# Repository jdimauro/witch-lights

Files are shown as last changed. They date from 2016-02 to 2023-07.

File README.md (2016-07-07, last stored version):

# Witch Lights

The Witch Lights are an interactive light art installation, meant to be seen outdoors at night. 

The documentation and code are currently under construction, so they may change without notice. 

## Overview

This project creates a set of [ghostly lights][vid0], which come out of the woods when you approach them and jump from tree to tree. 

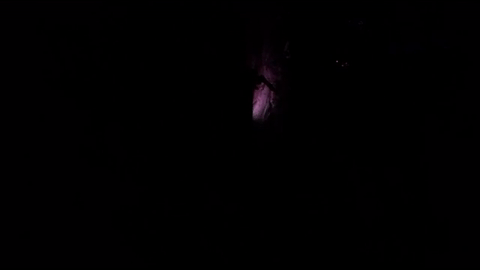
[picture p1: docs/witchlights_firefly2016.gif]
Animation Demo 1


Animation Demo 2

Imagine: as you walk through the unlit path, a tiny purple faerie jumps out of the underbrush, coiling about trees and floating overhead. It zips ahead of you, but pauses, flickering, while you catch up. It then takes off again, remaining always just out of reach, until you reach the end of their territory, where they vanish back into the woods. As you pass by where they disappeared, the lights jump out again, heading back the other way, daring you to chase them.

<iframe src="https://player.vimeo.com/video/153011114" width="500" height="889" frameborder="0" webkitallowfullscreen mozallowfullscreen allowfullscreen></iframe> 

[Here is a video][vid1] of an installation of the lights using a single five-meter LED strip (taken at twilight so that the hardware is visible):

[vid0]: https://vimeo.com/153011114#t=2s
[vid1]: https://vimeo.com/153011829

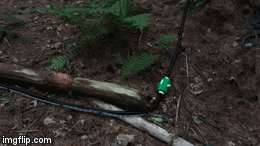
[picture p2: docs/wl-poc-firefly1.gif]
Proof of Concept - Firefly 2015


<iframe src="https://player.vimeo.com/video/153011829" width="500" height="281" frameborder="0" webkitallowfullscreen mozallowfullscreen allowfullscreen></iframe> 

The design of the lighting system is modular, so it can be used with any length of NeoPixel strip. The current configuration of the project uses five 30 pixel-per-meter NeoPixel strips, each one five meters long, for a total of 750 pixels. 

As you can see in the above video, the design uses waterproof conduit, connected to custom, modular connectors, which house the sensors and connect the NeoPixel strips to their power and data lines. 

At the beginning and end of the installation are passive infrared (PIR) motion sensors, which trigger the lights to appear and then zip away in the opposite direction of the triggered sensor. 

## Firefly 2016

The Witch Lights were exhibited at the Firefly Art Festival in Vermont, from June 29th through July 4th 2016. 

[Here is a video of the Witch Lights in action at the festival][vid2]. 

[vid2]: https://vimeo.com/173539041

### Photos

The lights were installed on a winding path through the woods, near the rear entrance to Library Camp. 

Electronics package and beginning of LED strips

The lights wound up around a tree, and then snaked through a tree stump.

Lights wrapped around tree stump

The conduit provides structure for the LED strips, and can be used to create spirals and loops in mid-air. 

Spiral segment of conduit and LEDs

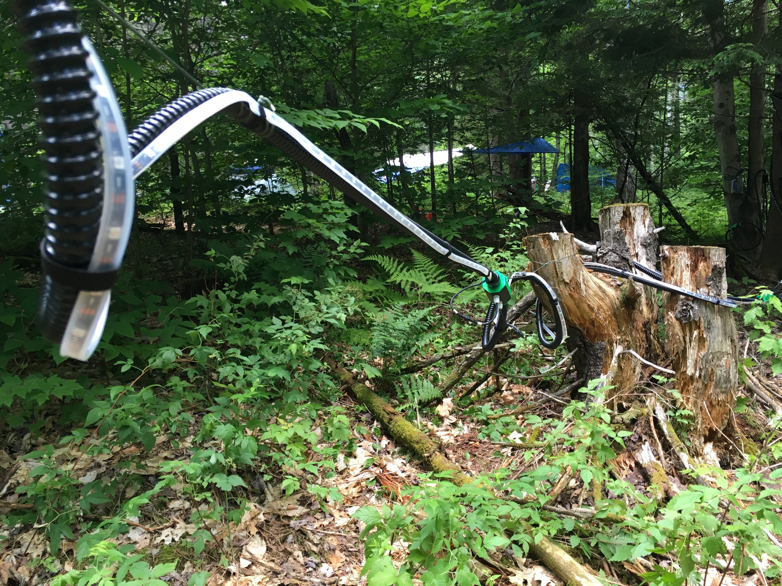
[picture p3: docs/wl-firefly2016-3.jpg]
Spiral and stump


The lights terminated by ducking behind a tree, so that they appear to hide behind a tree and vanish, or come out from behind the tree if activated by the motion sensor on this end (shown in green). 

Motion sensor and terminus

### Reception

The reaction to the Witch Lights was hugely enthusiastic and positive. Many attendees reported stopping and watching the lights, entranced, on their way through the path. Firefly's location feels like a magical forest, and the addition of a purple faerie that leads you down one of the paths felt like a natural thing to encounter in the dark. 

## Challenges

This is an advanced project. It involves building a weather resistant wire rig with 3D-printed sensor housings, which itself requires a great deal of soldering, assembly, cable pulling, and testing. The modular nature of the design means you will have to take your intended installation environment into account and make your own decisions about the length and number of LED strips and connectors you plan to use. 

### Important Caveat

Even though the rig is designed to be weather resistant, it has not yet been tested in heavy rain or other wet conditions! Please take care and consider that this project uses electricity outdoors. **Proceed at your own risk.** 

## Bill of Materials

Components: 

* [Heat-Shrink, various sizes](https://www.adafruit.com/products/1649)
* [Heat-Shrink, 1/4"](http://www.mouser.com/ProductDetail/3M-Electronic-Specialty/EPS300-1-4-48-Black-Bulk/)
* [Heat-Shrink, 1/2" (optional)](http://www.mouser.com/ProductDetail/3M/FP301-1-2-48-Clear-Bulk/)
* [Ribbon Cable, 100' spool](http://www.mouser.com/ProductDetail/Amphenol-Spectra-Strip/135-2801-010/)
* [Hookup wire, 22AWG, various colors](https://www.adafruit.com/products/1311)
* [M3 socket-head machine screws, 8mm length](http://www.mcmaster.com/#socket-head-cap-screws/=10zugcn "McMaster-Carr") (box 100)
* [Heyco 8452 3/4" conduit](http://amazon.com/Heyco-8452-BLACK-LIQUID-TUBING/dp/B001BQ029G/) (100' spool)
* [PIR Motion Sensor](https://www.adafruit.com/products/189) (2)
* [micro-USB power adapter](https://www.adafruit.com/products/1995)

Arduino Enclosure components:

* [Arduino Due](https://www.adafruit.com/products/1076)
* [Waterproof Enclosure (Large)](https://www.adafruit.com/products/905)
* 3D-Printed `wl-arduino-mount.STL` circuit board mount
* M3 machine screw, 20mm (?)
* ??mm plastic standoff
* [Adafruit Perma-Proto 1/2 board](https://www.adafruit.com/products/1609) 
* [Screw Terminals, 10-pin](https://www.adafruit.com/products/2234) (2)
* [74AHCT125 Logic Level Shifter IC](https://www.adafruit.com/products/1787)
* [16-pin IC socket](https://www.adafruit.com/products/2203)
* [4700uF capacitor](https://www.adafruit.com/products/1589)
* [2.1mm breadboard-friendly DC power jack](https://www.adafruit.com/products/373)
* [2.1mm male DC power adapter](https://www.adafruit.com/products/369)
* [10k ohm resistors](https://www.adafruit.com/products/2784) (2)
* [Adafruit PowerBoost 1000 board](https://www.adafruit.com/products/2465)
* [4400 MAh LiPo battery](https://www.adafruit.com/products/354)
* [Waterproof Panel-Mount on/off switch](https://www.adafruit.com/products/916)

You will need one set of these parts per 3D-printed enclosure (see instructions):

* [Heyco 8404 3/4" conduit fittings](http://smile.amazon.com/Heyco-BLACK-STRAIGHT-CONNECTOR-package/dp/B00LWLMX7O/) (2)
* [Heyco 3261 3/4" waterproof washers](https://amazon.com/Heyco-3261-SANTOPRENE-SEALING-package/dp/B00PKLGC8S/) (2)
* [Adafruit Perma-Proto 1/4 board](https://www.adafruit.com/products/1608)
* [Screw Terminals, 2-pin](https://www.adafruit.com/products/2234) (3)
* [Screw Terminals, 3-pin](https://www.adafruit.com/products/2234) (2)

You will need one set of these parts per NeoPixel strip (see instructions):

* [NeoPixel 30 LED/meter strip, black](https://www.adafruit.com/products/1460), 5 meters
* [4-pin waterproof cable](https://www.adafruit.com/products/744) (2)
* [waterproof cable gland](https://www.adafruit.com/products/762) (2)

Optional NeoPixel Reel Test rig:

(You can optionally build a dedicated Arduino rig to test your NeoPixel strips and keep it handy for field testing, or you can borrow components from the rest of the installation.)

* [Arduino Uno](https://www.adafruit.com/products/50)
* [Adafruit Perma-Proto 1/4 board](https://www.adafruit.com/products/1608)
* [Screw Terminals, 3-pin](https://www.adafruit.com/products/2234) (2)
* [4-pin waterproof cable](https://www.adafruit.com/products/744)

Tools:

* 3D Printer
* Wire Strippers
* Heavy-duty scissors or shears
* Needle-Nose Pliers
* Soldering Iron
* Multimeter
* 2.5mm Hex Wrench
* 1.5mm or 1.3mm flathead screwdriver
* Heat Gun
* 16mm hole saw
* 1" hole saw
* Third-hand tool
* panavise circuit board vise
* label printer (optional)
* cable snake
* wooden dowel (for running cable)
* stick-on velcro dots
* thin velcro cable-management strips

## 3D Printing

For best results, print all components in black or green plastic. 

The enclosures are designed to be easily printable on any commercial 3D printer; they were printed on a first-generation Makerbot Replicator in PLA and ABS plastic, and have been successfully tested on Makerbot Replicator 2, Printrbot, and Lulzbot printers.

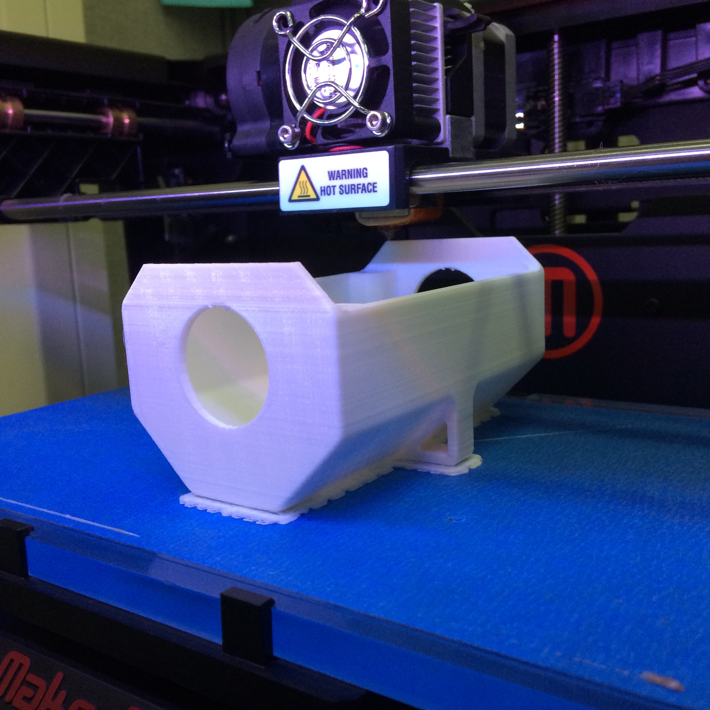
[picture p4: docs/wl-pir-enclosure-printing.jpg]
Printing an enclosure on a Makerbot Replicator 2


The purpose of the enclosures is threefold: 

1. House passive infrared (PIR) motion sensors and connect their data lines to a ribbon cable reaching back to the arduino enclosure.
2. Connect NeoPixel strips to their data lines on the same ribbon cable, or to each other (if using multiple strips).
3. Connect NeoPixel strips to the power and ground lines at both their origin and terminus, as recommended in the [Adafruit NeoPixel Uberguide][uber], so that the lights don't dim and turn brown as they extend far away from the arduino enclosure.

[uber]: https://learn.adafruit.com/adafruit-NeoPixel-uberguide

### Printing Enclosures

First, download the files in the `STLs` directory. 

Next, before you jump in to printing and assembling the enclosures, you should make a thumbnail sketch of the installation, so that you know how how many of which components to make, and how they will be assembled. 

For example, here is a diagram of a naive installation, with two PIR sensors and one NeoPixel strip:

    A------P========================================P

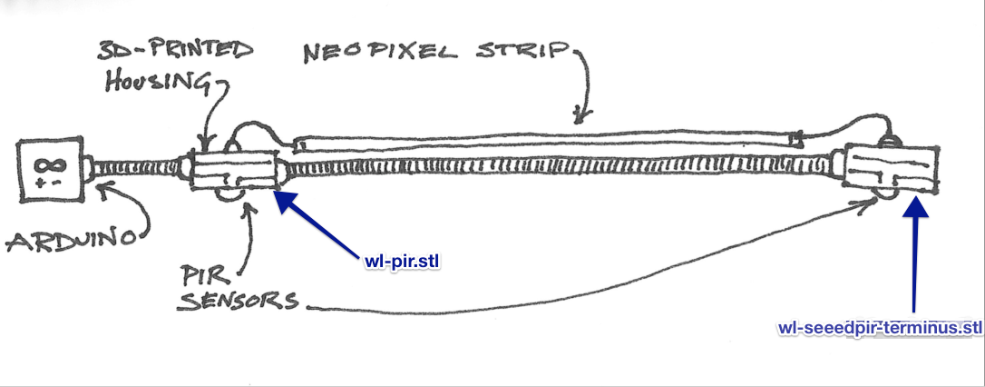
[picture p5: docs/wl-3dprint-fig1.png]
3D Printing Instructions Figure 1


This configuration uses the PIR enclosures to connect the NeoPixels to power and data. 

I *do not* recommend you use this configuration, because the PIR sensors have a very, very long range, and so you won't get reliable results. As you approach one end of the strip, the other sensor may trip, and that ruins the illusion of the lights. 

Instead, I recommend a slightly more complex configuration as the simplest possible arrangement: 

    A-------P------N====================================N------------P

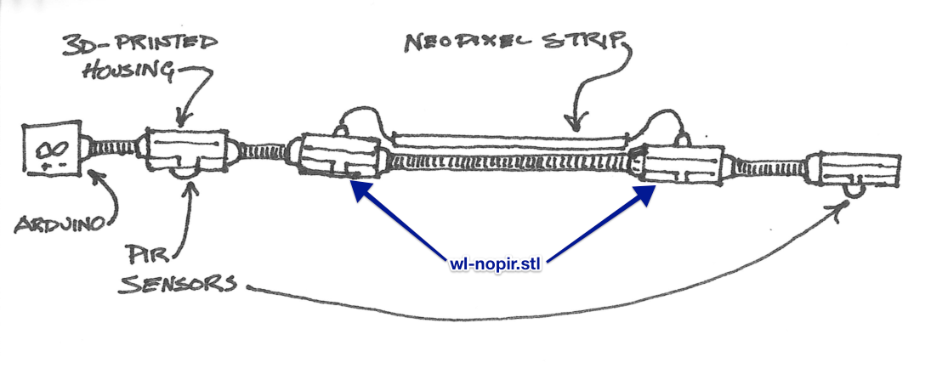
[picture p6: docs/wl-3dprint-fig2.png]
3D Printing Instructions Figure 2


To make this configuration, you will need two `wl-pir.stl` enclosures, one `wl-nopir.stl` enclosure, and one `wl-terminus.stl` enclosure. This will space out the sensors and make it so that they trigger at the right times, making the lights chase back and forth between the sensors. 

Please see the second video in the Overview section if you want to see what this configuration looks like in the wild. 

If you want to lengthen the lights, just add another `wl-nopir.stl` enclosure to connect another NeoPixel strip, like so: 

    A-------P------N======================N=====================N------------P

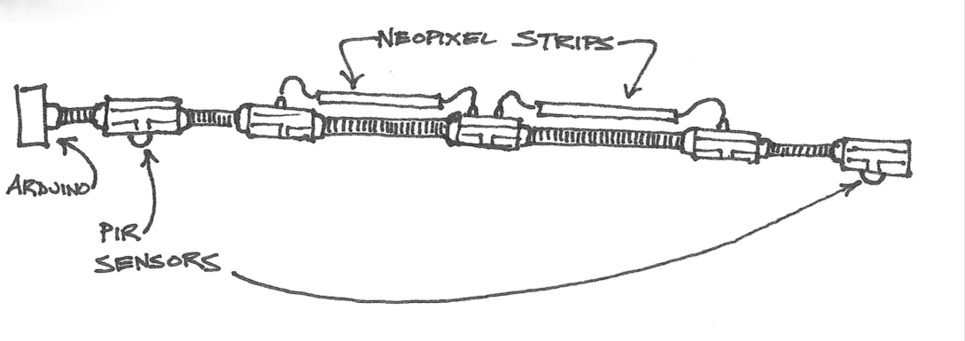
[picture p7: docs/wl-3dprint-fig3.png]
3D Printing Instructions Figure 3


For each installation you build, you will want one `wl-pir.stl` enclosure, one `wl-terminus.stl` enclosure, and one more `wl-nopir.stl` enclosure than the number of NeoPixel strips. 

If you want to make things a bit more complex (why not?), you can space out the NeoPixel strips with areas of blank conduit, which will lengthen the area you can cover with the lights, like so: 

    A-------P------N==================N----------------N==================N------------P

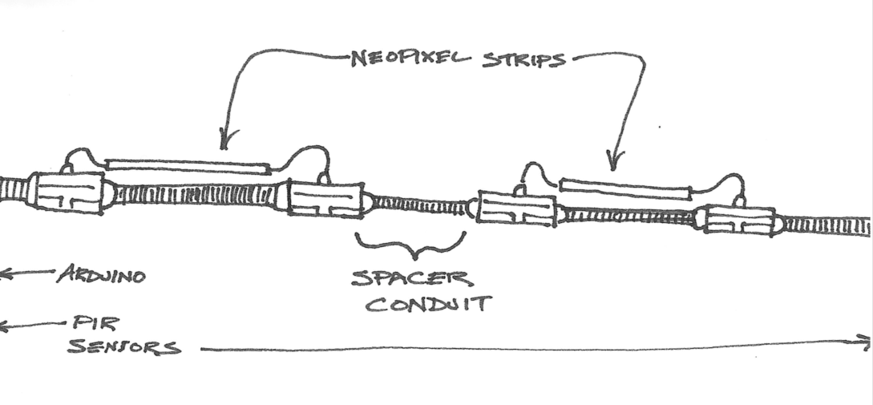
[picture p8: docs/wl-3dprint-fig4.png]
3D Printing Instructions Figure 4


In the end, I recommend sketching your intended installation and then counting the number of each enclosure you will want. Once you do that, start printing your enclosures; they take an average of 5-6 hours each, so while they print you can start figuring out which lids you want to print. 

### Printing Lids

Complexity is the price you pay for a modular system. And this system is very modular, so of course there's an extra step: you have to determine which lids to print. 

Take a look at your sketch from earlier. Let's say you're making a two-strip installation, like so: 

    A-------P------N======================N=====================N------------P

3D Printing Instructions Figure 3

There are three possible lids to print, with zero, one, or two cutouts for waterproof cable glands. That's where the waterproof cables will come out of the enclosures and connect to the NeoPixel strips. 

For each enclosure, look at the diagram. Is there a NeoPixel strip touching the enclosure? If not, print a lid with 0 holes. 

If there's one NeoPixel strip touching the enclosure, print a lid with 1 holes. And if there are two strips touching (like the middle enclosure in the above diagram), print a lid with 2 holes. 

The rule of thumb is, **print a lid with the same number of holes as the number of NeoPixels this enclosure needs to interface with**. 

### Printing Arduino Mount

Print one of the `wl-arduino-mount.STL` file and place it with the components for the arduino enclosure. 

## Wiring and Soldering

The physical layer of this project is composed of the Arduino Due, a power circuit, ribbon cable running through conduit, terminal circuit boards in the enclosures, and waterproof cabling for the NeoPixel strips. 

This part of the project has four steps: 

1. Wire and solder the interface board for the Arduino
2. Solder the power elements to the Arduino interface board
3. Wire and solder the terminal boards
4. Connect the NeoPixels to 4-pin waterproof cables and test them

### Arduino Interface Board

The Arduino Due is a 3.3v microcontroller, but the NeoPixels need 5v on the data line. So we'll need to use a logic level shifter, which will take the data signals sent by pin 6 of the arduino and amp them up to 5 volts. 

And since we're using ribbon cable to send the power and data signals down the length of the installation, we probably want to use screw terminals to connect those wires to the arduino. 

Therefore, you're going to need to make a circuit board for the Arduino Due so it can talk to the NeoPixels and hook up to the ribbon cable. 

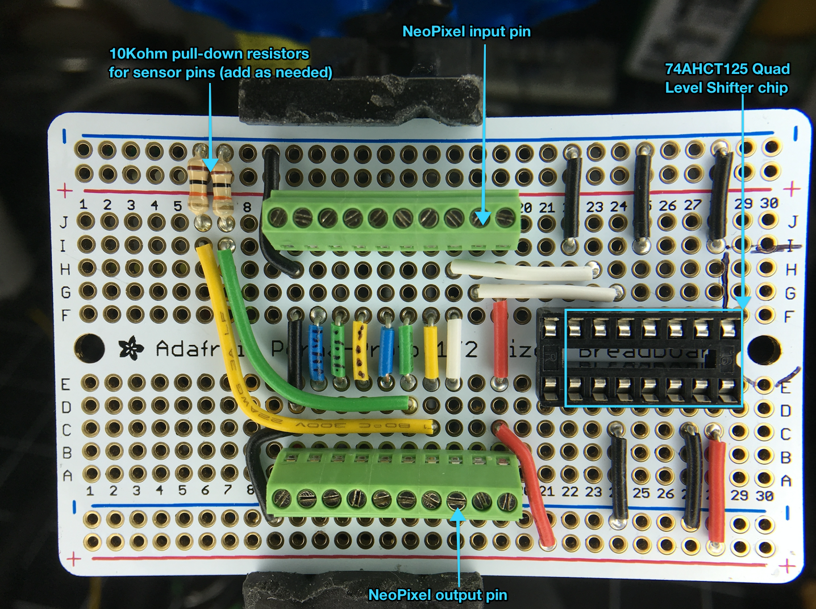
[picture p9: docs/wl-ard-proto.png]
Witch Lights - Arduino Interface Board


Use an Adafruit Perma-Proto Half-Size board and solder a pair of 10-pin screw terminals to it, and wire it up as shown in the photograph above. 

The 74AHCT125 chip is installed so that the little "U" cutout faces to the right of the board, matching the little "U" cutout in the socket. 

(TODO: detail shot of 74HCT125 chip)

It's time to connect the Arduino Interface Board with the Arduino Due itself. We're going to use the 20" M3 screw and stand-offs to mount the board underneath the Arduino. 

(TODO: detail shots of the Arduino mounted to the interface board)

Use hookup wire to connect the arduino's headers to the top part of the circuit board as follows:

* Connect the *red* terminal (power) to the "5V" pin
* Connect the *rightmost white* terminal (NeoPixel data) to digital pin 6 (refer to the detail photo above)
* Connect the *green* terminal (PIR sensor 0) to digital pin 3
* Connect the *yellow* terminal (PIR sensor 1) to digital pin 4
* Connect the *black* terminal (ground) to the "GND" pin

**Be certain to wire the data line from pin 6 to the indicated terminal in the photo, and connect the white data line cable to the other indicated terminal on the other side; if you hook them up incorrectly, the NeoPixels will light up erratically or not at all.** 

(TODO: detail shot of the Arduino hooked up to the circuit board)

### Power

Once the Perma-Proto board is wired up like in the photo above, it's time to attach the 4700uF capacitor, and the 2.1mm power connector. 

(TODO: Get current photo of capacitor and power connector on perma-proto board)

Wire up the 5V power supply from the battery board to the 2.1mm connector on the arduino circuit board. Optional power switch installed in the side would go between the power line from the battery board and the arduino circuit board. 

### Terminal Boards

For each 3D-printed enclosure you make, you're going to need a terminal board. These are made using Adafruit Perma Proto 1/4 size boards, 3-pin terminals, and 2-pin terminals.

You'll probably want to strip and install the wires first, like so:

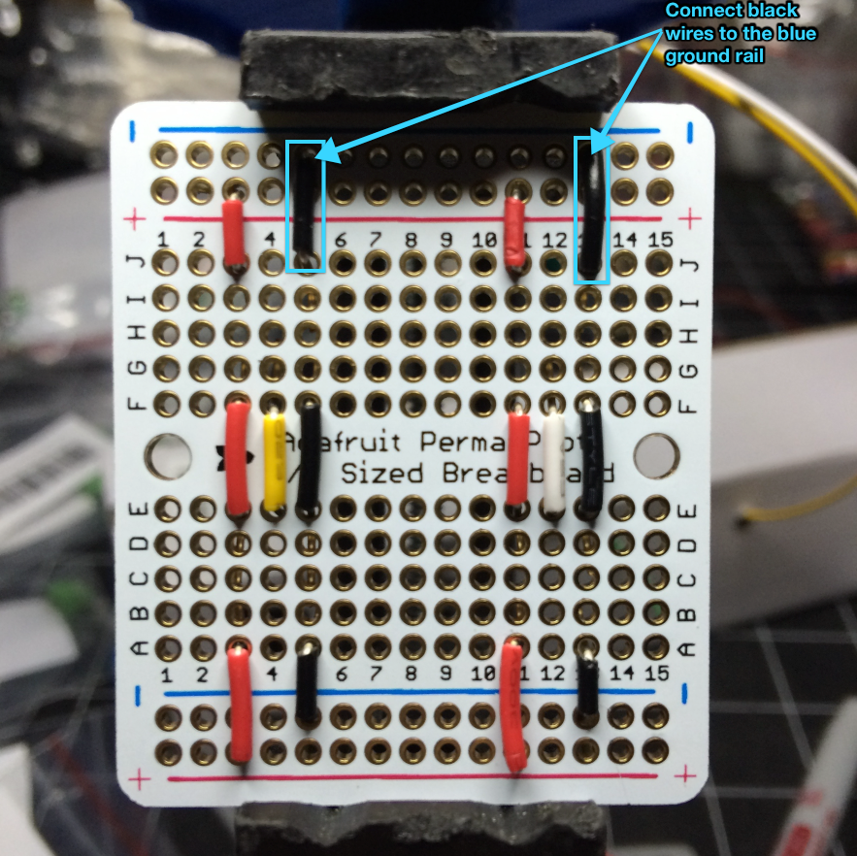
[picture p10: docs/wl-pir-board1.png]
PIR Terminal Board Detail 1


Once those are soldered, use masking tape to hold the terminals on to the board, and solder them on, like so: 

PIR Terminal Board Detail 2

Use the continuity tester feature of your multi-meter to test for short circuits and to ensure that the power, data, and ground lines pass properly through from one side of the board to the other. 

Once you're certain you have a good board, do yourself two small favors:

1. Use a 1.5mm flathead screwdriver to loosen _all_ of the terminals; they ship tightened all the way, and it's far easier to loosen them now than it will be in the field
2. Draw an arrow on the board as shown. This indicates the direction of the data flow away from the Arduino. When it's time to install the boards in their enclosures, you'll install them so that the arrow points away from the Arduino, and that will save you heartache and troubleshooting later. Trust me. 

### NeoPixel Cables

You'll have to solder and heat-shrink one end of a waterproof 4-pin cable to each side of the NeoPixel strip, so that we have a weatherproof way to connect the strips to the 3D-printed enclosures. Once you do that, you'll need to test the strip to make certain there are no problems with your soldering job. 

Make sure you always use the same cable gender for input and output, or else it'll get really confusing. I used a label printer to make an arrow pointing in the direction of the NeoPixel data flow (as indicated by arrows on the NeoPixel Strips), and labeled all the waterproof cables before starting assembly. 

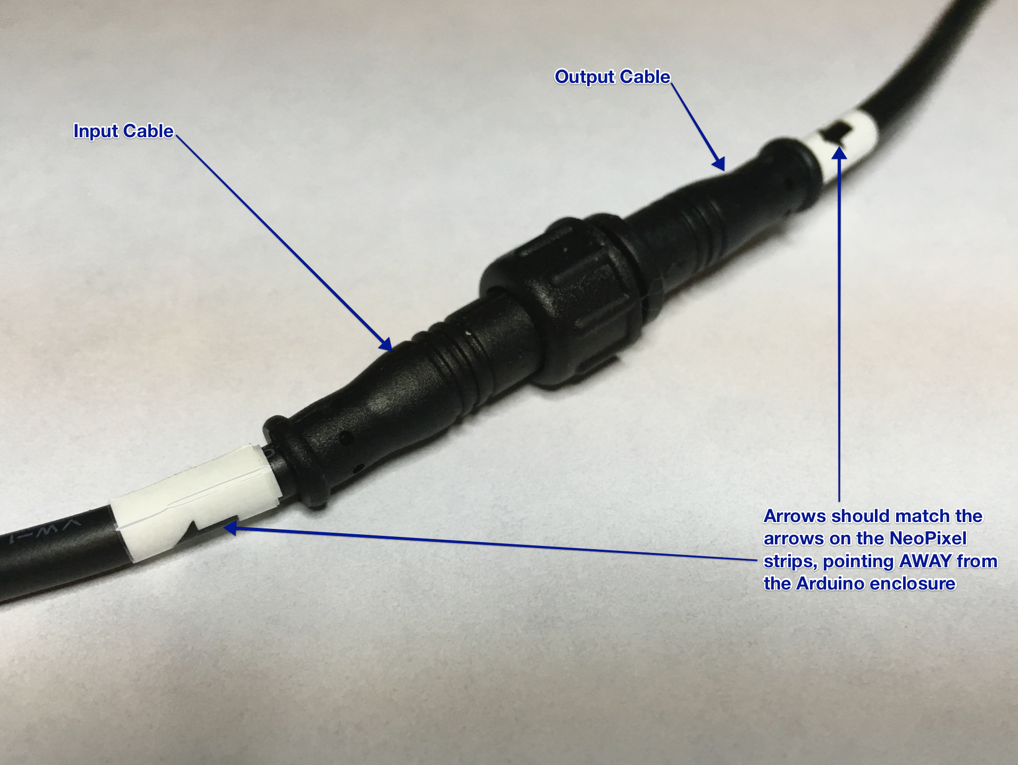
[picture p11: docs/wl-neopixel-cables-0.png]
Arrows on NeoPixel Cables


Use a third-hand tool to hold the waterproof cable and the end of the NeoPixel strip. Use your wire strippers to take some more insulation off the red, black, and white wires coming out of the waterproof cable, and clip the yellow wire short; we won't be using it. 

Put a length of 1/4" heat shrink tubing on the waterproof cable, and put some thin heat-shrink tubes on the red, white, and black wires coming from the NeoPixel strips. Optionally, slide some 1/2" heat-shrink tubing over the end of the NeoPixel strip itself. 

Tin the wires a little bit by heating them up with a soldering iron and brushing them with a bit of solder. Then twist the black wires together, and use the soldering iron and a bit more solder to splice them. Repeat the process with the red and white wires, like so: 

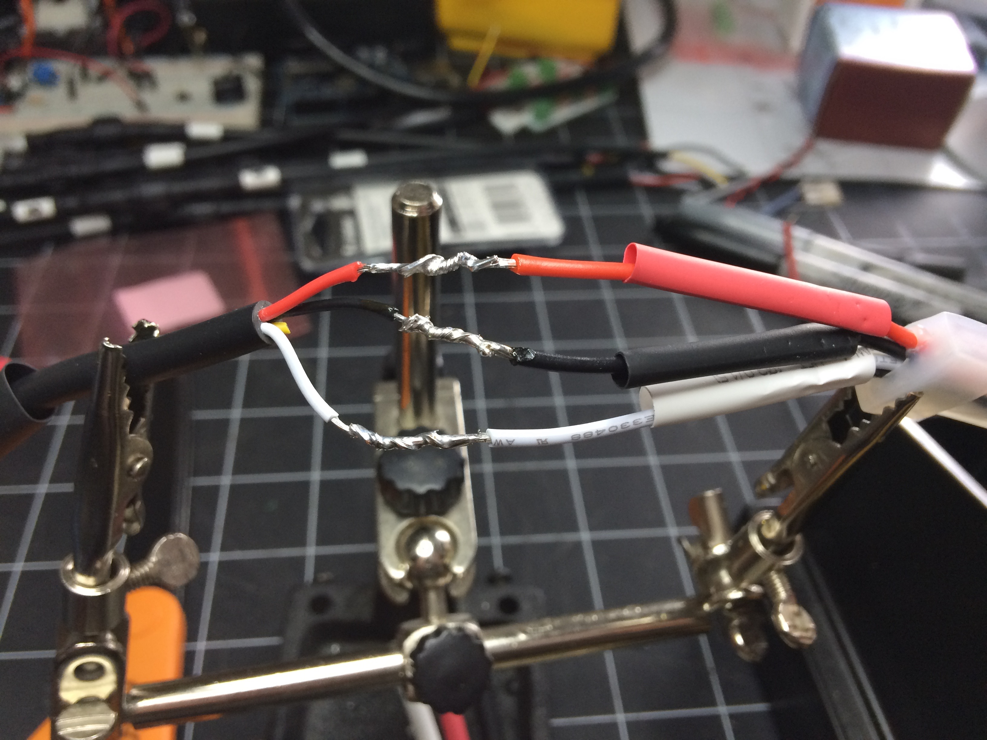
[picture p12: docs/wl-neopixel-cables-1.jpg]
Soldering wires


Use the continuity tester on your multimeter to test that you have continuity from the pins on the cable to the bare spliced wires. You may have to use some trial and error to figure out which pin goes to which color of cable; I always forget and have to poke around. 

Then slide the thin heat shrink tubing over the bare soldered wire. Use a heat gun to shrink the tubing over the wires. 

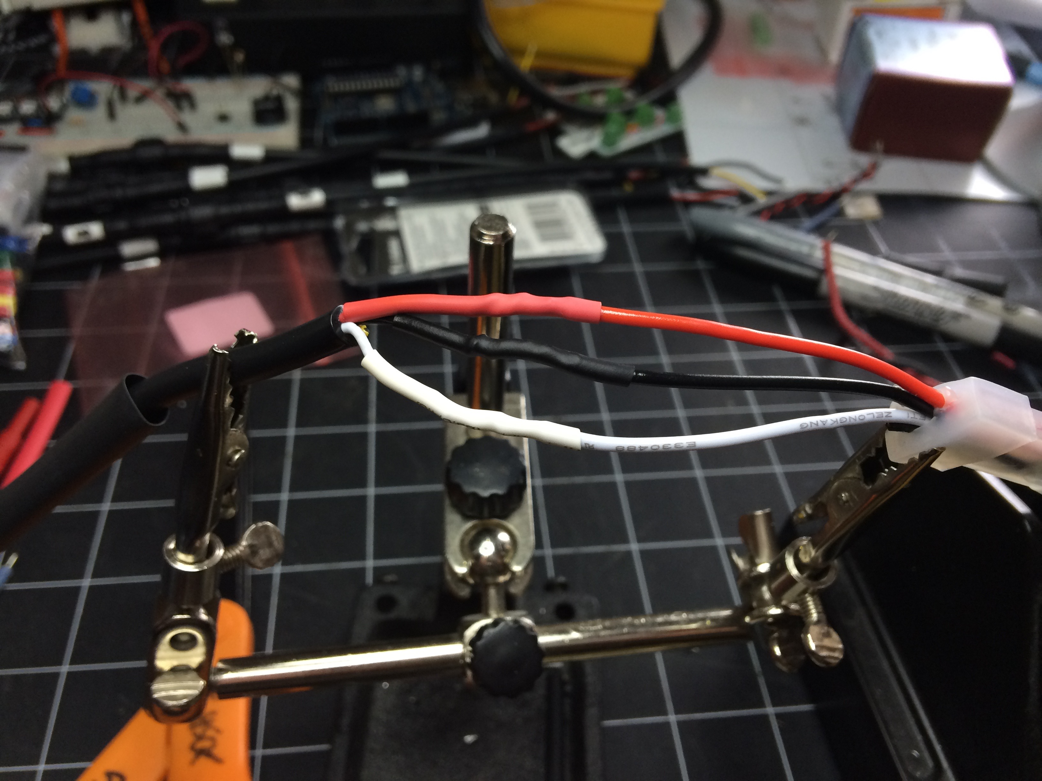
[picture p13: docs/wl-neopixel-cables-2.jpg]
Heat shrink on the spliced wire


Now, slide the 1/4" heat-shrink tubing over all the colored wires, up to the base of the silicone sheath of the NeoPixel strip.

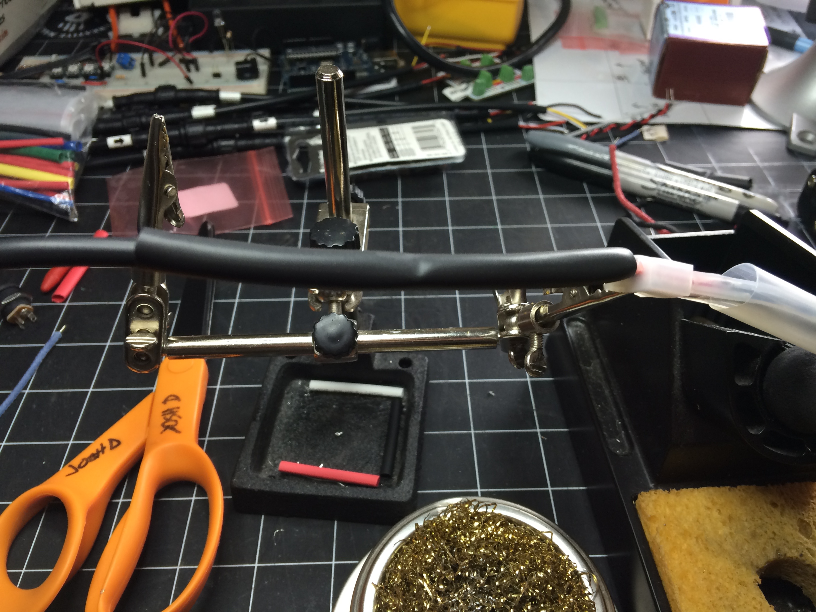
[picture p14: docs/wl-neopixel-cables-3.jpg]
Heat-shrink over the colored wire


Use a heat gun to shrink the tubing and seal the wires.

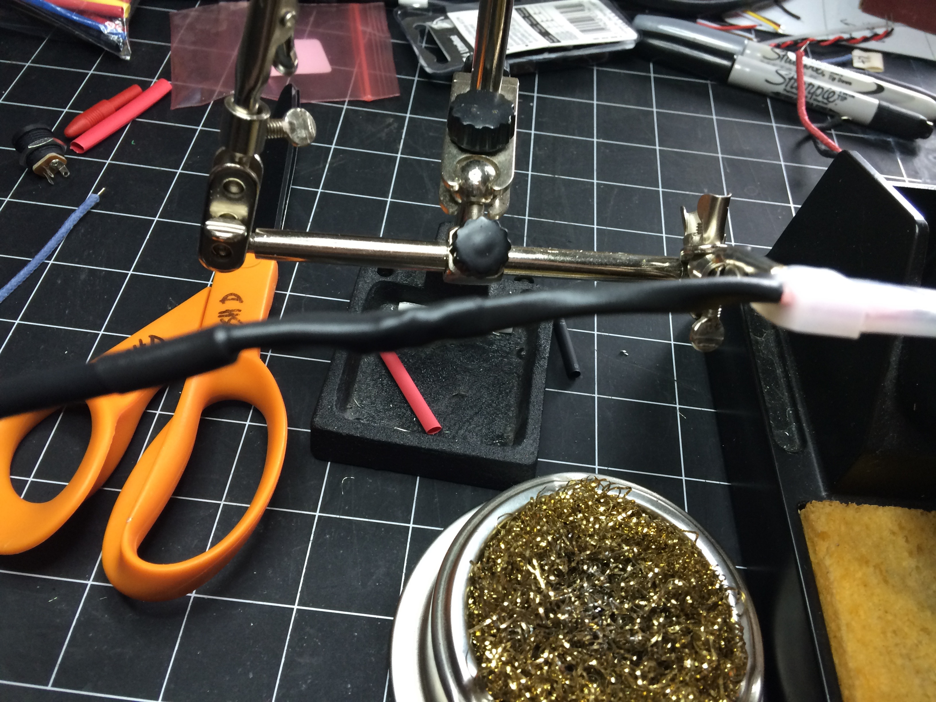
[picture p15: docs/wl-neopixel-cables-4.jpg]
Heat-shrunk wires


And now, if you have the 1/2" heat shrink over the NeoPixel strips, slide it over the point where the heat-shrink abuts the silicone sheath.

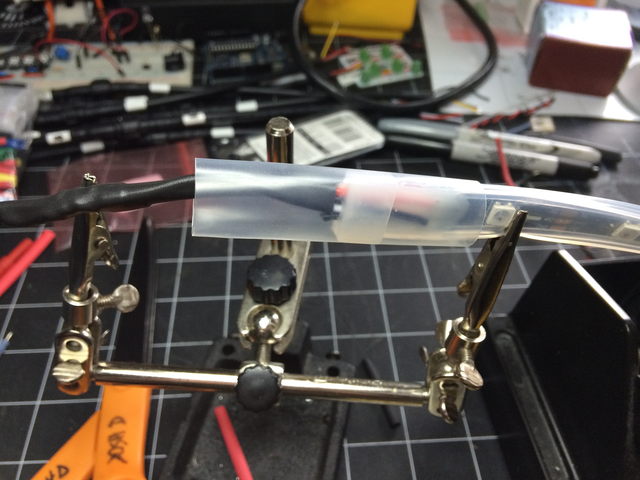
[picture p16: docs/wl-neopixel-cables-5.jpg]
Optional final heat shrink


Use a heat gun to shrink that down and reinforce the joint. 

Repeat this process on the other end of the NeoPixel strip with the other end of the waterproof cable. And repeat again for each NeoPixel strip you use. 

#### Test NeoPixel Reels

I used an Arduino Uno to create a dedicated test rig for NeoPixel reels after soldering them; you can either do this, or load the `NeoPixel_Reel_Test` sketch on the Arduino Due. Either way, borrow one of the enclosure terminal boards (or make an extra one), and connect the "out" end of a waterproof cable to it, and hook the power and NeoPixel data lines to the Arduino. 

The `NeoPixel_Reel_Test` sketch runs alternating colors down the length of any NeoPixel 5-meter reel connected to it. The purpose of this test is to make certain there are no problems with the solders on the NeoPixel reel and 4-pin waterproof cables. 

Use the reel tester after you solder cable to every NeoPixel strip, then roll up the NeoPixel strip onto its reel and put it away in its silver bag; mark "Tested" and the date on the bag. 

## Software

The current iteration of the software is in the directory marked `witch-lights-classic`. This code successfully handles two PIR sensors and will trigger a different sprite animation when one or the other sensor is tripped. 

### Required Libraries

The Witch Lights run Adafruit NeoPixels, and therefore require the [Adafruit NeoPixel Library][neolib]. Follow the instructions in the README to install the library in your Arduino environment. 

[neolib]: https://github.com/adafruit/Adafruit_NeoPixel

If you have trouble installing the library, or if you've never installed an Arduino library before, please check out the [Adafruit Guide to Arduino Libraries][agal] for in-depth instructions. 

[agal]: https://learn.adafruit.com/adafruit-all-about-arduino-libraries-install-use

### Program the Arduino

Download `witch-lights-classic` and use the Arduino IDE to upload the code to your Arduino Due. 

If the Arduino is properly wired to its terminal board, you should be able to use the screw terminals to connect directly to a NeoPixel strip. Power on the Arduino and use a jumper cable to make the green terminal pin go high; you should see the purple faerie lights race away down the NeoPixel strip. 

### Adjust the Code

Once you have an animation running, you can adjust the variables in the code to tune the speed and frequency of the animation. All of the variables you need to adjust are declared at the beginning of the file: 

`N_LEDS`: Each NeoPixel strip has 150 LEDs. Change this value to equal the total number of LEDs in your project. 
IMPORTANT: As you increase the number of LEDs past 150, the animation speed will slow, and you will have to reduce the "interval" variable to compensate.

`interval`: Increase this to make the sprite's animation begin more slowly. Reduce it to make the sprite's animation begin more quickly. As you add LEDs to your project, you will have to adjust this variable.

`minInterval`: If your project has a smaller number of LEDs (150 or 300), you may need to increase this variable to 1 or 2, in order to make the animation appear natural. If you have more than 300 LEDs, leave it at 0. 

`hoverLowerDistance`: This adjusts how frequently the sprite stops and hovers. Decrease it to make the sprite stop more often. Increase it to make the sprite run for longer distances before it pauses to hover. 

`hoverLowerTime`: Adjust this variable, along with `hoverUpperTime`, to change how long the sprite "hovers" for; the higher the values, the longer the sprite will hover. A value of 5 means that the sprite will run through its "sparkle" animation cycle 5 times. The greater the difference between the two values, the greater the random variation in how long the sprite pauses to sparkle for. You will need to tune this value after you've made changes to any of the above variables. 

The process for adjusting the animation goes like this: 

* Set the `N_LEDS` first.
* Let the animation run a few times, watching the sprite as it _starts_. The animation should be a slow but smooth launch. 
* If the speed at start feels slow or choppy, decrease `interval`. If the sprite zips away too quickly, increase `interval`.
* Use the `hoverLowerDistance` variable to tune how often the sprite stops. I recommend laying the strip on the floor at full length, and walking alongside it. You want the sprite to go just a bit faster than you would walk at a natural pace. 
* Fine-tune the `hoverLowerTime` and `hoverUpperTime` variables. This is a matter of feel; you want the amount of time the sprite pauses to feel natural. It's a matter of "you know it when you see it".

TODO: install knobs and map them to the `interval` and `hoverLowerDistance` variables to allow for on-site fine tuning without the need for a laptop.

## Final Assembly and Use

You're ready to put the whole thing together! At this point, you should have:

* 3D-printed enclosures
* 3D-printed arduino mount
* Terminal boards (1 per enclosure)
* Arduino and its terminal board, with the software uploaded and adjusted
* NeoPixel reels with cabling (tested)
* All the remaining components on the Bill of Materials, such as conduit, ribbon cable, etc. 

Here's the process you're going to follow: 

1. Assemble the Arduino Enclosure, and build the power circuit.
2. Cut conduit to the proper lengths, and pull ribbon cable through them for the wiring harness.
3. Install the terminal boards in the 3D-printed housings
4. Install the PIR sensors in the sensor housings
5. Connect the ribbon cable to the terminals on the boards, and test continuity
6. Wire the NeoPixel interface cables into the housings and connect the NeoPixels
7. Run final testing on the assembly

### Arduino Enclosure and Power

In this step, you will assemble the Arduino Enclosure, and construct a power circuit, with battery connector and power switch. 

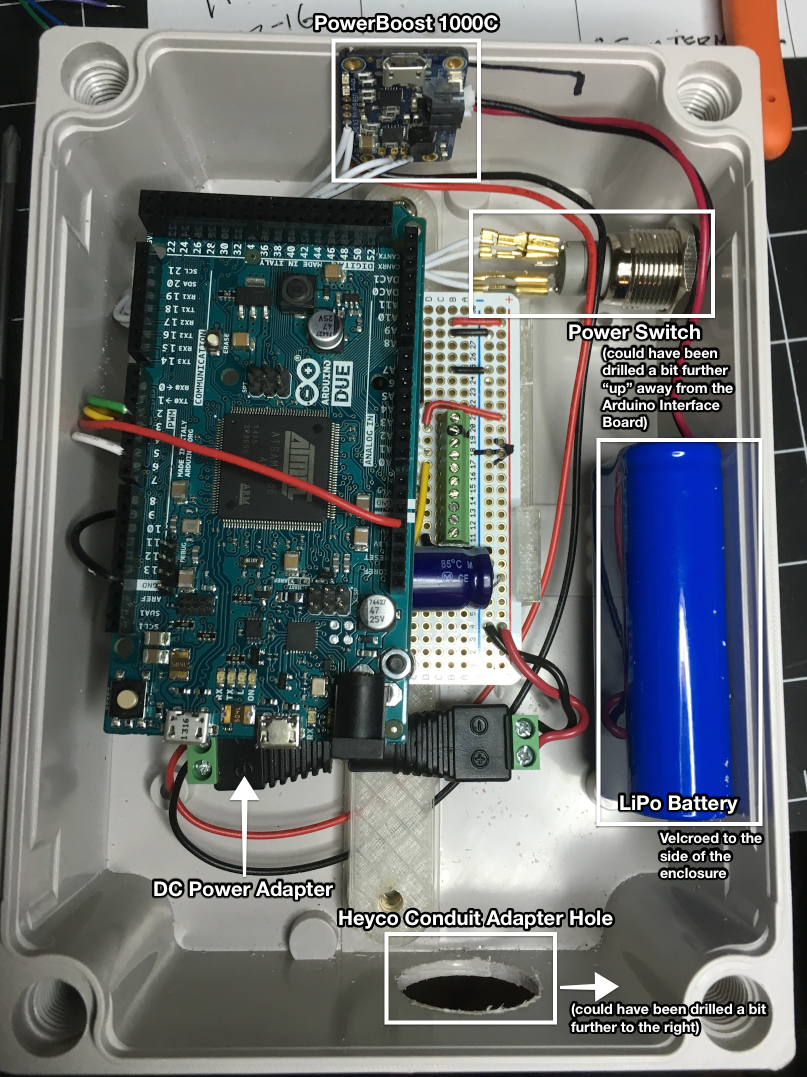
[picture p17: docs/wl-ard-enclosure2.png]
Enclosure with battery pack


Use a compass to mark a 1" circle on the narrow end of the enclosure, where you want the Heyco connector to go. This will be the "bottom" of the enclosure. (See the photograph above for guidance on where to mark the hole.) Mark the center of the circle. 

Drill a pilot hole with a 1/8" drill bit first, and then use your hole saw to cut the 1" hole in the enclosure. You'll need to use a file or rough sandpaper to open the 1" hole up enough to insert a Heyco connector. 

Slide the half-size perma-proto board into the printed `wl-arduino-mount.STL` piece, then mount it in the enclosure using the M4 screws provided when you unwrapped the enclosure. 

Now for the power circuit. First, we need to place the switch. 

Use a 16mm hole saw to cut a hole in the side of the enclosure; make sure to position it so that the switch's terminals won't interfere with the arduino's proto board. Screw the panel-mount switch into the hole (and don't forget the rubber O-ring). 

Solder leads to the `GND` and `EN` pins on the PowerBoost 1000C, and solder leads to the `5V` and `GND` pins, as well as the `+` and `-` pins. Run `5V` and `GND` down to the power plug on the proto-board, and screw them into the terminals of the male DC adapter. Plug it into the proto-board. 

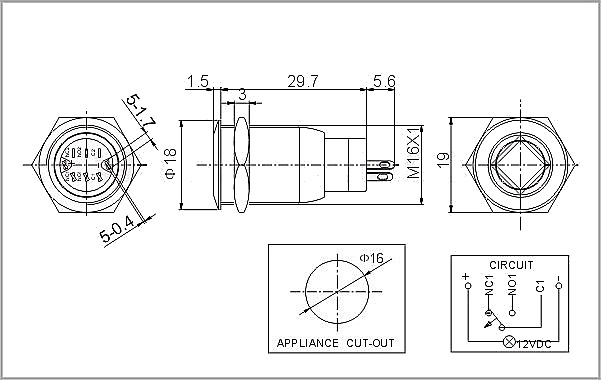
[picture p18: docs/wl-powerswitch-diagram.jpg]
Diagram of the on/off panel-mount power switch


(See the [product page for the power switch](https://www.adafruit.com/products/482) for details)

Run the `+` and `-` pins to the (outer) LED terminals on the power switch. Make sure to connect them to the `+` and `-` terminals of the switch, respectively. Connect `GND` and `EN` to the terminals labeled `NC` and `C1`. ("Normaly closed" and "Common contact".) 

What you are doing is, you're closing the circuit between `EN` and `GND` on the PowerBoost 1000C. That tells the PowerBoost to turn off. When the on/off switch is pressed, it _opens_ the circuit, and the PowerBoost gets the message to turn on, which supplies power to both the Arduino and the LED ring around the switch itself. 

Connect a battery to the PowerBoost 1000C. When you press the on/off switch, the switch should light up, and the Arduino should power on. If not, check your connections to the terminals on the switch. It's very easy to mix up the `+` and `-` terminals for the switch's LED, and if you do, the PowerBoost won't turn on. 

Position the battery as shown in the photograph above, and carefully use stick-on velcro dots to attach it to the inside of the enclosure. 

At this point, you have a functional brain. You can charge the battery with the lid open by plugging the PowerBoost 1000C into a [micro-USB power adapter](https://www.adafruit.com/products/1995), and the system will continue to run as it charges. 

You should still also have access to the programming port on the Arduino, in case you need to reprogram it for upgrades or bug fixes.  

### Cut Conduit and Pull Cable

This is where you refer back to your plan. How many NeoPixel strips are you going to use? How are they spaced? You should have a thumbnail sketch. 

If you don't, refer back to the **Printing Enclosures** section above, sketch out your length of witch lights, and get started printing the enclosures you're going to need. 

For each NeoPixel strip, you're going to need five meters of conduit. 

If you plan to have a spacer between your NeoPixel strips, you're going to need conduit for that, as well. 

No matter what kind of configuration you sketched out earlier, you're going to put a five meter conduit between the Arduino enclosure and the first PIR sensor. This gives you enough flexibility to find a safe place to install the Arduino and then position the PIR sensor strategically to sense motion at the right place. 

Measure out five meters (16.4 feet) of conduit and cut it with your heavy-duty scissors or shears. Find two Heyco connectors. Unscrew the big dome-like component and slide it over the conduit, then swedge the conduit into the end of the connector. Screw the dome back on, tightly. This seals the conduit onto the connector. Repeat for the other end. 

Congratulations, you've got your first length of conduit ready to go. 

Once you've got your conduit set, it's time to pull ribbon cable through it. You're going to want a friend to help you with the next step. 

Extend your cable snake into the conduit and keep unreeling it until it pokes through the far end of the conduit. Then your friend can pinch the cable and stuff it through the little hole on the end of the cable snake, or use tape to attach it. Now have your friend put your wooden dowel through the hole in the ribbon cable spool, and hold either end of the dowel as you _slowly and carefully_ reel in the cable, until the cable pokes out of the conduit on your end. Pull about 4-5 inches of ribbon past the end of the cable, and then cut the ribbon cable on the other end, also with about 4-5 inches of extra. 

Decide which way you plan to orient the conduit, and then use a label printer or tape and a marker to mark an arrow → pointing _away_ from the Arduino enclosure. 

Since this is the first conduit, connect the PIR sensor housing to the far end. Slide the conduit and ribbon cable through one of the holes on the housing. Doesn't matter which one. Carefully thread the ribbon cable through the hole in one of the silicone washers and the screw-on cap, and use your fingers to tighten those down as hard as you can. You'll probably end up holding the connector in one hand and twisting the dome-like cap on the conduit connector in the other hand. 

Mark an arrow → on the side of the PIR sensor housing, pointing _away_ from the Arduino enclosure. 

For each piece of conduit you connect, repeat these steps, so that every single piece of conduit has a connector on both ends, ribbon cable threaded through it with 4-5" slack on both ends, and a 3D printed housing connected to the "far" end (from the Arduino enclosure). 

The next conduit you want to assemble is the other PIR sensor. Give this one a good five meters as well; the exact length is up to you, but you want enough to give yourself flexibility in positioning and aiming the sensor. 

Now you may see how this is a modular system; these conduit segments may be arranged in any configuration, so long as they form an unbroken chain from the Arduino to the final PIR sensor. 

Next, we will install terminal boards in the 3D-printed enclosures, and we will strip and attach the ribbon cable to the terminals on those boards. 

### Terminal boards

Use 8mm M3 machine screws to attach the terminal boards to the bosses in the enclosures. Be sure to orient them so that the arrow you drew on them points away from the Arduino, in the direction of the data flow down the NeoPixel strips. 

Depending on your 3D printer, the screws *should* bite into the provided holes. If your printer's dimensional accuracy isn't 100% you might end up inserting helicoils. 

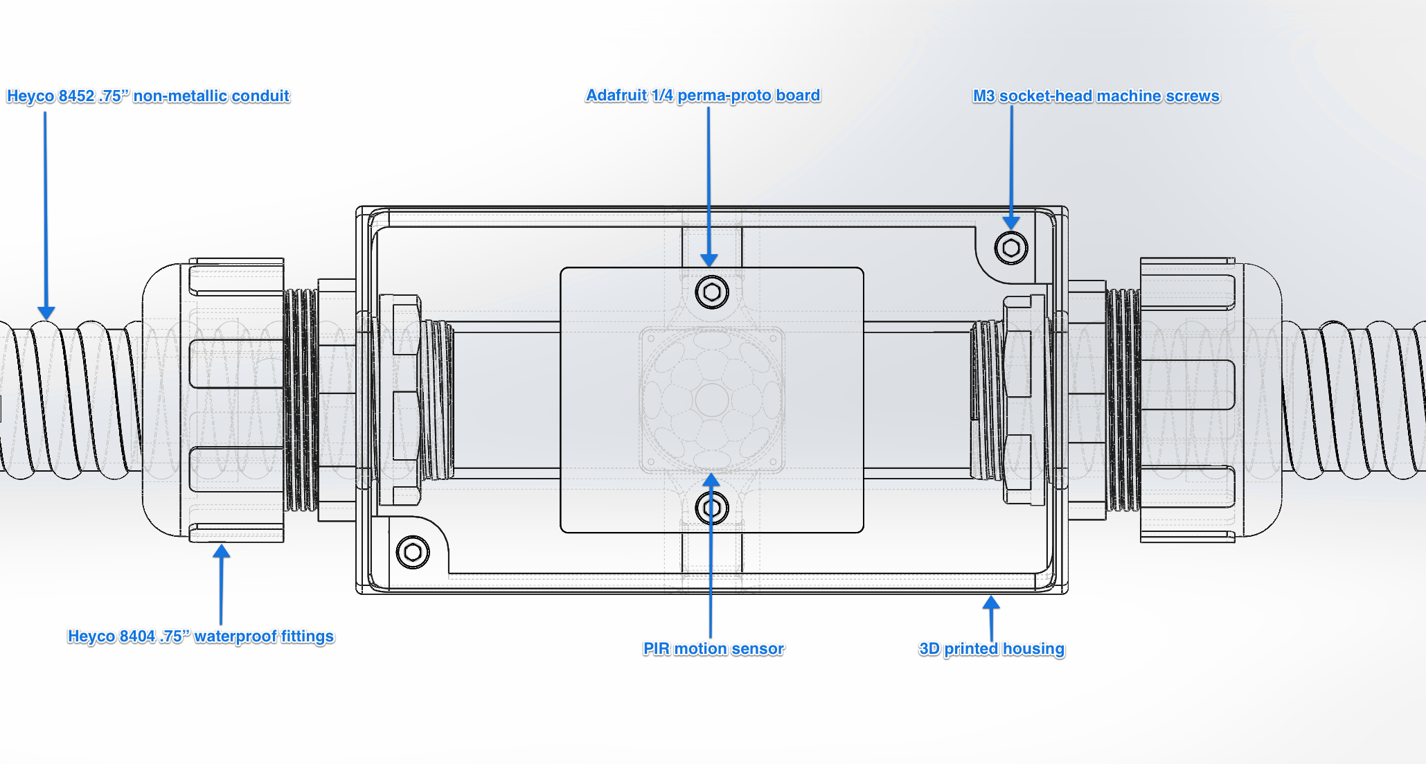
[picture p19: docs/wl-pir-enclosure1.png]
Enclosure


In *one* terminal board, you're going to solder an extra 2-wire terminal onto the side. These terminals are a passthrough for the yellow "pir1" sensor line, so set this board aside for use on the first ("pir0") sensor housing. 

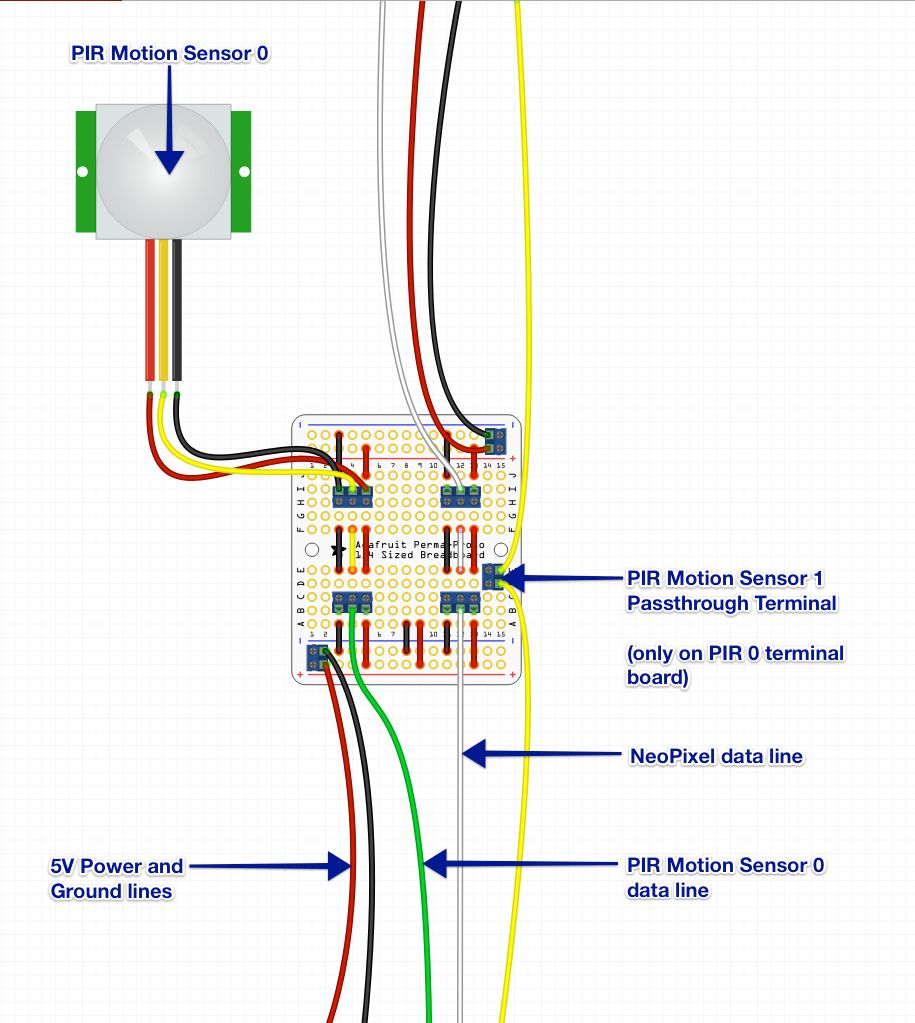
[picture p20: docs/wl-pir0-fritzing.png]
PIR0 Terminal Board Diagram


Here is a diagram showing the first PIR sensor terminal board. Note how the green `PIR0` data line is connected to the left set of terminals, and the yellow `PIR1` data line is connected to the extra 2-wire terminal on the side, as instructed above. 

Most of the other terminal boards will be used to pass through the `PIR1` data line, and to connect the NeoPixel data line and power to the NeoPixel strips. 

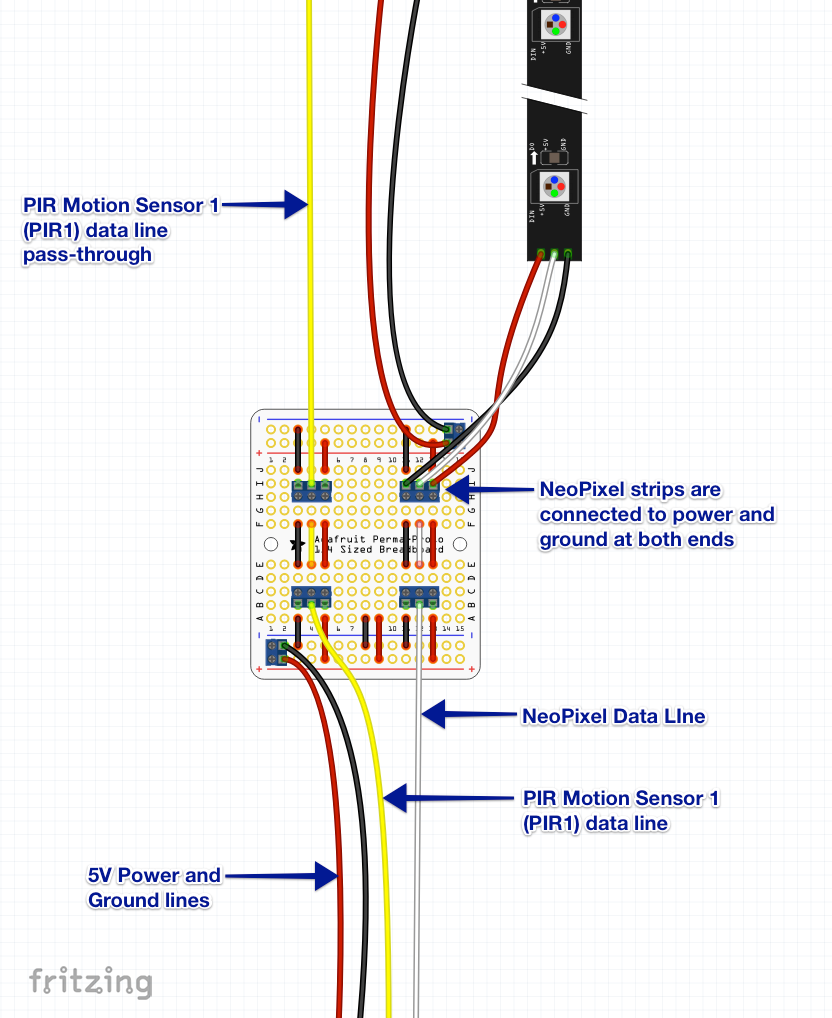
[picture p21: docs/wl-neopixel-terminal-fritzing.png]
NeoPixel Terminal Board Diagram


Here is a diagram showing the first terminal board where a NeoPixel strip is connected to the board (via the 4-pin waterproof cables). Note that the white `NeoPixel` data line connects to the input data pin on the right, and the NeoPixel strip is connected to the output data pins. 

Hopefully this gives you an idea of the model of the system: NeoPixel terminals pass the data line from white line to NeoPixel, or from NeoPixel to NeoPixel. They also connect the NeoPixel strips to power and ground at both ends. That keeps the color of the pixels bright. 

Every single terminal takes the `PIR1` line as an input, and passes it on, until the final "terminus" board, where the `PIR1` sensor connects to the terminal board. 

### PIR sensors 

Two enclosures house PIR passive-infrared motion sensors. Hold off installing the terminal boards in those two housings. 

Press-fit the PIR sensor into the provided slot in the bottom of the 3D-printed "PIR" enclosures. 

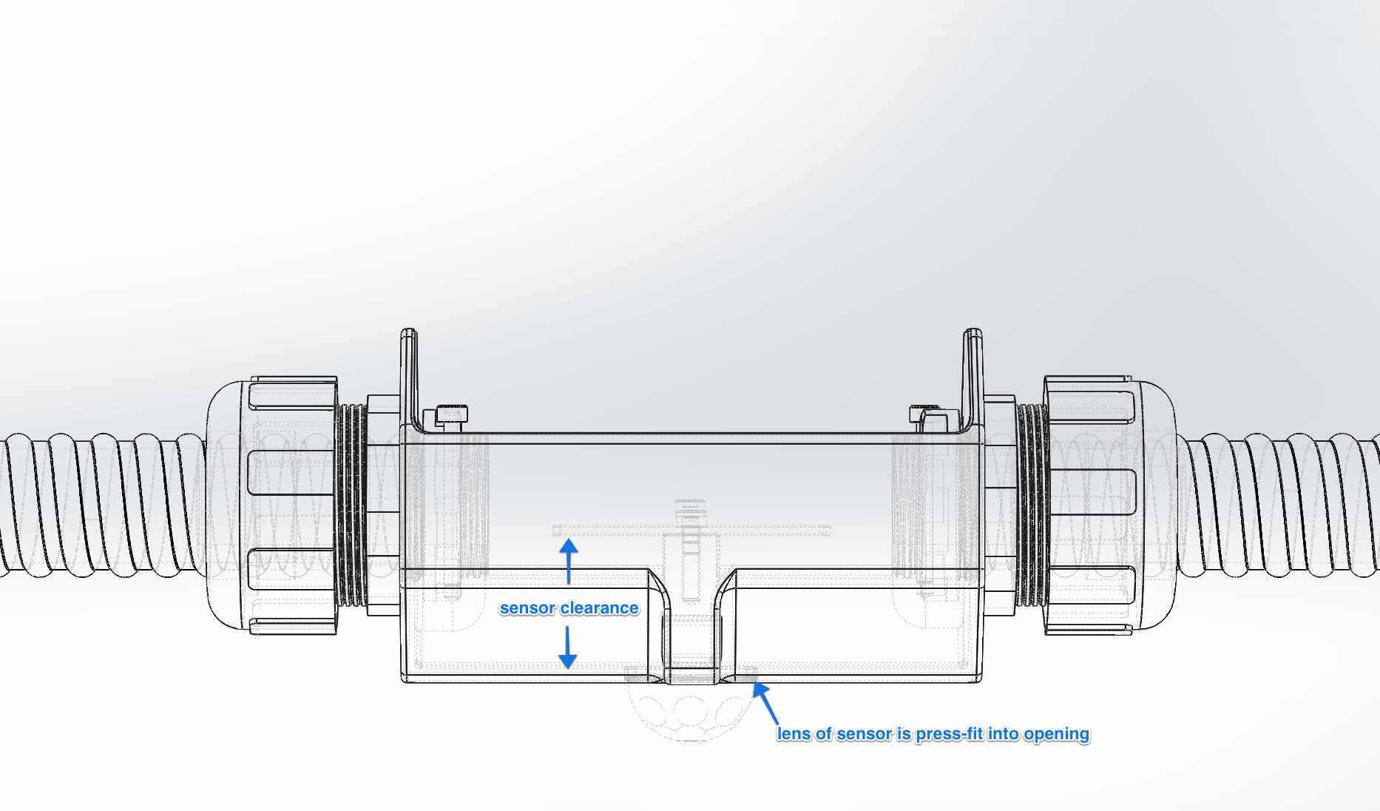
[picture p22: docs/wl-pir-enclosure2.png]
PIR Enclosure side view


You may want to then pop the circuit board off, leaving the lens in place, and use hot glue to weatherproof the opening, as well as keep the PIR sensor from popping free, which it will tend to do unless you glue it in. 

Once you've glued the PIR lens into the housing, carefully replace it, and connect the header and leads which came with it in the package.  

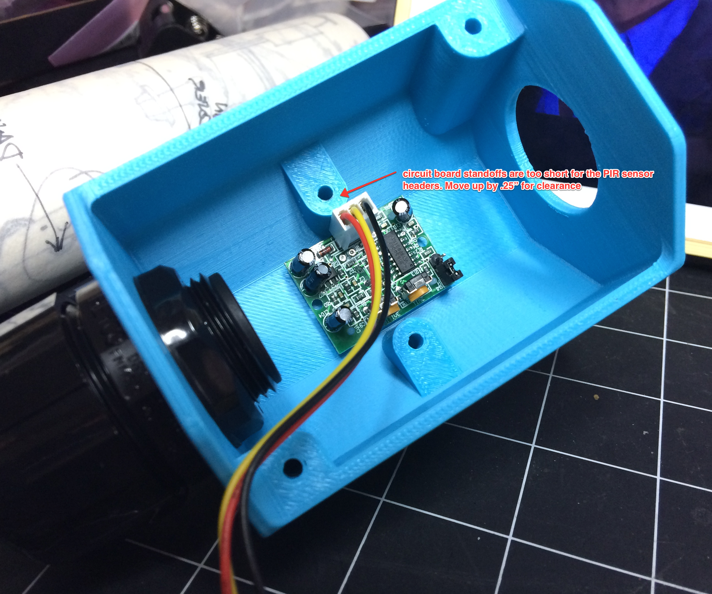
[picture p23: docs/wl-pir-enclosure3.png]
PIR sensor and wires


Install a terminal board over the sensor. Screw the power, data, and ground wires into the red, yellow, and black terminals, respectively. 

For the PIR sensor closest to the Arduino, connect the green wire on the ribbon cable to the PIR sensor, and the yellow wire to the special "passthrough" terminal you soldered in the previous step. 

TODO: picture of PIR sensor installed 

### Wiring

TODO: pictures of the wiring process

Start at the arduino enclosure and screw all the matching colored ribbon cable ends to their appropriate terminal. Leave any extras un-stripped, so that in the future you have the option of additional sensors or branching LED strips. 

At each terminal board, hook power and ground into the provided terminals. 

At the first PIR sensor, connect the green ribbon wire to the PIR sensor terminal, and connect the 3 wires from the PIR sensor to the other end of the terminal board. If there is no NeoPixel strip being connected to this enclosure, connect the white wire to the terminals on each side so that the data passes through. 

Connect the yellow wire to the "passthrough" terminal on the side of the terminal board. In all subsequent terminal boards, use the PIR sensor terminals to pass the yellow wire through; this is the wire for the final PIR sensor and it needs an unbroken chain all the way through. 

Once you finish with each terminal board, use your multimeter to check continuity from the terminals in the arduino enclosure. I find it best to coil the conduit into a big loop as I connect terminal boards, so that the terminal board is a meter or so from the arduino enclosure at maximum. 

When you reach a terminal board where a NeoPixel strip is being attached, thread an "output" 4-wire cable through the waterproof cable gland, and connect the red, white, and black cables to the output terminal, so that the data line passes from the white wire on the ribbon cable into the white wire on the 4-wire cable. 

When connecting NeoPixel strips to each other, use a two-cable configuration on the terminal board, so that the NeoPixels get connected to power and ground at each enclosure they touch. (TODO: clarify this)

TODO: instructional photos are probably good here. 

At the last terminal board, connect the yellow wire to the PIR sensor. Do a continuity check between the yellow pin on the arduino to the PIR sensor to make sure there are no breaks in the chain. 

Final checks: 

Check all the ground and power lines to make sure they aren't shorted anywhere down the line. Test the final terminal board against the arduino enclosure. If there are no shorts, turn on the power. Check the power terminals on the final board; it should show 5 volts. 

### Connect NeoPixels

Hook up the NeoPixels to their appropriate 4-pin cables. If you've done continuity checks at each terminal board, you should have an unbroken data line running from beginning to end. Turn on the power and wave your hand at a PIR sensor; you should see a purple sprite animate along the length of the NeoPixel strips. 

This is where you should snap the lids tightly down on the enclosures, and screw the cable glands tight on the 4-pin NeoPixel cables. 

### Install 

Lay the entire length of the lights out in a straight line, if you can. Leave the lids of the enclosures off (for the sensors) or loosely connected (for the NeoPixel interfaces). 

Power on the Arduino and walk alongside the assembly as the sprite animates. Watch for dead pixels, dead strips (probably caused by a bad cable connection on the terminal board), stuttering animation (caused by too high an `interval` value in the software), or other glitches. You want to catch those now, because the next thing you're going to do is install the whole assembly on-site. Test both motion sensors; when you reach the end of the animation loop, you should trip the farthest sensor, causing the sprite to animate back the way it came. If the far sensor doesn't work, you'll have to check continuity for the yellow line on the ribbon cable all the way down the chain. 

Disconnect the NeoPixels from the assembly. Loop the conduit through branches, around trees, along the ground, overhead… whatever path you want the lights to take. 

If your assembly is long enough, you may find it easier to break the length up into two or more pieces. That may allow you to loop around trees and tree branches without dragging the entire assembly along with you. 

Reconnect the NeoPixels. Use velcro loops to bind the NeoPixel strips to the conduit so that there's no bunching or sagging. The Heyco conduit should provide structure for the NeoPixel strips, which tend to sag and droop on their own. 

## Troubleshooting

Most problems with this installation are caused by wiring problems. If you're getting weird behavior, or no pixel illumination:

* Check the voltage at the positive and negative terminals in each enclosure while the assembly is powered on; you should have 5 volts at each terminal. If the voltage is less than 5V, you may have a short circuit in the power line. 

Specific problems I have run into:

### One or more of the NeoPixel strips do not light up (but some do)

Usually this happens because a wire has come loose, or you've got the polarity wrong. One of the NeoPixel strips themselves could be defective. 

* Are the NeoPixel strips oriented correctly? (Check the arrow on the strip; it should be pointed *away* from the Arduino enclosure)
* Use the *NeoPixel Reel Test* assembly to check the first NeoPixel strip that isn't working. 
* is the white data line connected all the way to the first NeoPixel input? Use the continuity check function of your multimeter to be certain. 
* Check any enclosures where the NeoPixels connect to 4-pin waterproof cables; it's possible that the terminals connecting the cables to the wiring harness have come loose as the cables flexed during installation. 
* Check the voltage on the terminal board just before the NeoPixel problem: do you have 5V at the `+` and `-` terminals? 

### None of the NeoPixel strips light up

Either no power is reaching the NeoPixels, or the data signal is not reaching them for some reason. At absolute minimum, even if the PIR sensors both fail, the first NeoPixel should light up green. 

* Does the Arduino have a power light? If not, refer to "The Arduino does not power on" below.
* Use the *NeoPixel Reel Test* assembly to check your first NeoPixel strip. 
* Is the logic level shifter chip installed in the interface board? 
* Does the logic level shifter chip face the correct way? The "U"-shaped cutout should face to the right/top of the board. 
* Is the logic level shifter chip installed in the correct (rightmost) pins of the socket? 
* Check the voltage at the `+` and `-` (red and black) terminals on the arduino interface board. You should have 5 volts. If so, go "downstream" and check the power terminals on all the terminal boards between the NeoPixels and the interface board; find the loose or missing power connections. If not, refer to "The Arduino does not power on" below for troubleshooting steps. 
* Use the continuity tester on your multimeter to make certain the white "data" terminal on the NeoPixel terminal board is connected to the white "data" pin on the Arduino Interface Board. 

### One of the motion sensors isn't working

The PIR sensors work by sending a 3 volt signal down the yellow or the green wires in the ribbon cable. They're powered by the red and black wires on their terminal pins. If the PIR doesn't get power, or if the yellow or green wires don't have perfect continuity all the way down the line from the arduino to the sensor, the sensors won't work. 

* Is the Arduino power light on? If not, see "The Arduino does not power on" below. 
* Does the indicator LED come on when the PIR sensor is tripped? If so, see "None of the NeoPixel strips light up" above. 
* Is the green data line connected all the way to the nearest PIR sensor? Check continuity with your multimeter. 
* Is the yellow data line connected all the way to the farthest PIR sensor? Check continuity with your multimeter. Aren't you glad you didn't screw the lids onto all the 3D-printed enclosures?
* Test the power and ground pins where the PIR sensor connects to the terminal board; you should have 5 volts. If not, check the power and ground pins on the terminal board itself. Got power there? You have a bad terminal board. No power? There's a break somewhere in the red or the black lines running back to the Arduino Interface Board, *or* there is a short circuit somewhere. 
* Check to make certain the wires from the terminal board to the PIR sensor itself have not come loose at either end.

### The Arduino does not power on

Either the battery is dead, the power switch isn't working, the PowerBoost 1000C isn't supplying 5V to the interface board for some reason, or you've got a wiring mistake. 

* Check the leads on the power switch: are any loose? Any short-circuits?
* Is the battery charged? Plug the PowerBoost 1000C into USB. 
* Does the light turn on on the PowerBoost 1000C? The power switch? 
* Test the terminals on the DC power plug. You should have 5V coming into the interface board. If not, check your solders on the PowerBoost 1000C. (And double-check that the PowerBoost is turning on.)
* Double-check the wiring on the Arduino interface board. Make sure the red and blue power rails are connected to the red and black terminals, and that there are no short circuits. 
* Check the wiring on the Arduino: the red terminal on the interface board should connect to the `5V` pin on the Arduino Due. The black terminal on the interface board should connect to the `GND` pin. 

### The NeoPixels light up all weird when I power it on

Most likely you've got a 3-volt signal from the Arduino Due connected to the NeoPixels. Usually this is a wiring mistake. 

* Check to make certain you have pin 6 on the Arduino Due connected to the *second pin from the right* on the "top" of the interface board, and the white ribbon cable wire is connected to the *third pin from the right* on the "bottom" of the board. ("Top" and "Bottom" here are assuming you hold the board with the IC on the _right_ side, and the DC power plug on the _left_.)
* Is the logic level shifter installed correctly? 

TODO: more better troubleshooting

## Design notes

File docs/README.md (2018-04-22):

# Witch Lights

The Witch Lights are an interactive light art installation, meant to be seen outdoors at night. 

Video and photos of the [Witch Lights][wl] can be found at http://witchlights.com/ 

[wl]: http://witchlights.com/

## Bill of Materials

Components: 

* [Heat-Shrink, various sizes](https://www.adafruit.com/products/1649)
* [Heat-Shrink, 1/4"](http://www.mouser.com/ProductDetail/3M-Electronic-Specialty/EPS300-1-4-48-Black-Bulk/)
* [Heat-Shrink, 1/2" (optional)](http://www.mouser.com/ProductDetail/3M/FP301-1-2-48-Clear-Bulk/)
* [Ribbon Cable, 100' spool](http://www.mouser.com/ProductDetail/Amphenol-Spectra-Strip/135-2801-010/)
* [Hookup wire, 18AWG solid-core, red](https://smile.amazon.com/Frey-Scientific-581181-Conductor-Coated/dp/B00FGDV8HU) and [black](https://smile.amazon.com/Remington-Industries-20UL1007SLDBLA-Hook-Up-Diameter/dp/B010T6075W/), 100' spool each
* [Hookup wire, 22AWG, various colors](https://www.adafruit.com/products/1311)
* [M3 socket-head machine screws, 8mm length](http://www.mcmaster.com/#socket-head-cap-screws/=10zugcn "McMaster-Carr") (box 100)
* [Heyco 8452 3/4" conduit](http://amazon.com/Heyco-8452-BLACK-LIQUID-TUBING/dp/B001BQ029G/) (100' spool)
* [PIR Motion Sensor](https://www.adafruit.com/products/189) (1)
* [Seeed Studio low-power Motion Sensor](http://wiki.seeed.cc/PIR_Motion_sensor_module/) (1)
* 3D-Printed `wl-pir.STL` PIR sensor enclosure (1)
* 3D-Printed `wl-nopir.STL` terminal board enclosures (varies according to the length of the installation you want to build)
* 3D-Printed `wl-seeedpir-terminus.STL` PIR sensor enclosure (1)

Arduino Enclosure components:

* [Arduino Due](https://www.adafruit.com/products/1076) Note: An Arduino Mega _will not_ work. The current build uses too much RAM for the Mega. 
* [Waterproof Enclosure (Large)](https://www.adafruit.com/products/905)
* 3D-Printed `wl-arduino-mount.STL` circuit board mount
* M3 machine screw, 20mm (?)
* ??mm plastic standoff
* [Adafruit Perma-Proto 1/2 board](https://www.adafruit.com/products/1609) 
* [Screw Terminals, 10-pin](https://www.adafruit.com/products/2234) (2)
* [74AHCT125 Logic Level Shifter IC](https://www.adafruit.com/products/1787)
* [16-pin IC socket](https://www.adafruit.com/products/2203)
* [4700uF capacitor](https://www.adafruit.com/products/1589)
* [2.1mm breadboard-friendly DC power jack](https://www.adafruit.com/products/373)
* [2.1mm male DC power adapter](https://www.adafruit.com/products/369)
* [10k ohm resistors](https://www.adafruit.com/products/2784) (2)
* [Adafruit PowerBoost 1000 board](https://www.adafruit.com/products/2465)
* [4400 MAh LiPo battery](https://www.adafruit.com/products/354)
* [Waterproof Panel-Mount on/off switch](https://www.adafruit.com/products/916)

You will need one set of these parts per 3D-printed enclosure (see instructions):

* [Heyco 8404 3/4" conduit fittings](http://smile.amazon.com/Heyco-BLACK-STRAIGHT-CONNECTOR-package/dp/B00LWLMX7O/) (2)
* [Heyco 3261 3/4" waterproof washers](https://amazon.com/Heyco-3261-SANTOPRENE-SEALING-package/dp/B00PKLGC8S/) (2)
* [Adafruit Perma-Proto 1/4 board](https://www.adafruit.com/products/1608)
* [Screw Terminals, 2-pin](https://www.adafruit.com/products/2234) (3)
* [Screw Terminals, 3-pin](https://www.adafruit.com/products/2234) (2)

You will need one set of these parts per NeoPixel strip (see instructions):

* [NeoPixel 30 LED/meter strip, black](https://www.adafruit.com/products/1460), 5 meters
* [4-pin waterproof cable](https://www.adafruit.com/products/744) (2)
* [waterproof cable gland](https://www.adafruit.com/products/762) (2)

Optional NeoPixel Reel Test rig:

(You can optionally build a dedicated Arduino rig to test your NeoPixel strips and keep it handy for field testing, or you can borrow components from the rest of the installation.)

* [Arduino Uno](https://www.adafruit.com/products/50)
* [Adafruit Perma-Proto 1/4 board](https://www.adafruit.com/products/1608)
* [Screw Terminals, 3-pin](https://www.adafruit.com/products/2234) (2)
* [4-pin waterproof cable](https://www.adafruit.com/products/744)

Tools:

* 3D Printer
* Wire Strippers
* Heavy-duty scissors or shears
* Needle-Nose Pliers
* Soldering Iron
* Multimeter
* 2.5mm Hex Wrench
* 1.5mm or 1.3mm flathead screwdriver
* Heat Gun
* 16mm hole saw
* 1" hole saw
* Third-hand tool
* panavise circuit board vise
* label printer (optional)
* cable snake
* wooden dowel (for running cable)
* stick-on velcro dots
* thin velcro cable-management strips

## 3D Printing

For best results, print all components in black or green plastic. 

The enclosures are designed to be easily printable on any commercial 3D printer; they were printed on a first-generation Makerbot Replicator in PLA and ABS plastic, and have been successfully tested on Makerbot Replicator 2, Printrbot, and Lulzbot printers.

Printing an enclosure on a Makerbot Replicator 2

The purpose of the enclosures is threefold: 

1. House passive infrared (PIR) motion sensors and connect their data lines to a ribbon cable reaching back to the arduino enclosure.
2. Connect NeoPixel strips to their data lines on the same ribbon cable, or to each other (if using multiple strips).
3. Connect NeoPixel strips to the power and ground lines at both their origin and terminus, as recommended in the [Adafruit NeoPixel Uberguide][uber], so that the lights don't dim and turn brown as they extend far away from the arduino enclosure.

[uber]: https://learn.adafruit.com/adafruit-NeoPixel-uberguide

### Printing Enclosures

First, download the files in the `STLs` directory. 

Next, before you jump in to printing and assembling the enclosures, you should make a thumbnail sketch of the installation, so that you know how how many of which components to make, and how they will be assembled. 

For example, here is a diagram of a naive installation, with two PIR sensors and one NeoPixel strip:

    A------P========================================P

3D Printing Instructions Figure 1

This configuration uses the PIR enclosures to connect the NeoPixels to power and data. 

I *do not* recommend you use this configuration, because the PIR sensors have a very, very long range, and so you won't get reliable results. As you approach one end of the strip, the other sensor may trip, and that ruins the illusion of the lights. 

Instead, I recommend a slightly more complex configuration as the simplest possible arrangement: 

    A-------P------N====================================N------------P

3D Printing Instructions Figure 2

To make this configuration, you will need two `wl-pir.stl` enclosures, one `wl-nopir.stl` enclosure, and one `wl-seeedpir-terminus.stl` enclosure. This will space out the sensors and make it so that they trigger at the right times, making the lights chase back and forth between the sensors. 

Please see the second video in the Overview section if you want to see what this configuration looks like in the wild. 

If you want to lengthen the lights, just add another `wl-nopir.stl` enclosure to connect another NeoPixel strip, like so: 

    A-------P------N======================N=====================N------------P

3D Printing Instructions Figure 3

For each installation you build, you will want one `wl-pir.stl` enclosure, one `wl-seeedpir-terminus.stl` enclosure, and one more `wl-nopir.stl` enclosure than the number of NeoPixel strips. 

If you want to make things a bit more complex (why not?), you can space out the NeoPixel strips with areas of blank conduit, which will lengthen the area you can cover with the lights, like so: 

    A-------P------N==================N----------------N==================N------------P

3D Printing Instructions Figure 4

In the end, I recommend sketching your intended installation and then counting the number of each enclosure you will want. Once you do that, start printing your enclosures; they take an average of 5-6 hours each, so while they print you can start figuring out which lids you want to print. 

### Printing Lids

Complexity is the price you pay for a modular system. And this system is very modular, so of course there's an extra step: you have to determine which lids to print. 

Take a look at your sketch from earlier. Let's say you're making a two-strip installation, like so: 

    A-------P------N======================N=====================N------------P

3D Printing Instructions Figure 3

There are three possible lids to print, with zero, one, or two cutouts for waterproof cable glands. That's where the waterproof cables will come out of the enclosures and connect to the NeoPixel strips. 

For each enclosure, look at the diagram. Is there a NeoPixel strip touching the enclosure? If not, print a lid with 0 holes. 

If there's one NeoPixel strip touching the enclosure, print a lid with 1 holes. And if there are two strips touching (like the middle enclosure in the above diagram), print a lid with 2 holes. 

The rule of thumb is, **print a lid with the same number of holes as the number of NeoPixels this enclosure needs to interface with**. 

### Printing Arduino Mount

Print one of the `wl-arduino-mount.STL` file and place it with the components for the arduino enclosure. 

## Wiring and Soldering

The physical layer of this project is composed of the Arduino Due, a power circuit, ribbon cable running through conduit, terminal circuit boards in the enclosures, and waterproof cabling for the NeoPixel strips. 

This part of the project has four steps: 

1. Wire and solder the interface board for the Arduino
2. Solder the power elements to the Arduino interface board
3. Wire and solder the terminal boards
4. Connect the NeoPixels to 4-pin waterproof cables and test them

### Arduino Interface Board

The Arduino Due is a 3.3v microcontroller, but the NeoPixels need 5v on the data line. So we'll need to use a logic level shifter, which will take the data signals sent by pin 6 of the arduino and amp them up to 5 volts. 

And since we're using hookup wire and ribbon cable to send the power and data signals down the length of the installation, we probably want to use screw terminals to connect those wires to the arduino. 

Therefore, you're going to need to make a circuit board for the Arduino Due so it can talk to the NeoPixels and hook up to the ribbon cable. 

Witch Lights - Arduino Interface Board
	1
Use an Adafruit Perma-Proto Half-Size board and solder a pair of 10-pin screw terminals to it, and wire it up as shown in the photograph above. 

The 74AHCT125 chip is installed so that the little "U" cutout faces to the right of the board, matching the little "U" cutout in the socket. 

(TODO: detail shot of 74HCT125 chip)

### Power

Once the Perma-Proto board is wired up like in the photo above, it's time to attach the 4700uF capacitor, and the 2.1mm power connector. 

(TODO: Get current photo of capacitor and power connector on perma-proto board)

Wire up the 5V power supply from the battery board to the 2.1mm connector on the arduino circuit board. Optional power switch installed in the side would go between the power line from the battery board and the arduino circuit board. 

### Connect Arduino Due to Interface Board

It's time to connect the Arduino Interface Board with the Arduino Due itself. We're going to use the 20" M3 screw and stand-offs to mount the board underneath the Arduino. 

Install hookup wire into the interface board's screw terminals as shown: 

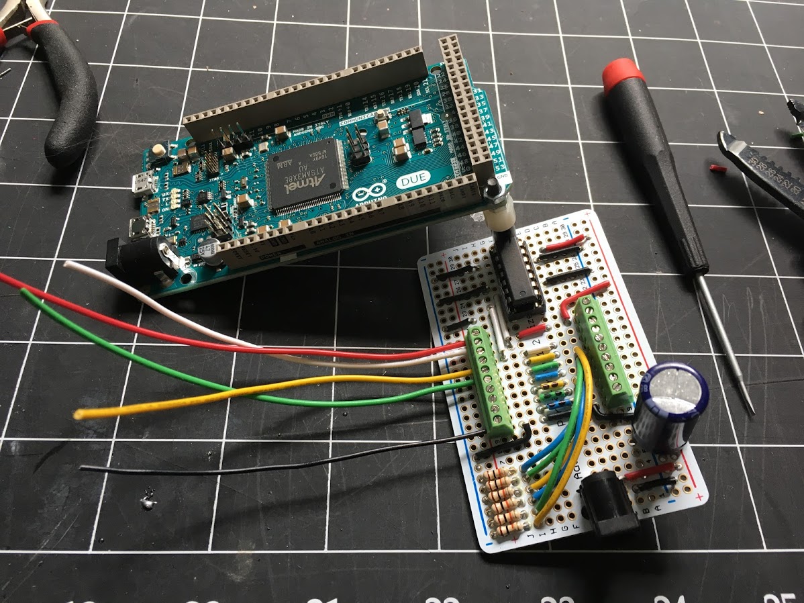
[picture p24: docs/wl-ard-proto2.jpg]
Arduino Due attached to the interface board with wires installed


Once the wires are installed in the terminal board, rotate the arduino, and use your wire strippers to trim the wires to length and insert stripped ends into the Arduino's headers: 

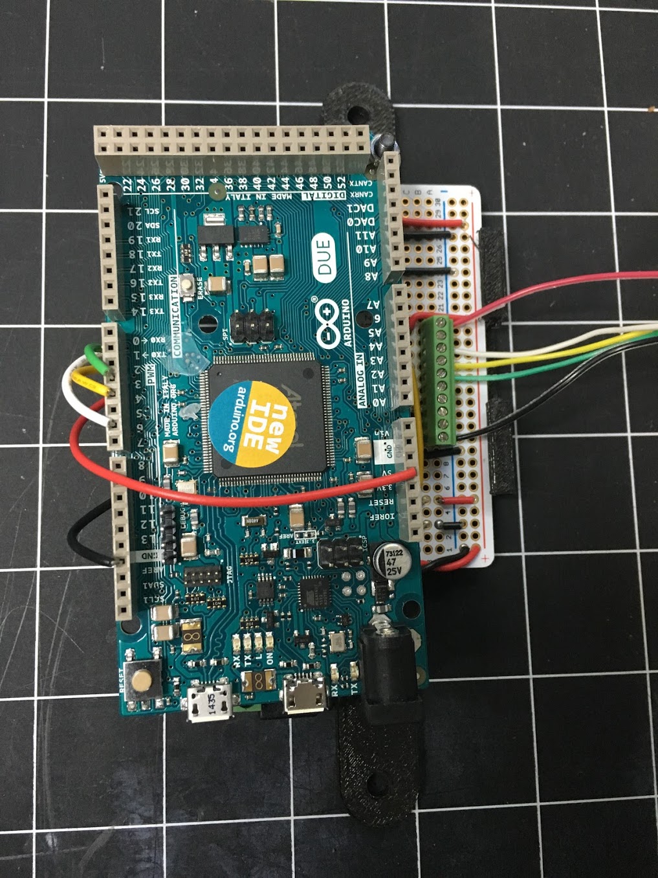
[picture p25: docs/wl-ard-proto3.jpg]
Arduino Due with wires installed in the headers


* Connect the *red* terminal (power) to the "5V" pin
* Connect the *rightmost white* terminal (NeoPixel data) to digital pin 6 (refer to the detail photo above)
* Connect the *green* terminal (PIR sensor 0) to digital pin 3
* Connect the *yellow* terminal (PIR sensor 1) to digital pin 4
* Connect the *black* terminal (ground) to the "GND" pin

**Be certain to wire the data line from pin 6 to the indicated terminal in the photo, and connect the white data line cable to the other indicated terminal on the other side; if you hook them up incorrectly, the NeoPixels will light up erratically or not at all.** 

The Arduino Due and Interface Board assembly is ready to be installed in the enclosure. Set the assembly aside for now. 

### Terminal Boards

For each 3D-printed enclosure you make, you're going to need a terminal board. These are made using Adafruit Perma Proto 1/4 size boards, 3-pin terminals, and 2-pin terminals.

You'll probably want to strip and install the wires first, like so:

PIR Terminal Board Detail 1

Once those are soldered, use masking tape to hold the terminals on to the board, and solder them on, like so: 

PIR Terminal Board Detail 2

Use the continuity tester feature of your multi-meter to test for short circuits and to ensure that the power, data, and ground lines pass properly through from one side of the board to the other. 

Once you're certain you have a good board, do yourself two small favors:

1. Use a 1.5mm flathead screwdriver to loosen _all_ of the terminals; they ship tightened all the way, and it's far easier to loosen them now than it will be in the field
2. Draw an arrow on the board as shown. This indicates the direction of the data flow away from the Arduino. When it's time to install the boards in their enclosures, you'll install them so that the arrow points away from the Arduino, and that will save you heartache and troubleshooting later. Trust me. 

### NeoPixel Cables

You'll have to solder and heat-shrink one end of a waterproof 4-pin cable to each side of the NeoPixel strip, so that we have a weatherproof way to connect the strips to the 3D-printed enclosures. Once you do that, you'll need to test the strip to make certain there are no problems with your soldering job. 

Make sure you always use the same cable gender for input and output, or else it'll get really confusing. I used a label printer to make an arrow pointing in the direction of the NeoPixel data flow (as indicated by arrows on the NeoPixel Strips), and labeled all the waterproof cables before starting assembly. 

Arrows on NeoPixel Cables

Use a third-hand tool to hold the waterproof cable and the end of the NeoPixel strip. Use your wire strippers to take some more insulation off the red, black, and white wires coming out of the waterproof cable, and clip the yellow wire short; we won't be using it. 

Put a length of 1/4" heat shrink tubing on the waterproof cable, and put some thin heat-shrink tubes on the red, white, and black wires coming from the NeoPixel strips. Optionally, slide some 1/2" heat-shrink tubing over the end of the NeoPixel strip itself. 

Tin the wires a little bit by heating them up with a soldering iron and brushing them with a bit of solder. Then twist the black wires together, and use the soldering iron and a bit more solder to splice them. Repeat the process with the red and white wires, like so: 

Soldering wires

Use the continuity tester on your multimeter to test that you have continuity from the pins on the cable to the bare spliced wires. You may have to use some trial and error to figure out which pin goes to which color of cable; I always forget and have to poke around. 

Then slide the thin heat shrink tubing over the bare soldered wire. Use a heat gun to shrink the tubing over the wires. 

Heat shrink on the spliced wire

Now, slide the 1/4" heat-shrink tubing over all the colored wires, up to the base of the silicone sheath of the NeoPixel strip.

Heat-shrink over the colored wire

Use a heat gun to shrink the tubing and seal the wires.

Heat-shrunk wires

And now, if you have the 1/2" heat shrink over the NeoPixel strips, slide it over the point where the heat-shrink abuts the silicone sheath.

Optional final heat shrink

Use a heat gun to shrink that down and reinforce the joint. 

Repeat this process on the other end of the NeoPixel strip with the other end of the waterproof cable. And repeat again for each NeoPixel strip you use. 

#### Test NeoPixel Reels

I used an Arduino Uno to create a dedicated test rig for NeoPixel reels after soldering them; you can either do this, or load the `NeoPixel_Reel_Test` sketch on the Arduino Due. Either way, borrow one of the enclosure terminal boards (or make an extra one), and connect the "out" end of a waterproof cable to it, and hook the power and NeoPixel data lines to the Arduino. 

The `NeoPixel_Reel_Test` sketch runs alternating colors down the length of any NeoPixel 5-meter reel connected to it. The purpose of this test is to make certain there are no problems with the solders on the NeoPixel reel and 4-pin waterproof cables. 

Use the reel tester after you solder cable to every NeoPixel strip, then roll up the NeoPixel strip onto its reel and put it away in its silver bag; mark "Tested" and the date on the bag. 

## Software

The current iteration of the software is in the directory marked `witch-lights-classic`. This code successfully handles two PIR sensors and will trigger a different sprite animation when one or the other sensor is tripped. 

New software has been written by intrepid C++ coder James Cronen. It can be found on the `feature/2017-accel` branch. The sketch you will want is `fastled_w4v2_reimpl.ino`. I have not yet updated the documentation for this branch, as it is still experimental. The last commit to this branch occurred at midnight, less than a full day before I was due to leave for Firefly 2017. Feel free to check this build out and experiment with it. I will update the documentation when the bug hunting is farther along. 

### Required Libraries

The Witch Lights run Adafruit NeoPixels, and therefore require the [Adafruit NeoPixel Library][neolib]. Follow the instructions in the README to install the library in your Arduino environment. 

[neolib]: https://github.com/adafruit/Adafruit_NeoPixel

If you have trouble installing the library, or if you've never installed an Arduino library before, please check out the [Adafruit Guide to Arduino Libraries][agal] for in-depth instructions. 

[agal]: https://learn.adafruit.com/adafruit-all-about-arduino-libraries-install-use

### Program the Arduino

Download `witch-lights-classic` and use the Arduino IDE to upload the code to your Arduino Due. 

If the Arduino is properly wired to its terminal board, you should be able to use the screw terminals to connect directly to a NeoPixel strip. Power on the Arduino and use a jumper cable to make the green terminal pin go high; you should see the purple faerie lights race away down the NeoPixel strip. 

### Adjust the Code

Once you have an animation running, you can adjust the variables in the code to tune the speed and frequency of the animation. All of the variables you need to adjust are declared at the beginning of the file: 

#### Disclaimer! The following documentation only applies to the `witch-lights-classic.ino` build of the software. The newest build uses different constants to perform much the same functions.

`N_LEDS`: Each NeoPixel strip has 150 LEDs. Change this value to equal the total number of LEDs in your project. 
IMPORTANT: As you increase the number of LEDs past 150, the animation speed will slow, and you will have to reduce the "interval" variable to compensate.

`interval`: Increase this to make the sprite's animation begin more slowly. Reduce it to make the sprite's animation begin more quickly. As you add LEDs to your project, you will have to adjust this variable.

`minInterval`: If your project has a smaller number of LEDs (150 or 300), you may need to increase this variable to 1 or 2, in order to make the animation appear natural. If you have more than 300 LEDs, leave it at 0. 

`hoverLowerDistance`: This adjusts how frequently the sprite stops and hovers. Decrease it to make the sprite stop more often. Increase it to make the sprite run for longer distances before it pauses to hover. 

`hoverLowerTime`: Adjust this variable, along with `hoverUpperTime`, to change how long the sprite "hovers" for; the higher the values, the longer the sprite will hover. A value of 5 means that the sprite will run through its "sparkle" animation cycle 5 times. The greater the difference between the two values, the greater the random variation in how long the sprite pauses to sparkle for. You will need to tune this value after you've made changes to any of the above variables. 

The process for adjusting the animation goes like this: 

* Set the `N_LEDS` first.
* Let the animation run a few times, watching the sprite as it _starts_. The animation should be a slow but smooth launch. 
* If the speed at start feels slow or choppy, decrease `interval`. If the sprite zips away too quickly, increase `interval`.
* Use the `hoverLowerDistance` variable to tune how often the sprite stops. I recommend laying the strip on the floor at full length, and walking alongside it. You want the sprite to go just a bit faster than you would walk at a natural pace. 
* Fine-tune the `hoverLowerTime` and `hoverUpperTime` variables. This is a matter of feel; you want the amount of time the sprite pauses to feel natural. It's a matter of "you know it when you see it".

TODO: install knobs and map them to the `interval` and `hoverLowerDistance` variables to allow for on-site fine tuning without the need for a laptop.

## Final Assembly and Use

You're ready to put the whole thing together! At this point, you should have:

* 3D-printed enclosures
* 3D-printed arduino mount
* Terminal boards (1 per enclosure)
* Arduino and its terminal board, with the software uploaded and adjusted
* NeoPixel reels with cabling (tested)
* All the remaining components on the Bill of Materials, such as conduit, ribbon cable, etc. 

Here's the process you're going to follow: 

1. Assemble the Arduino Enclosure, and build the power circuit.
2. Cut conduit to the proper lengths, and pull ribbon cable through them for the wiring harness.
3. Install the terminal boards in the 3D-printed housings
4. Install the PIR sensors in the sensor housings
5. Connect the ribbon cable to the terminals on the boards, and test continuity
6. Wire the NeoPixel interface cables into the housings and connect the NeoPixels
7. Run final testing on the assembly

### Arduino Enclosure and Power

In this step, you will assemble the Arduino Enclosure, and construct a power circuit, with battery connector and power switch. 

Enclosure with battery pack

Use a compass to mark a 1" circle on the narrow end of the enclosure, where you want the Heyco connector to go. This will be the "bottom" of the enclosure. (See the photograph above for guidance on where to mark the hole.) Mark the center of the circle. 

Drill a pilot hole with a 1/8" drill bit first, and then use your hole saw to cut the 1" hole in the enclosure. You'll need to use a file or rough sandpaper to open the 1" hole up enough to insert a Heyco connector. 

Slide the half-size perma-proto board into the printed `wl-arduino-mount.STL` piece, then mount it in the enclosure using the M4 screws provided when you unwrapped the enclosure. 

Now for the power circuit. First, we need to place the switch. 

Use a 16mm hole saw to cut a hole in the side of the enclosure; make sure to position it so that the switch's terminals won't interfere with the arduino's proto board. Screw the panel-mount switch into the hole (and don't forget the rubber O-ring). 

Solder leads to the `GND` and `EN` pins on the PowerBoost 1000C, and solder leads to the `5V` and `GND` pins, as well as the `+` and `-` pins. Run `5V` and `GND` down to the power plug on the proto-board, and screw them into the terminals of the male DC adapter. Plug it into the proto-board. 

Diagram of the on/off panel-mount power switch

(See the [product page for the power switch](https://www.adafruit.com/products/482) for details)

Run the `+` and `-` pins to the (outer) LED terminals on the power switch. Make sure to connect them to the `+` and `-` terminals of the switch, respectively. Connect `GND` and `EN` to the terminals labeled `NC` and `C1`. ("Normaly closed" and "Common contact".) 

What you are doing is, you're closing the circuit between `EN` and `GND` on the PowerBoost 1000C. That tells the PowerBoost to turn off. When the on/off switch is pressed, it _opens_ the circuit, and the PowerBoost gets the message to turn on, which supplies power to both the Arduino and the LED ring around the switch itself. 

Connect a battery to the PowerBoost 1000C. When you press the on/off switch, the switch should light up, and the Arduino should power on. If not, check your connections to the terminals on the switch. It's very easy to mix up the `+` and `-` terminals for the switch's LED, and if you do, the PowerBoost won't turn on. 

Position the battery as shown in the photograph above, and carefully use stick-on velcro dots to attach it to the inside of the enclosure. 

At this point, you have a functional brain. You can charge the battery with the lid open by plugging the PowerBoost 1000C into a [micro-USB power adapter](https://www.adafruit.com/products/1995), and the system will continue to run as it charges. 

You should still also have access to the programming port on the Arduino, in case you need to reprogram it for upgrades or bug fixes.  

### Cut Conduit and Pull Cable

This is where you refer back to your plan. How many NeoPixel strips are you going to use? How are they spaced? You should have a thumbnail sketch. 

If you don't, refer back to the **Printing Enclosures** section above, sketch out your length of witch lights, and get started printing the enclosures you're going to need. 

For each NeoPixel strip, you're going to need five meters of conduit. 

If you plan to have a spacer between your NeoPixel strips, you're going to need conduit for that, as well. 

No matter what kind of configuration you sketched out earlier, you're going to put a five meter conduit between the Arduino enclosure and the first PIR sensor. This gives you enough flexibility to find a safe place to install the Arduino and then position the PIR sensor strategically to sense motion at the right place. 

Measure out five meters (16.4 feet) of conduit and cut it with your heavy-duty scissors or shears. Find two Heyco connectors. Unscrew the big dome-like component and slide it over the conduit, then swedge the conduit into the end of the connector. Screw the dome back on, tightly. This seals the conduit onto the connector. Repeat for the other end. 

Congratulations, you've got your first length of conduit ready to go. 

Once you've got your conduit set, it's time to pull ribbon cable through it. You're going to want a friend to help you with the next step. 

Extend your cable snake into the conduit and keep unreeling it until it pokes through the far end of the conduit. Then your friend can pinch the cable and stuff it through the little hole on the end of the cable snake, or use tape to attach it. Now have your friend put your wooden dowel through the hole in the ribbon cable spool, and hold either end of the dowel as you _slowly and carefully_ reel in the cable, until the cable pokes out of the conduit on your end. Pull about 4-5 inches of ribbon past the end of the cable, and then cut the ribbon cable on the other end, also with about 4-5 inches of extra. 

Repeat this process with the 20 AWG solid core red and black wires, for the power harness.

Decide which way you plan to orient the conduit, and then use a label printer or tape and a marker to mark an arrow → pointing _away_ from the Arduino enclosure. 

Since this is the first conduit, connect the PIR sensor housing to the far end. Slide the conduit and ribbon cable through one of the holes on the housing. Doesn't matter which one. Carefully thread the ribbon cable through the hole in one of the silicone washers and the screw-on cap, and use your fingers to tighten those down as hard as you can. You'll probably end up holding the connector in one hand and twisting the dome-like cap on the conduit connector in the other hand. 

Mark an arrow → on the side of the PIR sensor housing, pointing _away_ from the Arduino enclosure. 

For each piece of conduit you connect, repeat these steps, so that every single piece of conduit has a connector on both ends, ribbon cable threaded through it with 4-5" slack on both ends, and a 3D printed housing connected to the "far" end (from the Arduino enclosure). 

The next conduit you want to assemble is the other PIR sensor. Give this one a good five meters as well; the exact length is up to you, but you want enough to give yourself flexibility in positioning and aiming the sensor. 

Now you may see how this is a modular system; these conduit segments may be arranged in any configuration, so long as they form an unbroken chain from the Arduino to the final PIR sensor. 

Next, we will install terminal boards in the 3D-printed enclosures, and we will strip and attach the ribbon cable and power cables to the terminals on those boards. 

### Terminal boards

Use 8mm M3 machine screws to attach the terminal boards to the bosses in the enclosures. Be sure to orient them so that the arrow you drew on them points away from the Arduino, in the direction of the data flow down the NeoPixel strips. 

Depending on your 3D printer, the screws *should* bite into the provided holes. If your printer's dimensional accuracy isn't 100% you might end up inserting helicoils. 

Enclosure

In *one* terminal board, you're going to solder an extra 2-wire terminal onto the side. These terminals are a passthrough for the yellow "pir1" sensor line, so set this board aside for use on the first ("pir0") sensor housing. 

PIR0 Terminal Board Diagram

Here is a diagram showing the first PIR sensor terminal board. Note how the green `PIR0` data line is connected to the left set of terminals, and the yellow `PIR1` data line is connected to the extra 2-wire terminal on the side, as instructed above. 

Most of the other terminal boards will be used to pass through the `PIR1` data line, and to connect the NeoPixel data line and power to the NeoPixel strips. 

NeoPixel Terminal Board Diagram

Here is a diagram showing the first terminal board where a NeoPixel strip is connected to the board (via the 4-pin waterproof cables). Note that the white `NeoPixel` data line connects to the input data pin on the right, and the NeoPixel strip is connected to the output data pins. 

Hopefully this gives you an idea of the model of the system: NeoPixel terminals pass the data line from white line to NeoPixel, or from NeoPixel to NeoPixel. They also connect the NeoPixel strips to power and ground at both ends. That keeps the color of the pixels bright. 

Every single terminal takes the `PIR1` line as an input, and passes it on, until the final "terminus" board, where the `PIR1` sensor connects to the terminal board. 

### PIR sensors 

Two enclosures house PIR passive-infrared motion sensors. Hold off installing the terminal boards in those two housings. 

Press-fit the PIR sensor into the provided slot in the bottom of the 3D-printed "PIR" enclosures. 

PIR Enclosure side view

You may want to then pop the circuit board off, leaving the lens in place, and use hot glue to weatherproof the opening, as well as keep the PIR sensor from popping free, which it will tend to do unless you glue it in. 

Once you've glued the PIR lens into the housing, carefully replace it, and connect the header and leads which came with it in the package.  

PIR sensor and wires

Install a terminal board over the sensor. Screw the power, data, and ground wires into the red, yellow, and black terminals, respectively. 

For the PIR sensor closest to the Arduino, connect the green wire on the ribbon cable to the PIR sensor, and the yellow wire to the special "passthrough" terminal you soldered in the previous step. 

TODO: picture of PIR sensor installed 

### Wiring

TODO: pictures of the wiring process

Start at the arduino enclosure and screw all the matching colored ribbon cable ends to their appropriate terminal. Leave any extras un-stripped, so that in the future you have the option of additional sensors or branching LED strips. 

At each terminal board, hook power and ground into the provided terminals. 

At the first PIR sensor, connect the green ribbon wire to the PIR sensor terminal, and connect the 3 wires from the PIR sensor to the other end of the terminal board. If there is no NeoPixel strip being connected to this enclosure, connect the white wire to the terminals on each side so that the data passes through. 

Connect the yellow wire to the "passthrough" terminal on the side of the terminal board. In all subsequent terminal boards, use the PIR sensor terminals to pass the yellow wire through; this is the wire for the final PIR sensor and it needs an unbroken chain all the way through. 

Once you finish with each terminal board, use your multimeter to check continuity from the terminals in the arduino enclosure. I find it best to coil the conduit into a big loop as I connect terminal boards, so that the terminal board is a meter or so from the arduino enclosure at maximum. 

When you reach a terminal board where a NeoPixel strip is being attached, thread an "output" 4-wire cable through the waterproof cable gland, and connect the red, white, and black cables to the output terminal, so that the data line passes from the white wire on the ribbon cable into the white wire on the 4-wire cable. 

When connecting NeoPixel strips to each other, use a two-cable configuration on the terminal board, so that the NeoPixels get connected to power and ground at each enclosure they touch. (TODO: clarify this)

TODO: instructional photos are probably good here. 

At the last terminal board, connect the yellow wire to the PIR sensor. Do a continuity check between the yellow pin on the arduino to the PIR sensor to make sure there are no breaks in the chain. 

Final checks: 

Check all the ground and power lines to make sure they aren't shorted anywhere down the line. Test the final terminal board against the arduino enclosure. If there are no shorts, turn on the power. Check the power terminals on the final board; it should show between 5 and 3.5 volts. Preferably 5 if there are no NeoPixel strips attached yet. 

### Connect NeoPixels

Hook up the NeoPixels to their appropriate 4-pin cables. If you've done continuity checks at each terminal board, you should have an unbroken data line running from beginning to end. Turn on the power and wave your hand at a PIR sensor; you should see a purple sprite animate along the length of the NeoPixel strips. 

This is where you should snap the lids tightly down on the enclosures, and screw the cable glands tight on the 4-pin NeoPixel cables. 

### Install 

Lay the entire length of the lights out in a straight line, if you can. Leave the lids of the enclosures off (for the sensors) or loosely connected (for the NeoPixel interfaces). 

Power on the Arduino and walk alongside the assembly as the sprite animates. Watch for dead pixels, dead strips (probably caused by a bad cable connection on the terminal board), stuttering animation (caused by too high an `interval` value in the software), or other glitches. You want to catch those now, because the next thing you're going to do is install the whole assembly on-site. Test both motion sensors; when you reach the end of the animation loop, you should trip the farthest sensor, causing the sprite to animate back the way it came. If the far sensor doesn't work, you'll have to check continuity for the yellow line on the ribbon cable all the way down the chain. 

Disconnect the NeoPixels from the assembly. Loop the conduit through branches, around trees, along the ground, overhead… whatever path you want the lights to take. 

If your assembly is long enough, you may find it easier to break the length up into two or more pieces. That may allow you to loop around trees and tree branches without dragging the entire assembly along with you. 

Reconnect the NeoPixels. Use velcro loops to bind the NeoPixel strips to the conduit so that there's no bunching or sagging. The Heyco conduit should provide structure for the NeoPixel strips, which tend to sag and droop on their own. 

## Troubleshooting

Most problems with this installation are caused by wiring problems. If you're getting weird behavior, or no pixel illumination:

* Check the voltage at the positive and negative terminals in each enclosure while the assembly is powered on; you should have 5 volts at each terminal. If the voltage is less than 5V, you may have a short circuit in the power line. 

Specific problems I have run into:

### One or more of the NeoPixel strips do not light up (but some do)

Usually this happens because a wire has come loose, or you've got the polarity wrong. One of the NeoPixel strips themselves could be defective. 

* Are the NeoPixel strips oriented correctly? (Check the arrow on the strip; it should be pointed *away* from the Arduino enclosure)
* Use the *NeoPixel Reel Test* assembly to check the first NeoPixel strip that isn't working. 
* is the white data line connected all the way to the first NeoPixel input? Use the continuity check function of your multimeter to be certain. 
* Check any enclosures where the NeoPixels connect to 4-pin waterproof cables; it's possible that the terminals connecting the cables to the wiring harness have come loose as the cables flexed during installation. 
* Check the voltage on the terminal board just before the NeoPixel problem: do you have 5V at the `+` and `-` terminals? 

### None of the NeoPixel strips light up

Either no power is reaching the NeoPixels, or the data signal is not reaching them for some reason. At absolute minimum, even if the PIR sensors both fail, the first NeoPixel should light up green. 

* Does the Arduino have a power light? If not, refer to "The Arduino does not power on" below.
* Use the *NeoPixel Reel Test* assembly to check your first NeoPixel strip. 
* Is the logic level shifter chip installed in the interface board? 
* Does the logic level shifter chip face the correct way? The "U"-shaped cutout should face to the right/top of the board. 
* Is the logic level shifter chip installed in the correct (rightmost) pins of the socket? 
* Check the voltage at the `+` and `-` (red and black) terminals on the arduino interface board. You should have 5 volts. If so, go "downstream" and check the power terminals on all the terminal boards between the NeoPixels and the interface board; find the loose or missing power connections. If not, refer to "The Arduino does not power on" below for troubleshooting steps. 
* Use the continuity tester on your multimeter to make certain the white "data" terminal on the NeoPixel terminal board is connected to the white "data" pin on the Arduino Interface Board. 

### One of the motion sensors isn't working

The PIR sensors work by sending a 3 volt signal down the yellow or the green wires in the ribbon cable. They're powered by the red and black wires on their terminal pins. If the PIR doesn't get power, or if the yellow or green wires don't have perfect continuity all the way down the line from the arduino to the sensor, the sensors won't work. 

* Is the Arduino power light on? If not, see "The Arduino does not power on" below. 
* Does the indicator LED come on when the PIR sensor is tripped? If so, see "None of the NeoPixel strips light up" above. 
* Is the green data line connected all the way to the nearest PIR sensor? Check continuity with your multimeter. 
* Is the yellow data line connected all the way to the farthest PIR sensor? Check continuity with your multimeter. Aren't you glad you didn't screw the lids onto all the 3D-printed enclosures?
* Test the power and ground pins where the PIR sensor connects to the terminal board; you should have 5 volts. If not, check the power and ground pins on the terminal board itself. Got power there? You have a bad terminal board. No power? There's a break somewhere in the red or the black lines running back to the Arduino Interface Board, *or* there is a short circuit somewhere. 
* Check to make certain the wires from the terminal board to the PIR sensor itself have not come loose at either end.

### The Arduino does not power on

Either the battery is dead, the power switch isn't working, the PowerBoost 1000C isn't supplying 5V to the interface board for some reason, or you've got a wiring mistake. 

* Check the leads on the power switch: are any loose? Any short-circuits?
* Is the battery charged? Plug the PowerBoost 1000C into USB. 
* Does the light turn on on the PowerBoost 1000C? The power switch? 
* Test the terminals on the DC power plug. You should have 5V coming into the interface board. If not, check your solders on the PowerBoost 1000C. (And double-check that the PowerBoost is turning on.)
* Double-check the wiring on the Arduino interface board. Make sure the red and blue power rails are connected to the red and black terminals, and that there are no short circuits. 
* Check the wiring on the Arduino: the red terminal on the interface board should connect to the `5V` pin on the Arduino Due. The black terminal on the interface board should connect to the `GND` pin. 

### The NeoPixels light up all weird when I power it on

Most likely you've got a 3-volt signal from the Arduino Due connected to the NeoPixels. Usually this is a wiring mistake. 

* Check to make certain you have pin 6 on the Arduino Due connected to the *second pin from the right* on the "top" of the interface board, and the white ribbon cable wire is connected to the *third pin from the right* on the "bottom" of the board. ("Top" and "Bottom" here are assuming you hold the board with the IC on the _right_ side, and the DC power plug on the _left_.)
* Is the logic level shifter installed correctly? 

TODO: more better troubleshooting

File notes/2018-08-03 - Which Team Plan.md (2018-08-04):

# Plan For Which Team

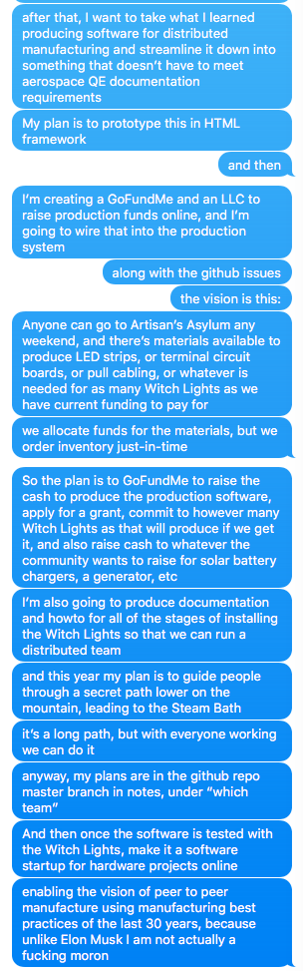
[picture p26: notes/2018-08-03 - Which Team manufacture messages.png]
Sometimes I rant to friends in text messages


* Documentation
	* Wiki
		* Making Witch Lights
			* Distributed Production
				* Anyone can contribute
				* Lower the friction and barriers to entry
			* Traveler app for phone and chromebook/mbp: Which Traveler
				* Prototype on a linux vm on mac pro ESXi host using twitter bootstrap or other responsive framework
				* Hire Beep to design it?
				* RoR? Abby? 
				* Python? Scott?
				* jruby? Jeff Cutler? 
			* Queues for each stage of manufacture
				* 3D-printing
				* Conduit & cabling
				* circuit boards (get printed from China)
					* need EAGLE experience - Steve Pomeroy?
			* Pick a queue and make some components as needed for each set in production
			* order components just-in time
				* at a makerspace, material enough to make one of each component, with instructions on chromebook
				* once you complete the job, you sign off on it, and it generates a shipping label, etc
				* also, a single set of components is drop-shipped to that makerspace
			* generate purchase orders
			* generate shipping labels and packing slips
			* work with makerspaces around the world
		* Installing the Witch Lights
			* Transport
			* Rough Setup
			* Testing
			* Final Setup
			* Battery / Maintenance
				* Volunteer Shifts
				* Charging
				* Replacing
				* Testing
				* Marking bad batteries
			* Breakdown
				* Volunteer Shifts
				* 6am Sunday (or last day of festival)
				* 2 people per set of Witch Lights
			* Post-Burn Procedure
				* Test bundled Witch Lights for basic test pattern
				* Lay out end to end
				* Remove paracord

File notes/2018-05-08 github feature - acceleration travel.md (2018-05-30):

When we create a generic metaclass for the customizeable sprites, we plan to have different Update methods, and a decision metric for the Update method to decide which to call.

One of those methods should be a Travel method, which is our term for moving from point to point and leaving a trail behind the sprite. 

Right now, in order to specify the travel destination, we call the `SetNextInflection()` method, which changes the target pixel for when the sprite enters travel mode. 

I'm thinking we should also specify a couple of other factors. 

So, `SetNextInflection()` gives us a target pixel of 149, and we're on pixel 20. 

When we created the sprite, we should have specified a few factors: 

`DefaultTravelIntervalAccelerationFactor` is the linear term for how much we change the interval while accelerating. `-1` is the current default. So, each interval, we subtract 1 from the `updateInterval` int. 

OR we could do dynamic acceleration factors based on how far we have to travel?

`DefaultTravelStartInterval` is the interval we always start with when traveling from pixel a to pixel b from a stop. `40ms` is the current default interval

`DefaultTravelMinimumInterval` basically defines our top speed assuming that V is constant. `0ms` is the current default

`DefaultTravelMaximumInterval` would define the slowest the sprite is allowed to move before stopping. 

(This may not be necessary, I'm envisioning an edge case where for some reason the interval gets set to 6 seconds between frames and we can't tell if it crashed or not.)

### Accelerating and Braking

I can envision 2 ways of handling this. 

One way, for each move, we specify a travel to one destination pixel with a positive acceleration factor, and when we reach that pixel, we specify a much shorter travel to a much closer pixel, with a more aggressive negative acceleration factor, which would smoothly slow the sprite down for an "ease in". 

Another way, we specify that traveling is a two-part process, with acceleration and braking. 

So if we want to travel 30 pixels, we'd accelerate for 20 pixels, and brake for 10, or 25 and 5, or whatever ends up looking best according to testing. The braking factor would usually be higher than the acceleration factor. 

So we could specify stuff for each sprite to give it a profile for acceleration and braking, like:

`DefaultTravelIntervalBrakeRatio` is an implementation guess, where we say "take the total number of pixels you have to travel, and multiply by this number. The result is the number of pixels back from the destination pixel you have to brake for. So accelerate until that pixel, then when you reach it, start braking." So if `DefaultTravelIntervalBrakeRatio` was `.1` then given a total number of 120 pixels to travel, we'd accelerate for 108 pixels, and brake for 12.

You'd want to round up, so that you always have at least 1 pixel of braking. 

Brake factor: do we specify this as a factor in sprite creation? Or do we do something like:

* take current interval and subtract it from `DefaultTravelMaximumInterval`: that's how much braking needs to happen over the brake distance
* divide the result by the number of pixels before the target pixel

(That's a linear brake curve, we might actually want a parabolic curve instead?)

I mean, let's assume there's no dumb assumptions in that pseudo-algorithm, what I mean is, given travel of `n` pixels, we always use `n * DefaultTravelIntervalBrakeRatio` pixels to brake, and always brake down to the same (maximum) interval. 

### Talking through the example: linear acceleration factor

So if we are traveling 120 pixels, with a default acceleration factor of -1, default brake ratio of .1, and a `DefaultTravelStartInterval` of 40ms, a `DefaultTravelMinimumInterval` of 5ms, and `DefaultTravelMaximumInterval` of 60ms, then:

* We'd multiply 120 by .1 and get 12
* 120-12 = 108; we would start accelerating towards pixel `currentPixel + 108`
* Using a linear acceleration factor of -1ms, we'd accelerate over 35 intervals, traveling 35 pixels
* Over the remaining 73 pixels, the sprite will travel at a constant maximum velocity
* The brake factor is calculated from the `DefaultTravelMaximumInterval`, current interval, and the calculated brake distance: in this case, we have 12 pixels to go from 5ms to 60ms. A naive implementation would be `(DefaultTravelMaximumInterval - CurrentInterval)/brake pixels`, or `55/12` = 4.58ms. Rounding up to the next highest int, we get 5ms. 
* So, over the 12 pixels, at each interval, we'd add 5ms to the current interval, maxing out at 60ms. 

For a much shorter move, let's say we want to move 10 pixels. 

* multiply 10 by .1, we get 1 (which isn't a great thing)
* we have 9 pixels to accelerate; starting at our default interval of 40ms, at pixel `currentPixel + 9`, `currentInterval` will be 31ms
* the brake factor calculates out at `29/1`, or 29ms in a single step

This is why I think we should be able to specify factors for shorter moves. 

### UpdateTravel method

I'm thinking that, when we transition from scanner to travel, we set the `isScanning` bool to `false` and use a `StartTravelWithAcceleration()` method to define the target pixel, the acceleration factor, the brake factor, and I'm thinking we should also be able to specify the `TravelMaximumInterval` to determine what speed we're braking down to? That way we can totally set ourselves up for a seamless transition into a pre-rendered pixel animation. 

So if we want to move n pixels in either direction, you'd specify:

* Target distance (negative moves "backwards")
* Acceleration Factor
* Brake Ratio
* Maximum Interval

At a guess, when moving 10 pixels, I would set acceleration to -4, brake ratio to .25 or .33, and maximum interval to maybe 40-50ms? And start tuning from there. 

That way, we start at 40ms, and accelerate to 12ms over 7 pixels, then over 3 pixels, the brake factor is `38/3 = 12.66`, rounded to 13, so we'd brake by 13ms each interval to a maximum of 50ms at the target pixel.  

### Calculating smooth acceleration over distance?

Do we want to try, instead of using a fixed linear acceleration factor, to calculate that factor based on the distance we're accelerating over? 

This could be an optional thing for travel moves?

It'd work like the brake calculation: figure out how many pixels we're accelerating for, then divide the difference between `currentInterval` and `TravelMinimumInterval` over those pixels, and the result is how many ms to accelerate by each interval? 

So, for travel moves, you'd say "here's my start speed, here's my maximum speed, here's my minimum speed, here's my brake distance ratio, here's the pixel I'm traveling to" and it would calculate out the acceleration factors for you.

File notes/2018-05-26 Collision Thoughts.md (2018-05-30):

# Collisions

It may be desired to have sprites interact with each other when they come near each other. Most generally, these can be called "collisions" in the physics sense. The sprites needn't touch, or even be that close to each other.

## Definitions

A "collision" in this sense is the change in a sprite's default behavior due to the proximity of another sprite.

A collision occurs when a sprite's "trigger condition" is met. When this condition is true, the sprite will become "triggered" and begin its "collision behavior".

Collision behaviors may be a change in the sprite's velocity, a change in its physical properties (like color o shape), a change in its behavior (scanning or lurking), or even its death (setting `isDone` to true).

Most of what we think of as real-world collisions are bidirectional. Each object experiences the collision in its own way. However, this doesn't have to be the case. A bug minding its own business, when hit by a truck windshield, is effectively a unidirectional collision. While momentum is conserved, the momentum of the bug doesn't significantly change that of the truck, so this is effectively a one-sided collision.

It's the intention that each sprite, when triggering, is responsible for determining its own behavior after the collision. Sprites can only identify when they've been triggered, and act accordingly. This also matches the general expectation in object-oriented development that classes' behaviors be independent.

## Sample Code

This is literally just some basic thoughts on the matter and I haven't devoted more than two brain cycles to any of this. C#-ish pseudocode follows.

    SpriteManager::Update() {
        foreach (Sprite sprite in spriteVector) {
            sprite->Update();

            // Performance warning! This is effectively O(n^2), since each time we update we 
            // have to cross-check each other existing sprite. Worse, the other sprite may
            // have moved and caused us to trigger, so we can't even skip this if Update() 
            // returns false and tells us we didn't do anything.

            foreach (Sprite otherSprite in spriteVector except the current one) {
                otherSprite->HasCollided(sprite);
            }
        }
    }

    Sprite::HasCollided(Sprite *otherSprite) {
        // e.g., the positions of the two sprites are within a given distance and the sprite
        // is a scanner sprite. That is, this sprite is visible to scanners but invisible to 
        // other types.

        if (otherSprite->currentPixel - this->currentPixel < COLLISION_DISTANCE &&
            otherSprite instanceof ScannerSprite) {
            this->Collide();
        } 
    }

    Sprite::Collide() {
        // I've collided. What do I do?

        this->color = RED;  // Change my color.
        // or
        this->velocity = -this->velocity;   // Start going in the opposite direction.
        // or
        this->isScanning = ! this->isScanning;
    }

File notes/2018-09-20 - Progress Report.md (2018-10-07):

# Is too much. I sum up.

The last few months have been tumultuous. 

# Animation Test

Before Firefly 2018, I did a quick setup of the Witch Lights in my front yard. I meant to capture video of last year's 3.0 build animation code (which was still running on the Witch Lights production hardware), then upload the 4.0 animation code from this year. 

I have a great deal of footage of the development and testing of Witch Lights 4.0, but that's on my upstairs test rig. The physical arrangement of the LED strips in space changes the effect of the Witch Lights, and I wanted to capture that.

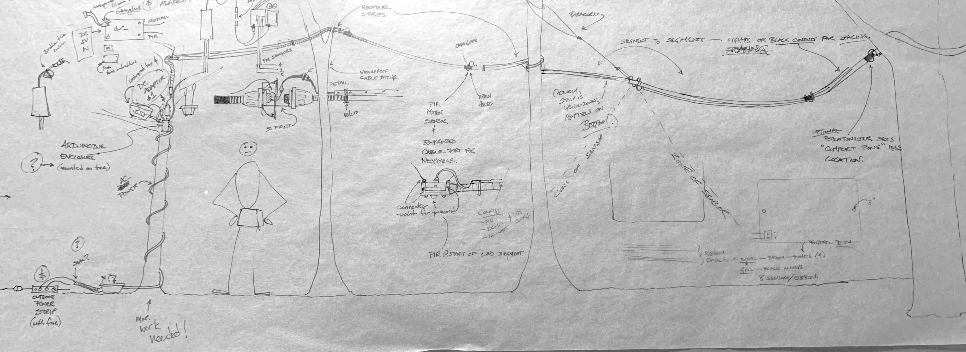
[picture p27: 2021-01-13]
docs/wl-v1-trace-concept.jpg

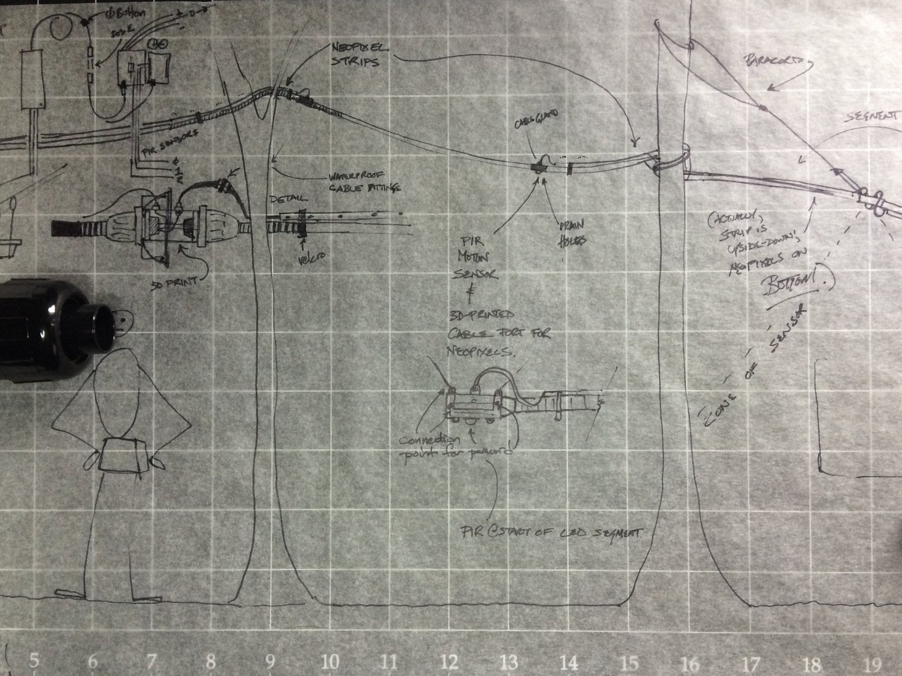
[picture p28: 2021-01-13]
docs/wl-v1-concept.jpg

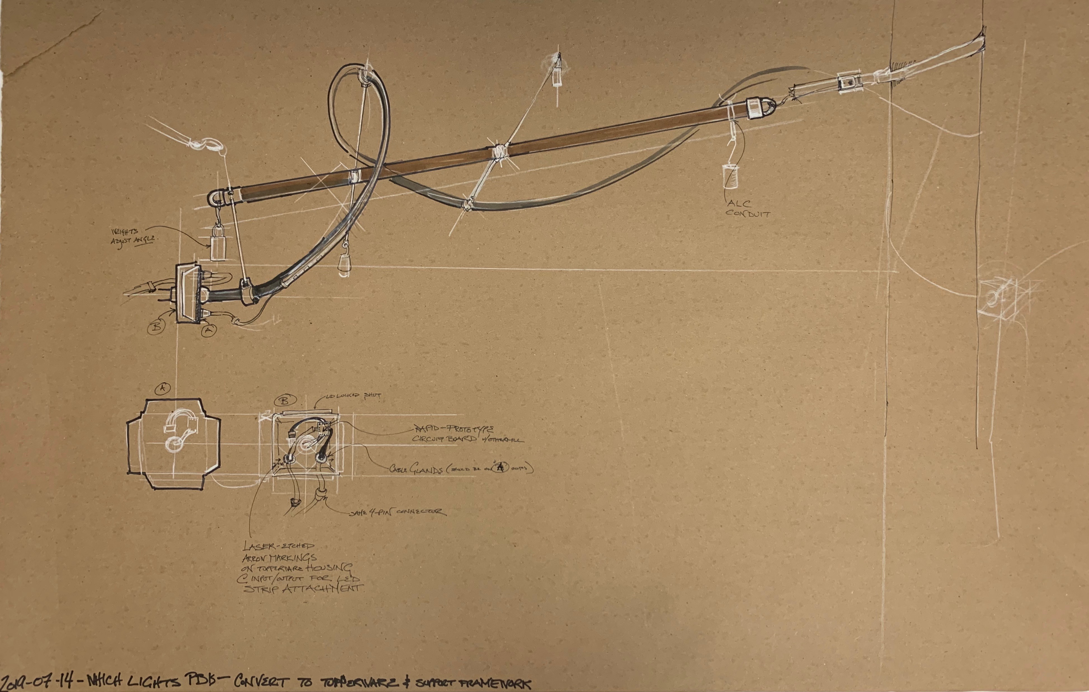
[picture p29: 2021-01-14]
docs/2019-07-14--hardware-upgrade.jpg

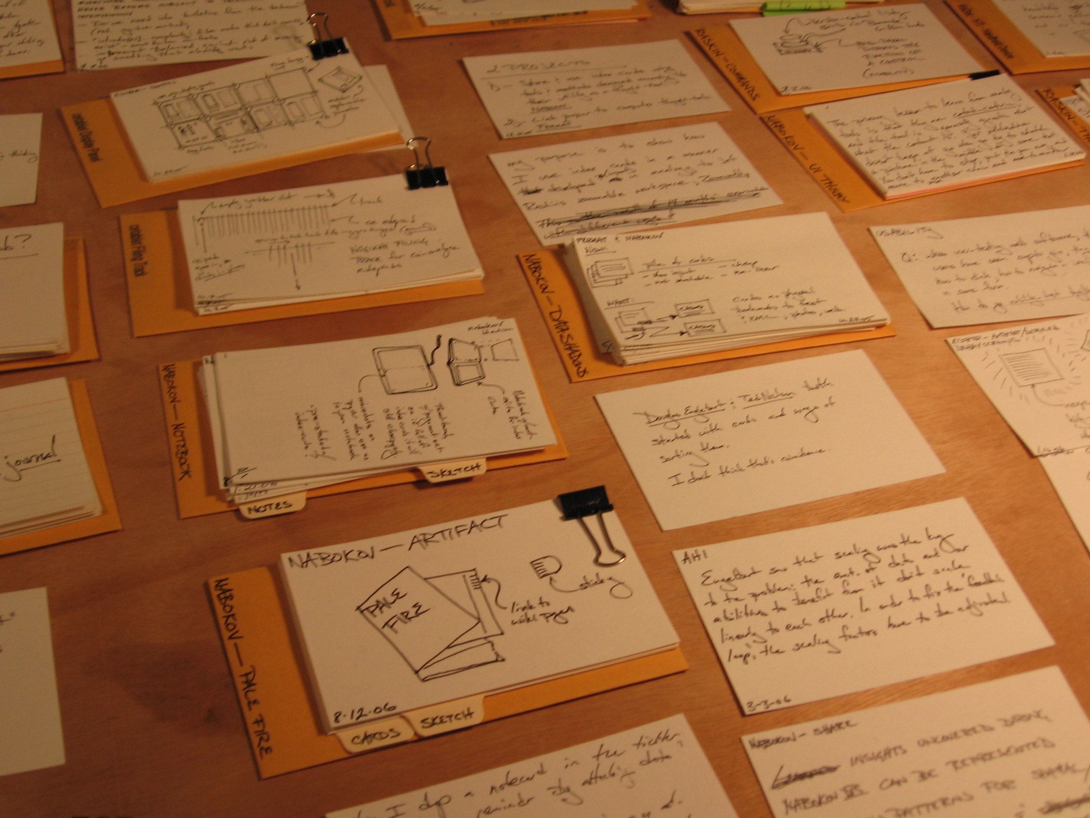
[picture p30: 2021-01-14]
docs/2006-card-table2.jpg

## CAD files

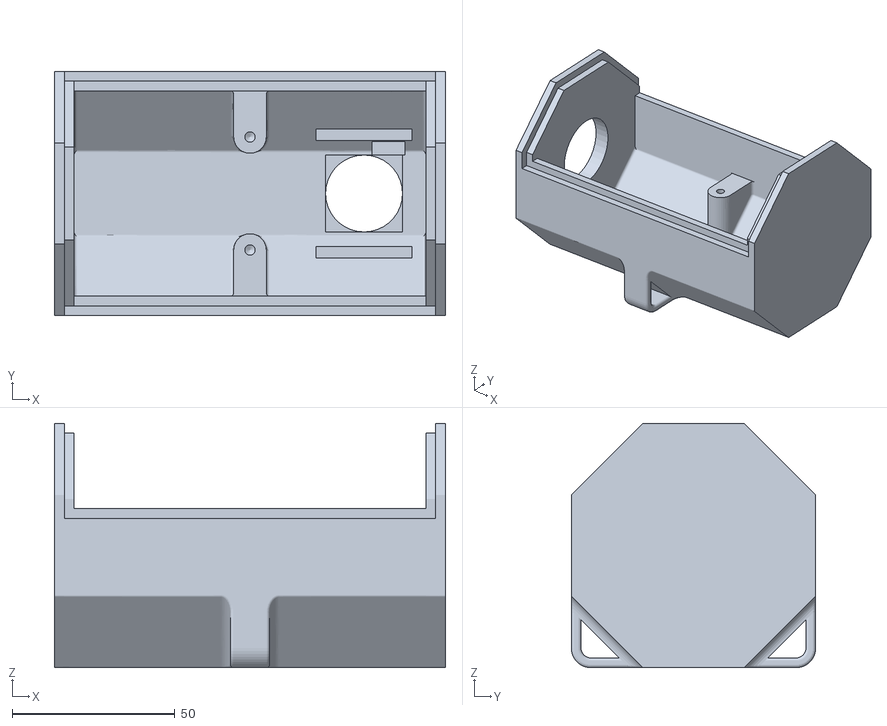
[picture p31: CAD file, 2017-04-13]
STLs/wl-seeedpir-terminus.STL
120.0 x 75.0 x 75.0

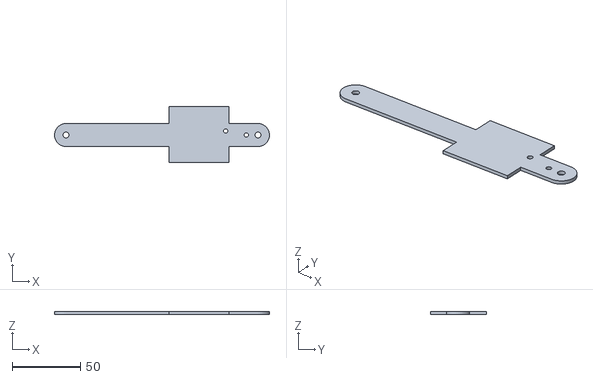
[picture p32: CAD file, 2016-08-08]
STLs/wl-pcb-mount-5-pin.STL
158.0 x 41.2 x 2.00

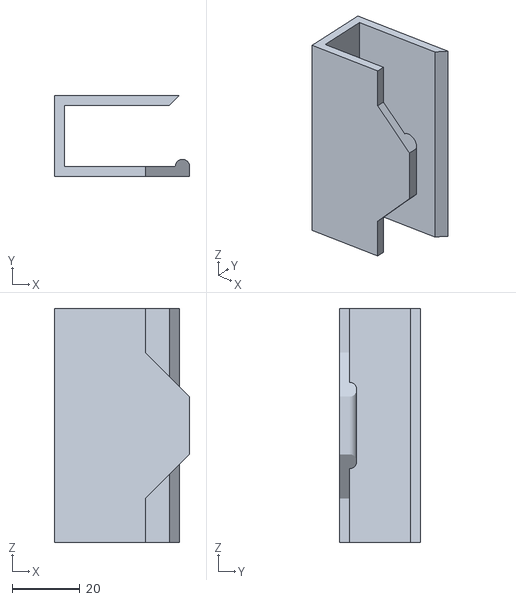
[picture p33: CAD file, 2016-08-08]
STLs/wl-battery-clip.STL
39.9 x 24.0 x 69.0

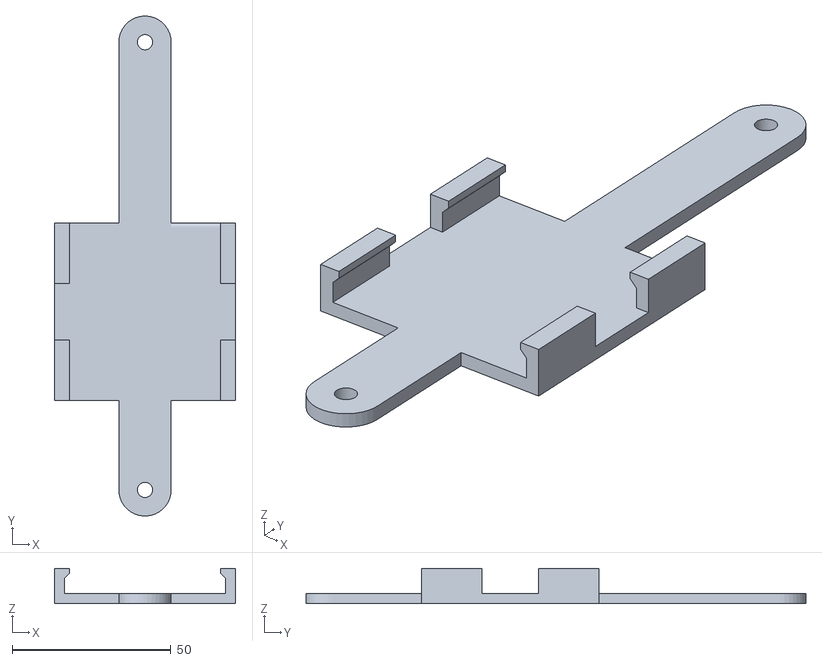
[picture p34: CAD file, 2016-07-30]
STLs/wl-pcb-mount-10-pin.STL
57.2 x 157.5 x 11.1

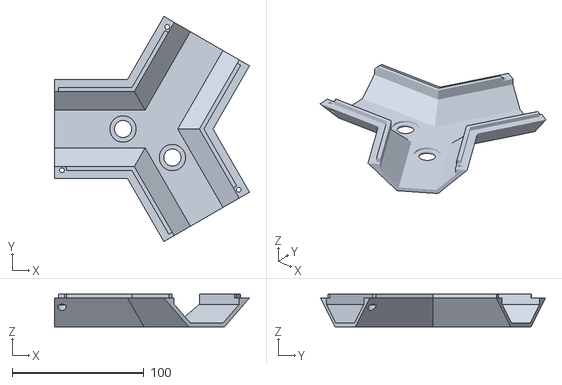
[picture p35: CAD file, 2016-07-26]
STLs/wl-3-sided-lid-2-hole.STL
148.0 x 170.9 x 25.0

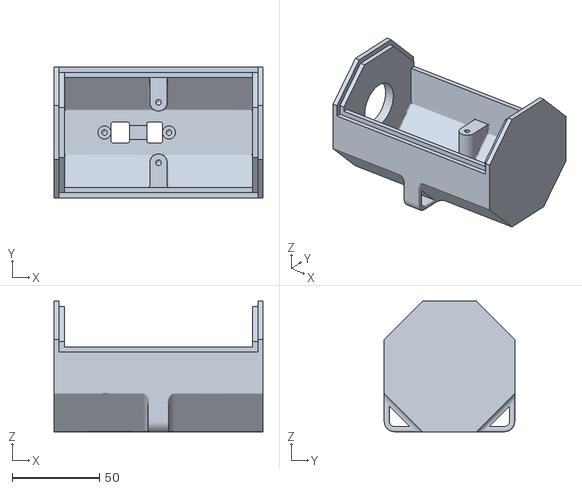
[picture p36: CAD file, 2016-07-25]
STLs/wl-sharp-terminus.STL
120.0 x 75.0 x 75.0

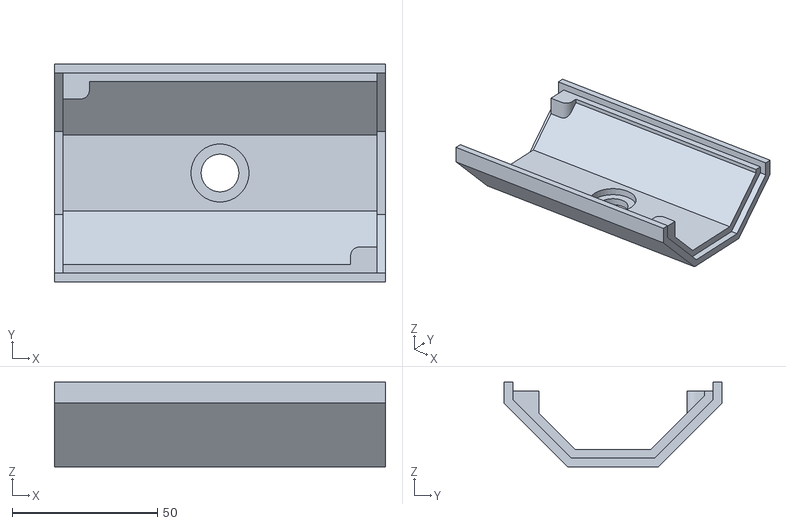
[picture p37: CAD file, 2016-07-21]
STLs/wl-lid-1-hole.STL
114.0 x 75.0 x 29.2

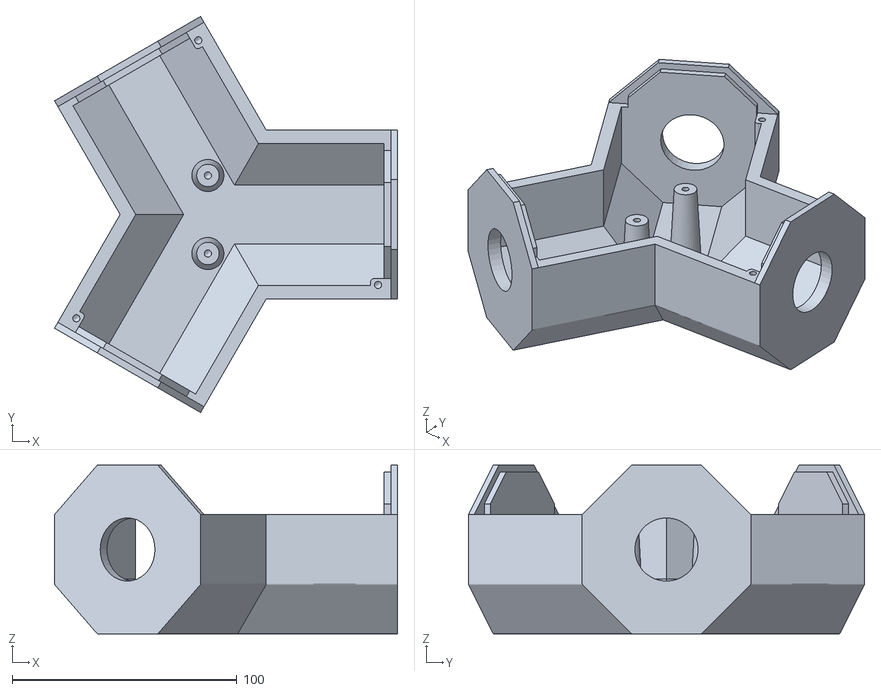
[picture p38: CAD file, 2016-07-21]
STLs/wl-3-sided.STL
152.5 x 176.1 x 75.0

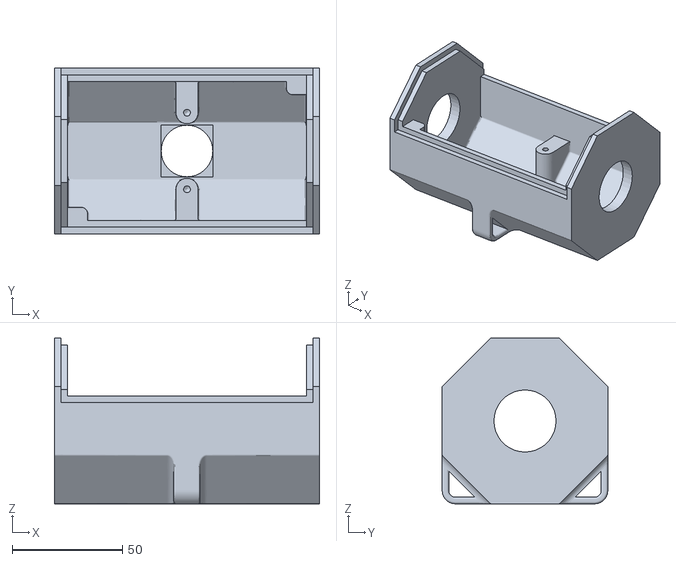
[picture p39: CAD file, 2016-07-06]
STLs/wl-pir.STL
120.0 x 75.0 x 75.0

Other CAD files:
STLs/wl-lid-2-hole.STL
STLs/wl-3-sided-lid-0-hole.STL
STLs/wl-sharp.STL
STLs/wl-pir-terminus.STL
STLs/wl-nopir.STL
STLs/wl-lid-0-hole.STL

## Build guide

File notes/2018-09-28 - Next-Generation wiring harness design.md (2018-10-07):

# Which List

Final generation Witch Lights would have:

1. High gauge, low-resistance full-length power harness wires pulled through fully assembled harness using best-friends cable snake and wooden dowel (and a true human friend willing to assist)
2. 3.3v PIR motion sensors at each end of Witch Lights
3. lathe-turned aluminum and wood  (Someday goal: recycle scrap from Alloy in solar smelter up in the clearing in the woods) 
4. Stands and stakes for free-standing installation
5.

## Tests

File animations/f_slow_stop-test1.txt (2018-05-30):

//                       123456789012345678901
strcpy(afc_f_slow_stop, "123456788            ");
strcat(afc_f_slow_stop, " 123456788           ");
strcat(afc_f_slow_stop, "  12345678           ");
strcat(afc_f_slow_stop, "   12345678          ");
strcat(afc_f_slow_stop, "    1234568          ");
strcat(afc_f_slow_stop, "     1234568         ");
strcat(afc_f_slow_stop, "      123458         ");
strcat(afc_f_slow_stop, "       12348         ");
strcat(afc_f_slow_stop, "        12348        ");
strcat(afc_f_slow_stop, "         1238        ");
strcat(afc_f_slow_stop, "          158        ");
strcat(afc_f_slow_stop, "           68        ");
strcat(afc_f_slow_stop, "            68       ");
strcat(afc_f_slow_stop, "            78       ");
strcat(afc_f_slow_stop, "            88       ");
strcat(afc_f_slow_stop, "            88       ");
strcat(afc_f_slow_stop, "            88       ");
strcat(afc_f_slow_stop, "            88       ");
strcat(afc_f_slow_stop, "            88       ");
strcat(afc_f_slow_stop, "            88       ");
strcat(afc_f_slow_stop, "            88       ");
strcat(afc_f_slow_stop, "            788      ");
strcat(afc_f_slow_stop, "            688      ");
strcat(afc_f_slow_stop, "            588      ");
strcat(afc_f_slow_stop, "            488      ");
strcat(afc_f_slow_stop, "            3788     ");
strcat(afc_f_slow_stop, "            2688     ");
strcat(afc_f_slow_stop, "            1588     ");
strcat(afc_f_slow_stop, "            14788    ");
strcat(afc_f_slow_stop, "            13688    ");
strcat(afc_f_slow_stop, "            125788   ");
strcat(afc_f_slow_stop, "            124688   ");
strcat(afc_f_slow_stop, "            1235788  ");
strcat(afc_f_slow_stop, "            12346788 ");
strcat(afc_f_slow_stop, "            123456788");
strcat(afc_f_slow_stop, "                     ");
strcat(afc_f_slow_stop, "                     ");

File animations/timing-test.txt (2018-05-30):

//                       1234567890123456789012345678901234567890123456012345678901
strcpy(afc_timing-test, "123456788                                                 ");
strcat(afc_timing-test, "1234567888                                                ");
strcat(afc_timing-test, "  1234567888                                              ");
strcat(afc_timing-test, "     1234567888                                           ");
strcat(afc_timing-test, "       123456677888                                       ");
strcat(afc_timing-test, "        1223344556667788                                  ");
strcat(afc_timing-test, "         111122233344556667788                            ");
strcat(afc_timing-test, "              11111222233344556667788                     ");
strcat(afc_timing-test, "                   11111222333444555666788                ");
strcat(afc_timing-test, "                          1111112223344556788             ");
strcat(afc_timing-test, "                                 11111223456788           ");
strcat(afc_timing-test, "                                     11123456788          ");
strcat(afc_timing-test, "                                        1123467831        ");
strcat(afc_timing-test, "                                            12468531      ");
strcat(afc_timing-test, "                                             11386421     ");
strcat(afc_timing-test, "                                              1287543211  ");
strcat(afc_timing-test, "                                               18865432211");
strcat(afc_timing-test, "                                               886443211  ");
strcat(afc_timing-test, "                                              88765431    ");
strcat(afc_timing-test, "                                            4887654321    ");
strcat(afc_timing-test, "                                            4886421       ");
strcat(afc_timing-test, "                                            138831        ");
strcat(afc_timing-test, "                                            138831        ");
strcat(afc_timing-test, "                                            138831        ");
strcat(afc_timing-test, "                                            138831        ");
strcat(afc_timing-test, "                                            138831        ");

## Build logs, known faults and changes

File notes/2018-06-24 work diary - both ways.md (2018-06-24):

# Going Both Ways

Firefly is a week from Tuesday, and I need to finish one critical piece of functionality: I want my FaerieSprites to travel in both directions. Or, as the code comment says, `TODO: Faeries go both ways`. 

Here's what I'm having some trouble with: when sprites go off the "edge" of the addressible LED area that corresponds to their travelDirection, we mark the sprite "done" and it gets deleted from RAM. The logic in question is in the `UpdateTravel()` method; after we move CurrentPixel we check to see if we've reached the end of the road:

	// Terminate if we go off the end of the strip
	// TODO - make this work with whatever pixel is specified as the terminal pixel, with the comparison working with either direction?
	if (currentPixel > NUM_LEDS) {
		FadeOutTrail(NUM_LEDS - 1, 255, -1); // TODO - make this work on each end of the LED strip
		this->MarkDone();
	}

So the way I started to address this is, I edited the constructor for `FaerieSprite` and made it accept 3 parameters:

	FaerieSprite(int travelDirection, int startPixel, int endPixel) : Sprite() {

My thinking was, specify the general direction of travel, the pixel you're starting at, and the pixel you want to reach and terminate the sprite at. 

On reflection, though, to start with, I think we can get rid of `endPixel` as a parameter. 

Generally `endPixel` is going to be `NUM_LEDS` if `travelDirection` is 1, and it's going to be 0 if `travelDirection` is -1. And generally you want to check if `currentPixel > NUM_LEDS` if `travelDirection` is 1, and if `travelDirection` is -1, you want to check if `currentPixel < 0` instead. So that's a simple if / else statement. Unless there's a better, mathy way to do it. It's 4am and I haven't really been sleeping lately, so I'm not going to bang my head on it right now. Feel free to tell me a better way. 

_OK_, I think, _but what if I just check to see if `currentPixel < 0 || currentPixel > NUM_LEDS`?_ That way, if the sprite goes off either end of the "screen" (the length of the LED strip), we terminate it. That's nice and elegant, *but* there's a complication: when `FaerieSprite` spawns, its `startPixel` value is actually -3. That lets it "enter" from "offscreen", as it were, which is far more natural-looking a way of appearing than just flashing into existence in place. So if I implemented that comparison as the terminal logic, I'd need a way of preventing `FaerieSprite` from being terminated the instant it spawns. 

One idea that comes to mind is, add an `int updateCount` to the class, and put `updateCount++` in the `Update()` method. And only run the `currentPixel` comparison for `MarkDone()` if `updateCount > 10`. Or `25`, or something similar. The point is, give each sprite a grace period that lets it move into the "safe" zone of between 0 and `NUM_LEDS`. 

I'm pretty sure either would work.

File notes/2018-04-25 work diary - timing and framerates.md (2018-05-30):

# Witch Lights Animation Progress: Timing And Framerates

I made the changes to the [Witch Lights][wl] animation [from last night][lastnote], and am happy with the progress so far. It's not done, but progress is being made. 

[wl]: https://witchlights.com/
[lastnote]: https://i2nk.co/notes/2018/4/24/rough-animation-tests-skid-stop

[Skid-stop animation third attempt 2018-04-25][ss3] on Vimeo

[ss3]: https://vimeo.com/266530739

This is a big improvement. Interestingly, on my other computer, the keyboard repeat rate is faster, which results in a higher framerate. That's making a big difference in the effect of the animation. 

In this video above, the sprite appears to accelerate a bit too quickly, and then when it stops short, the tail isn't long enough. 

[Skid-stop animation fourth attempt 2018-04-25][ss4] on Vimeo

[ss4]: https://vimeo.com/266531200

Above, I adjusted the frame rate down (by using the keyboard control panel), and now the speed of acceleration and braking seem ok. But, when the sprite stops short, the tail doesn't shrink from the left quickly enough. 

So: _framerate is a variable to control for_. 

I have to upload my code to the Witch Lights development board and watch the actual animation on the NeoPixels to see what kind of framerate I'm getting.

So, next actions:

* Connect development Arduino to my mac and upload the current code

* Connect a simple push-button up to the sensor pin on the Arduino to simulate the motion sensor

* Take the 5-meter cheapo NeoPixels I just got from AliExpress and connect them to my NeoPixel strip test rig, which will verify that the pixel strip is good

* Hook the (hopefully good) pixel strip to the development board, and power it on. If everything is good, I'll see a pride-flag test pattern

* Test the current known-good code with the push button, verify that it triggers sprite object creation and animation

* Create a new `Animation Test Sprite` class, copying the current Sprite object class, and tell the motion sensor objects to trigger generation of that class, not the default class

* Export the animation to CSV from Excel

* Run the [csv2cpp python script][csv2cpp] on that CSV file and copy the generated code

[csv2cpp]: https://github.com/jdimauro/witch-lights/blob/animation-experiments/python/csv2cpp.py

* Insert the generated code into the appropriate segment of the Witch Lights Arduino sketch, and compile/upload the code to make sure nothing breaks.

* Modify the `Animation Test Sprite` class so that in _Scanner_ mode, it looks at the array of strings tagged with the animation name. 

* Also change the global variables for animation frame width and animation frame count (create new globals for now, refactor this later)

* Compile and upload the code, which -- *in theory* -- should result in the Witch Lights animating my new sprite animation when I hit the go button. 

Simple. 

Later, I'll work out a master class for sprites with different animations, and make all the different animation sprites children of that, but for now it's gonna be messy. 

Because the point is to _see the framerate of the animation on the Arduino and NeoPixels_. 

And then I'll adjust the framerate on my computers (by messing with Keyboard preferences) to match as closely as possible. 

What a horrible hack this is. I'm absurdly proud.

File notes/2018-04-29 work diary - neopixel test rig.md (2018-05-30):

# Tool Kit: NeoPixel Reel Tester

One of the problems I anticipated facing while on-site with the Witch Lights is the failure of a NeoPixel strip. Because of the architecture of the lights, a bad strip will take out not just its five meter section of LEDs, but also all strips plugged in downstream. 

As one diagnostic tool in my on-site kit, I have this Arduino Uno, which is linked up to one of the waterproof 4-pin connectors that the Witch Lights pixel strips have on each end. To use it, you simply plug one end of a NeoPixel strip into it, and plug in the battery. 

It runs a color test pattern down the strip, which tells you that the strip works, and also that it doesn't have any bad pixels. So that's what I put it together for. 

Right now, though, it's coming out because I'm going to plug it into this new 5-meter pixel strip, which will be used for my workshop test rig.

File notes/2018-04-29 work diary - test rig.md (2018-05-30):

# Progress: Building the test rig  
### 3:33 PM — Sunday; April 29, 2018 ###

Here we are, about to upgrade the test rig on my workbench. 

The current build of [witchlights-fastled.ino][ino] does not run on the Arduino Mega. It gives memory errors. I don't want to get bogged down with memory optimization at this point in the game. So I'm replacing it with an Arduino Due.

[ino]: https://github.com/jdimauro/witch-lights/blob/master/arduino/witchlights-fastled/witchlights-fastled.ino

The Due I'm installing is a drop-in replacement module for the control board of the Witch Lights. That way, I'm testing on the exact hardware that will be in production. 

The LED strip is a five-meter WS2812B addressible LED strip, with 30 LEDs/meter. Just like the Adafruit NeoPixel strips I used in production, except without the waterproofing. Which won't matter in my home workspace, I sincerely hope.

***

And that was fast. 

The test rig is in place, and the WS2812B strip works fine. 

[Witch Lights test rig in place][rig]:

[rig]: https://vimeo.com/267138921

Next up is creating a new Sprite animation subclass, editing its `scanner` routine to map to the animation that I was [working on the other day][callback]. 

[callback]: https://i2nk.co/notes/2018/4/25/witch-lights-animation-progress-timing-and-framerates

Speaking of which, it looks like this exported into the arduino sketch format:

	//                       1234567890123456789012345678901234567890123456012345678901
	strcpy(afc_timing-test, "123456788                                                 ");
	strcat(afc_timing-test, "1234567888                                                ");
	strcat(afc_timing-test, "  1234567888                                              ");
	strcat(afc_timing-test, "     1234567888                                           ");
	strcat(afc_timing-test, "       123456677888                                       ");
	strcat(afc_timing-test, "        1223344556667788                                  ");
	strcat(afc_timing-test, "         111122233344556667788                            ");
	strcat(afc_timing-test, "              11111222233344556667788                     ");
	strcat(afc_timing-test, "                   11111222333444555666788                ");
	strcat(afc_timing-test, "                          1111112223344556788             ");
	strcat(afc_timing-test, "                                 11111223456788           ");
	strcat(afc_timing-test, "                                     11123456788          ");
	strcat(afc_timing-test, "                                        1123467831        ");
	strcat(afc_timing-test, "                                            12468531      ");
	strcat(afc_timing-test, "                                             11386421     ");
	strcat(afc_timing-test, "                                              1287543211  ");
	strcat(afc_timing-test, "                                               18865432211");
	strcat(afc_timing-test, "                                               886443211  ");
	strcat(afc_timing-test, "                                              88765431    ");
	strcat(afc_timing-test, "                                            4887654321    ");
	strcat(afc_timing-test, "                                            4886421       ");
	strcat(afc_timing-test, "                                            138831        ");
	strcat(afc_timing-test, "                                            138831        ");
	strcat(afc_timing-test, "                                            138831        ");
	strcat(afc_timing-test, "                                            138831        ");
	strcat(afc_timing-test, "                                            138831        ");
	
So that's some progress. Taking a break now.

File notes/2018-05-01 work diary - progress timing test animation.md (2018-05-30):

# Progress: Timing test

After some trial and error, I generated an `AnimationTestSprite` class, and re-defined all of the `char` and `CRGB` structs to load my generated pixel art animation into memory. And told the MotionSensor object to spawn one when it detects motion. (Or when I push the test button.)

And the Arduino Due crashed so hard, I had to force erase its memory. 

Welp. 

I'll get into what caused it later, but I hunted down the cause and fixed it. So I just watched my first pixel art animation on the live test rig. 

[Witch Lights Animation Test 1: Timing Test][video]:

[video]: https://vimeo.com/267517193

The frame rate is *much* faster than I thought. That's good. It can also be adjusted with an `UpdateInterval` variable, so that's also good. 

I'll go into the cause of the crash at a later date, because it's going to affect my strategy and approach to the whole thing. But for now I'm happy with this progress.

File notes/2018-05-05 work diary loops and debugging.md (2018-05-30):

# Loopy Debug is my new Frank Zappa cover band

Currently working on looping animations for when the sprites pause.

Here's one in Excel

And animated

I would show you what it looks like on the NeoPixels, but the Arduino crashes when it tries to spawn the sprite object, so I've gear shifted from animation design mode into debug mode. 

## How I understand what the code does

So what's happening is, the Arduino bootloads, runs through all the globals at the top, stuff like:

	#define afc_l_pulsar_a_ANIMATION_FRAME_WIDTH    24
	#define afc_l_pulsar_a_ANIMATION_FRAMES         22
	
Which is where I set the parameters for each animation. In this case, you've got 22 frames of animation, each one 24 pixels wide. It also sets all the other parameters to tune the global travel acceleration rate, sprite pixel velocity, and how far each sprite travels before playing the idle animation. 

We then go on to use the FastLED library to create a `CRGB` struct to contain the color values we will write to the NeoPixel strip: 

	CRGB leds[NUM_LEDS];

`CRGB` structs are a range of memory that contain 3 bytes for each LED: the red, green, and blue color values. So the amount of SRAM that the struct takes up is basically `[NUM_LEDS] * 3` bytes. 

To animate the pixels that I've been designing in Excel, what happens is, we define a `char` and a `CRGB` struct for each animation, and each is `FRAME_WIDTH * FRAMES` long. In the case of the pulsar loop above, that's 24 by 22, which is 528. 

A `char` is one byte per entry, and we already know a `CRGB` is three, so that means we're taking up 528 times 4 bytes, or 2.06K. And we have a total of 96K of SRAM to execute the entire system, including all pre-rendered animations. 

Actually, we have 32K. See, the Arduino Due has a 32K bank of SRAM, and a 64K bank of SRAM, and I'm not sure how they interact, but I *can* say for certain that if you define too many `CRGB` structs and `char`s, the Arduino Due crashes on boot, and our best guess for memory usage is that we're around the 30-33K mark. I'll get back to that in a bit. 

So we define all the animations that we're going to run in this build, and then we define our function prototypes and our object classes. I won't get into the structure of the classes, except to say that there's a `SpriteVector` and `SpriteManager` class, which combine to handle the creation, lifecycle, and deconstruction of each animation sprite. 

There is also the `LoopTestSprite` or `FragmentTestSprite` classes, which are subclasses of the `Sprite` class. Each different sprite class currently has code to move from point to point, and to play a pre-rendered animation for a certain number of repetitions when it reaches its destination pixel. It then moves to the next destination pixel, loops, and repeat until the whole thing goes off the pixel grid, at which point the object is marked `is_done`. At which point, `SpriteManager` deletes the object from memory on its next run-through. 

So that's where the classes are defined. If the Arduino passes safely through those, we reach the point where we create our permanent objects: 

	InfraredSensor *sensor1;
	InfraredSensor *sensor2;

	SpriteManager *spriteManager;

	bool isBooted;
	bool testSpritesCreated;

	int starttime = millis();

So we've got 2 infrared sensors per strip of the Witch Lights, and they get created and assigned the names `sensor1` and `sensor2`. 

We boot up `SpriteManager`, prime some `bool`s, and set the `starttime` value, and then it's time to run `setup()`. 

	void setup() {
	    createColorsets();
	    createAnimationFrames();

	    isBooted = false;
	    testSpritesCreated = false;

	    spriteManager = new SpriteManager();

	    sensor1 = new InfraredSensor(PIR_SENSOR_1_PIN);
	    sensor2 = new InfraredSensor(PIR_SENSOR_2_PIN);

	    resetStrip();
	}

`setup()` reads our arrays of predefined color sets into RAM, and then runs the `createAnimationFrames()` function. Which reads all of the animations defined within the function into the `char`s we created earlier. So now, in memory, we have a full set of pixel animations, in the form of `char` structs with the animation's name.

Setup also sets `isBooted` and `testSpritesCreated` to false, which are bits that trigger a test pattern at the beginning of `loop()` later. And it links the infrared sensors to their appropriate input pins, resets the NeoPixel strip, and we're ready for the main `loop()`.

`loop()` is the main engine of an Arduino project. It cycles forever, and each time, you have a chance to do some logic. In this case, we run a rainbow flag test pattern down the length of the NeoPixel strips, which gives us a nice way to test the strips as the installation is assembled. 

After that (which only runs once), we check `sensor1`, check `sensor2`, create the appropriate sprite object if either is triggered. So when someone walks by the Witch Lights, an animation sprite is called into memory. But the sprite object only knows how to respond to `Update()` calls from `SpriteManager`: it won't do anything on its own. 

So `loop()` calls `spriteManager->Update();` last of all, and then the loop repeats. 

Lots of stuff happens behind the scenes when you call `Update()` of course. But we'll get into that as we need it. Right now, I'm finishing the talk-through of the whole boot cycle of the `witchlights-fastled.ino` sketch, because right now, the Arduino is crashing before it draws the new animation sprite I just defined. 

## When your shit crashes

A few days ago, when I was just learning to create custom animation sprites, I tried to define all the animations I had converted at once. I knew animations took up SRAM, but thinking that I had 96K to play with, I wasn't concerned about SRAM usage yet. 

The Arduino crashed so hard I had to manually erase its flash RAM before I could reprogram it again. For reference: that's pretty bad. 

In that case, it crashed while creating the `char` and `CRGB` structs, before it reached `setup()`. So the Arduino would turn on, but nothing else would happen. 

Today's problem is different. 

Today, when I turn on the Arduino, it plays the test pattern, which means it's made it all the way through everything we just defined, to the `loop()`, and at least started the main loop. 

But when I activate `sensor1` with a pushbutton, nothing happens. 

So something ain't right. 

For comparison, here is what I have defined in memory for animation: 

	char afc_w8v1r[ANIMATION_FRAME_WIDTH * ANIMATION_FRAMES];
	CRGB af_w8v1r[ANIMATION_FRAME_WIDTH * ANIMATION_FRAMES];

	char afc_f_slow_stop[afc_f_slow_stop_ANIMATION_FRAME_WIDTH * afc_f_slow_stop_ANIMATION_FRAMES];
	CRGB af_f_slow_stop[afc_f_slow_stop_ANIMATION_FRAME_WIDTH * afc_f_slow_stop_ANIMATION_FRAMES];

	char afc_f_slow_stop_c[afc_f_slow_stop_c_ANIMATION_FRAME_WIDTH * afc_f_slow_stop_c_ANIMATION_FRAMES];
	CRGB af_f_slow_stop_c[afc_f_slow_stop_c_ANIMATION_FRAME_WIDTH * afc_f_slow_stop_c_ANIMATION_FRAMES];

	char afc_l_pulsar_a[afc_l_pulsar_a_ANIMATION_FRAME_WIDTH * afc_l_pulsar_a_ANIMATION_FRAMES];
	CRGB af_l_pulsar_a[afc_l_pulsar_a_ANIMATION_FRAME_WIDTH * afc_l_pulsar_a_ANIMATION_FRAMES];

Looking at this, we have:

* `afc_w8v1r` is the original animation sprite from last year, defined backwards for sprites heading in the "reverse" direction from `sensor2`. 

* `afc_f_slow_stop` is the [Better slow stop go][afc_f_slow_stop] animation that I was testing a couple days ago. 

* `afc_f_slow_stop_c` is an experimental variation of that animation, using manual anti-aliasing for slow pixel-to-pixel movements.

* `afc_l_pulsar_a` is the first loop test, featured at the top of this post. 

[afc_f_slow_stop]: https://i2nk.co/notes/2018/5/2/progress-better-slow-stop-go

When I first uploaded this sketch, in the `sensor1` check in `loop()`, we had:

    if (sensor1->IsActuated()) {
        Sprite *s1 = new FragmentTestSprite();
        // Sprite *s1 = new LoopTestSprite();

        if (! spriteManager->Add(s1)) {
            delete s1;
        }
    }

And pressing the sensor button would spawn a "slow stop go" sprite. Great. 

So I changed it to: 

    if (sensor1->IsActuated()) {
        // Sprite *s1 = new FragmentTestSprite();
        Sprite *s1 = new LoopTestSprite();

        if (! spriteManager->Add(s1)) {
            delete s1;
        }
    }

And now, when you hit the sensor button, nothing happens. 

Huh. 

OK, so. 

Change it back? Sprite spawns. Change it again? Nothing happens. 

So it's *consistent*, whatever it is. That's a bonus. Consistent means repeatable. 

My first thought was, what did I do wrong in the `LoopTestSprite()` class definition that I didn't do in `FragmentTestSprite()`? So I did a diff between the two. 



And for the life of me, I can't find anything in the `LoopTestSprite()` that's different *and* is Arduino-crashingly bad. That's the differences above. On the left, the sprite that runs, and on the right, the one that don't. 

Is it SRAM usage? 

`afc_f_slow_stop`, which *does* run, is 4.32K in SRAM. 

`afc_l_pulsar_a`, which *does not* run, is 2.06K in SRAM. 

We can't rule that out, but it seems unlikely. 

## So what now, smart guy?

Welp. 

Fortunately, there's a `debug()` function, which lights up a specific LED when you call it. 

In the past, this was used to show the size of the SRAM heap while the Arduino ran. That helped greatly to identify memory leaks. 

What I can do with it now is, I can place `debug(20)` at the start of `loop()`, `debug(21)` at the next step, 22 at the next, and so on, and put debug statements into the sprite construction logic of the sprite that *works*, and do a control experiment to make sure I can identify all the working pieces of that sprite doing their thing. As the sprite is constructed and runs through the logic to process the animation `char` into `CRGB` frames, the most easily-seen LEDs under my desk will turn on, one by one. 

(And I'll be checking that into git for sanity's sake.)

Once that's done, I will change the animation logic values in that sprite to point at the animation for `LoopTestSprite()`. 

Why? Because I just tested the debug logic, and if I used copy and paste or hand-typed all the debug into `LoopTestSprite()`, I'm running the risk of a typo or mistake causing it to light up the wrong LEDs or malfunction in some other unknown way. 

So I will modify the sprite to run the new animation, compile, and run it on the Arduino. At which point... I will probably learn something unexpected. That's how it usually happens. 

But for now, rain clouds are moving in, and I'm going to sit on my screened-in back porch and watch the rain. Animation can wait.

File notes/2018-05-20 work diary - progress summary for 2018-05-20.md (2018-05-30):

# Progress summary 2018-05-20

[Algorithmic fading trails using FastLED libraries][vid1]

[vid1]: https://vimeo.com/271001287

## DimTrail() function

Last year, we were seriously concerned about the performance of the Arduino while animating 4-20 sprites at a time, and so we pre-rendered as much as possible as a precaution. As it turns out, we're nowhere near taxing the performance of the processor: our bottleneck for performance is `FastLED::Show`. 

So this year, instead of a pre-rendered pixel trail for the faerie sprites, I added a `DimTrail()` method. 

When I move the `pattern` CRGB sprite one pixel fowards, it doesn't turn off the LED that, in the previous interval, was the rear-most pixel of the `pattern`. So I call `DimTrail()` on that pixel, and it gets faded by ~50% using a FastLED function. The `DimTrail()` method is recursive, so it then steps back one pixel and fades again, and so on, until it detects that it's reached a black pixel, at which point it exits.  

```
	// add int direction and make tailpixel += direction, and when direction is "backwards", offset the dimtrail by 3 pixels to prevent dimming the sprite
	void DimTrail(int tailPixel, int dimFactor, int direction) {
		if (tailPixel < 0) return;
		if (tailPixel > NUM_LEDS) return;
		if (! leds[tailPixel]) return;
		
		leds[tailPixel].fadeToBlackBy(dimFactor);
		tailPixel += direction;
		DimTrail(tailPixel, dimFactor, direction);
	}
```
The FastLED `fadeToBlackBy` function operates in 1/256ths, meaning that if you feed it 128, it fades 50%, if you feed it 64, it fades 25%, and so on. So I also wrote a function that maps `updateInterval` (the variable framerate) to `dimFactor`, so that now when faerie sprites move slowly, they start with a short trail, and when they accelerate to move quickly, they stretch out a long trail behind them. 

That's great, but when the sprites *stop* for their idle animation, the trail fade doesn't look right. 

So I created a `FadeOutTrail()` method, which itself calls `DimTrail()` recursively. 

	void FadeOutTrail(int tailPixel, int dimFactor, int direction) {
		if (tailPixel < 0) return;
		if (tailPixel > NUM_LEDS) return;
		if (! leds[tailPixel]) return;
		
		// Recursively run DimTrail() at tailPixel+1, so trail fades from the dim end
		DimTrail(tailPixel, dimFactor, direction);
		FadeOutTrail(tailPixel + direction, dimFactor, direction);
	}

The result of this method is that, instead of staying the same length and fading out awkwardly, when the sprites stop and idle, the trails shrink from the far end inwards. It's a subtle improvement, but a nice one. 

## Algorithmic braking

Now that I've done some pixel animation of how I want the faerie sprites to move, I've worked out that I like to have them slow down and stop over a range of about 4-8 pixels, with the trails fading as they slow. I'm now working on slowing the sprites down by manipulating the framerate (which is how they accelerate). 

I just put in some movement logic where the sprites calculate their distance from their destination pixel, and when that is within a certain percentage of the overall travel distance, it starts braking. 

However, currently deceleration is handled by a single factor; how many milliseconds do you add or subtract to the `updateInterval` on each call of `updateTravel()`? 

For acceleration from stop, it's simple enough to start at about 40ms, and subtract 1ms per interval as you travel. The result is a reasonably natural enough acceleration towards "cruising speed". 

For making the sprite slow down to a stop, however, that doesn't really result in a pleasing deceleration curve. 

[Algorithmic brake at 15% of total distance travelled][vid2]

[vid2]: https://vimeo.com/271006221

After some work, I came up with this acceleration method: 

    int AccelerateTravel() {
		// Decide whether braking or accelerating
		if (currentDistance < totalTravelDistance * brakePercentage) {
			if (!isBraking) {
				isBraking = true;
				brakeDistance = abs(currentDistance - totalTravelDistance);
				brakePixel = currentPixel;
			}
		} else {
			isBraking = false;
		}
		// Accelerate or brake by returning positive or negative values to subtract from updateInterval
    	if (! isBraking) {
			int x = abs(currentDistance - totalTravelDistance);
    		return round(sqrt(x) * accelerationFactor);
    	} else if (isBraking) {
			int x = abs(currentPixel - brakePixel);
    		return -1 * round(sqrt(x) * brakeFactor);
    	}
    }

Whether braking or accelerating, the change to `updateInterval` is a function of the distance traveled from the point where you started accelerating. `accelerationFactor` and `brakeFactor` are semi-randomized values assigned on sprite creation, whose purpose is to make sure that, even if two sprites start at the same pixel headed in the same direction, they'll have slightly different acceleration and brake speeds, so they'll move a bit differently from each other. I'm still dialing in what those values should be. 

## Algorithmic idle animation

After the faerie sprite in the above video slows to a stop, it idles across 3 pixels, back and forth. I sketched this in terms of pixel values from the `colorPalette` array in my new notebook, and my friend [Scott Longely][sl] translated it into a set of simple algorithms for each pixel. 

[sl]: http://s-a-w-s.blogspot.com

That isn't the full desired result, though. What I need to do next is to write a `colorFade()` function to transition smoothly between pixel values. 

I've found example code as gists on GitHub. Both use FastLED functions for the fade, which have so far resulted in good animation performance, so I'm game to see how they go. 

* [Example One](https://gist.github.com/kriegsman/1f7ccbbfa492a73c015e)
* [Example Two](https://gist.github.com/kriegsman/d0a5ed3c8f38c64adcb4837dafb6e690)

I have so far not looked at the code at all to see how suitible it may be. So that'll happen soon. 

## Transition from idle to travel

There's a visual discontinuity at the moment where the animation transitions from `isIdling` to `false`; at that moment, it chooses a new destination, and draws the `travel` sprite. Unfortunately, the last frame of the idle animation and the travel sprite do not match perfectly. 

So one of my next action items is to fix that. 

## Faeries go both ways

Last year's build of the Witch Lights concealed a dirty secret: sprites only had the capacity to move in one direction. 

Basically, a sprite started at `0`, and when in travel mode, it moved by adding 1 to `CurrentPixel`. When `CurrentPixel` was > `NUM_LEDS`, the sprite was marked done. (Or it started at `NUM_LEDS` and traveled towards `0`.)

What I *want*, though, is for faeries to make one long travel move in the "forwards" direction (whichever way that happens to be for this particular sprite), and then make a bunch of small, random moves in either direction, basically flitting about while waiting for people to catch up along the path. 

So that means that all the movement logic needed to be examined and re-written. Which I will not get into here. But basically, it happened. 

[Faeries traveling in both directions][vid3]

[vid3]: https://vimeo.com/271040882

So that's working, too. 

## Reverse the polarity of the neutron flow

The [Witch Lights][wl] have two long-range motion sensors, one at each end. When someone on the "far" end triggers a sensor, we have to spawn a faerie sprite that starts at `NUM_LEDS` (the far end), and travels towards pixel `0`. 

[wl]: https://witchlights.com/

There are lots of details involved in making sprites travel in the "other" direction; for example, when transitioning from travel mode to idle, the idle pixel animation has to run in reverse. And the logic to check whether the sprite is "done" (and can be deleted from memory) has to know the sprite's direction, and so on. 

Or. 

When we run an `Update()` method, when we take what we've animated and send it to the LEDs, what we actually do is call a function called `stripcpy`. That function takes the CRGB struct that we've been manipulating, looks up `currentPixel`, and then uses `memcpy` to write our pixels to the `leds` CRGB struct. 

OK. So. 

What if we told `stripcpy` to count from the *other* direction, and write the CRGB data *backwards*? 

In theory, you'd get a perfect mirror image of the animation you're running. The sprite logic would always run from pixel `0` to `NUM_LEDS`, but it would draw to the pixels as though it was running in the other direction. 

That simplifies the requirement for direction-checking logic all through the various methods of the sprite class, and only requires that sprites be created with a `drawDirection` value, which then gets passed to all `stripcpy` calls. 

That's the theory. I haven't tried it out yet. But I'm eager to try it. If it works, that's a huge simplification, reducing the number of potential logic bugs in Travel mode. 

It would very slightly complicate collision detection, but I'm pretty sure that's easily solved. 

## Up Next

Here's the todo list:

* Add "flit" behavior, so that faeries make long travel moves towards `NUM_LEDS`, then a number of short, random moves in either direction, with short idles, and then move on with another long travel move

* Make `stripcpy` run backwards

* Add jumper-pin modes (set some pins to auto-pullup, and then jumper them to ground to activate various modes for setup and documentation)

* Collision detection

* Adjust `accelerationFactor` and `brakeFactor` randomization, maybe make them values passed to sprites on creation?

* Create subclasses of the current sprite and change the idle animation

* Fix the visual glitch when transitioning from idle to travel modes (FadeColor?)

* Define zones of pixels where faerie sprites should not stop and idle
	* areas where the trail coils around a tree
	* zones at the very beginning and end of pixel strips

* Use collision detection to make faeries more likely to stop and flit around near other faeries

* Double-check memory usage and possible memory leaks caused by my messing with things I do not sufficiently understand

And other things. Secret things.

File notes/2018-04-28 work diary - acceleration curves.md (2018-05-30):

# Acceleration Curves 

Part 1:

https://vimeo.com/267062321

Part 2: 

https://vimeo.com/267064649

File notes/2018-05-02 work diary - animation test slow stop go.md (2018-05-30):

# Progress: Slow, stop, go

Next up in terms of goals is to see how to make the sprite slow and stop naturally, and then accelerate back up to travel speed. 

[Witch Lights Animation Test 2: Slow, stop, go][video]:

[video]: https://vimeo.com/267676592

I've spend a few iterations tuning this. The deceleration curve is fairly decent, but it doesn't look right when it starts up from a hard stop. I think the sprite should "wind up" before going, so that means backing up a bit. I'll have to play with the timing to make it look right. 

Once I have these dialed in, I can break them up into "intro" and "outro" animations, and create some loop animations to put in between.

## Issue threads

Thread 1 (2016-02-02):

Animation improvements required

jdimauro, 2016-02-02:
Currently, the animation code works like so:

* accelerate from current location to a randomized location
* stop dead and play a "sparkle" animation for a certain number of cycles
* repeat cycle until current location is the end of the LED strip

The desired animation is more complex; the idea is to sell the idea of a light "sprite" jumping from place to place and hovering in between. I envision a successful animation as being something like:

* accelerate from current location to a randomized destination (and store current 'interval' for the next move function to use)
* decelerate from new location to location +15 pixels (and store 'interval')
* reverse direction and accelerate back to location -10 pixels (and store 'interval')
* decelerate from current location to location -10 pixels (and reset 'interval to default)
* display "sparkle" animation
* randomly accelerate from sparkle location to a position ± 10 pixels and "sparkle" again (from 0-5 times?)
* repeat cycle until current location is the end of the LED strip

This will involve a few changes:

1. The current `MoveFromToLocation()` function always accelerates. It needs an argument that takes `+1` or `-1` and uses `+=`on the `interval` variable to accelerate or decelerate as required by the animation code
2. `MoveFromToLocation` needs to store `interval` in a `previousInterval` global variable, and take an argument that tells it to start from that variable, OR to use the globally-set `interval` value (which is used to tune the speed of the sprite)
3. I'm not sure how to make the "sparkle" animation jump from location to location a random number of times

tenner, 2017-07-05:
I think this is done, if not by the letter then by the spirit... anything else to do here?

(If so, I'd recommend marking this closed anyway and putting the proposed enhancements in new issues.)

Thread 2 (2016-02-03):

Resolve memory issues in SpriteManager

tenner, 2016-02-03:
Something's wonky with memory management in my branch. I suspect it has to do with incorrect free()ing of dead sprites. This is very likely due to the fact that I'm entirely incompetent in C++ and rely on garbage collection.

Difficulty: fix this without doing anything funky C++-wise.

tenner, 2016-02-09:
One issue isn't very substantial but is there; the location of "new" and "delete" are separated across a class boundary. It was by design that if the SpriteManager was "full", the Add() method no-op'ed and just did nothing. However, the sprite had already been added via "new" and that heap space was then lost. I believe this was some of the behavior seen on the Duemilanove, as there were only 700 bytes on the heap to work with.

There is at least one more leak, however, so this isn't over yet.

tenner, 2016-02-09:
(Solution, I might add, was to delete the pointer to the sprite if the Add() method no-op'ed. Added that to the reduced code; it will need to be added to the .ino.)

tenner, 2016-02-09:
Never mind, that was the only leak!

Added the code to my copy of the .ino. I'll hook up my Duemilanove later this week to test. In theory, that setup should now run indefinitely.

tenner, 2016-02-10:
Just about ready to call this done.

Got rid of the old array-indexed SpriteManager and replaced it with a VectorSpriteManager using the Arduino StandardCPlusPlus library's vector type. That may or may not have helped.

HOWEVER

The strip ran indefinitely* when using only ForwardScanningSprites. BackwardScanningSprites seem to be incorrectly falling into a state where they're functionally done but not reported to be done.

This means that the freezing I witnessed later actually may not have been a memory related crash -- it's possible that the MAXSPRITES slots for available sprites were all filled with dead BackwardScanningSprites and no more could be created.

So -- next steps are:

- Fix BackwardScanningSprites so they can run indefinitely.
- There is a condition by which the Arduino is gracefully rebooting every couple minutes (identified by the test pattern that propagates). THIS may be as a result of memory issues; it would make sense that if heap space someday hits zero, then the Duemilanove restarts itself. That's actually ok and Josh can probably live with that**.

*ten minutes or so
**If the memory leaks are a result of compiling bugs, then he's gonna have to.

tenner, 2016-04-04:
BackwardScannerSprites are still broken; I'll add that to its own bug and close this one since we've sufficiently deviated from the original purpose of this bug.

Closed 2016-04-04.

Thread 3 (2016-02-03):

SpriteManager does not work on Arduino Due

jdimauro, 2016-02-03:
When I try to run the SpriteManager code on the Arduino Due powering the witch lights, I get no animation. Possible that there's just a missing line in the code (see the top of the `witch-lights-classic.ino` file).

tenner, 2016-04-04:
Resolved at the April 2 hackathon. `SpriteManager` seems to be behaving pretty well on a 750-LED configuration. I still think there are some performance improvements that can be made.

Closed 2016-04-04.

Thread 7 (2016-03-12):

Error in StandardCPlusPlus library when compiling `witch_lights_more_sprites.ino`

jdimauro, 2016-03-12:
When I attempt to compile `witch_lights_more_sprites.ino`, I get the following error:

```

/Users/josh/Documents/Arduino/libraries/StandardCplusplus/ostream_helpers: In static member function 'static void std::__ostream_printout<traits, char, float>::printout(std::basic_ostream<char, traits>&, float)':
/Users/josh/Documents/Arduino/libraries/StandardCplusplus/ostream_helpers:250:109: error: there are no arguments to 'dtostrf' that depend on a template parameter, so a declaration of 'dtostrf' must be available [-fpermissive]
    length = strlen(dtostrf(f, static_cast<int>(stream.width()), static_cast<int>(stream.precision()), buffer));
                                                                                                             ^
/Users/josh/Documents/Arduino/libraries/StandardCplusplus/ostream_helpers:250:109: note: (if you use '-fpermissive', G++ will accept your code, but allowing the use of an undeclared name is deprecated)

```

This is using the Arduino Due as the target board.

I've downloaded the latest versions of the Arduino IDE, and have downloaded a fresh copy of the library. Still no joy.

tenner, 2016-04-04:
Fixed; removed and created a custom `SpriteVector` class.

Closed 2016-04-04.

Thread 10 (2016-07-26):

Feature - SHARP IR sensor support

jdimauro, 2016-07-26:
I plan to install short-range infrared sensors midway through the length of the witch lights, and when triggered, to spawn a pair of sprites near the sensor which head off in opposite directions.

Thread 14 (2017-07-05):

Merge 2017-accel branch into default

tenner, 2017-07-05:
Now that we're no longer under time pressure and can do our git stuff properly, the feature/2017-accel branch should be merged into default, and feature/2017-fastled can be closed.

tenner, 2017-07-22:
Done. Closed and deleted feature/2017-accel and feature/2017-fastled after merging into "master".

Closed 2017-07-22.

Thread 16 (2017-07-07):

Fix bug causing sensor timeout to reset on failed sprite creation

tenner, 2017-07-07:
If a sensor is successfully triggered (past its timeout), a sprite is created and added to the strip. This is normal behavior. If the number of sprites == MAXSPRITES, then the sprite isn't created because it has no place to go. This is also fine.

HOWEVER, if a sprite was created and then ignored because it had no place to go, the sensor timeout will already have been processed. That particular sensor will again be locked out for 10, 30, or 60 seconds even though it did nothing (or at least, had no visual effect).

The act of TRYING to create a sprite and then failing at it should not cause the sensor timer to reset.

Add a bit of code to restore an InputDevice's previous last triggered time on demand. Alternately, don't assume that returning IsActuated() == true should reset the timer. Make a subsequent callback do that once it's confirmed that yes, we have generated a sprite.

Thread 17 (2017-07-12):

Fix sprites that change color mid-scan

tenner, 2017-07-12:
Inexplicably, some sprites are changing color when they transition between "travel" and "scan" modes. (and possibly at other stages). Sprites should remain the same constant color throughout, at least by default.

jdimauro, 2019-10-10:
This was caused by a global that should have been an object variable.

Closed 2019-10-10.

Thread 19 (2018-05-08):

Feature: Travel to point with acceleration factors

jdimauro, 2018-05-08:
When we create a generic metaclass for the customizeable sprites, we plan to have different Update methods, and a decision metric for the Update method to decide which to call.

One of those methods should be a Travel method, which is our term for moving from point to point and leaving a trail behind the sprite.

Right now, in order to specify the travel destination, we call the `SetNextInflection()` method, which changes the target pixel for when the sprite enters travel mode.

I'm thinking we should also specify a couple of other factors.

So, `SetNextInflection()` gives us a target pixel of 149, and we're on pixel 20.

When we created the sprite, we should have specified a few factors:

`DefaultTravelIntervalAccelerationFactor` is the linear term for how much we change the interval while accelerating. `-1` is the current default. So, each interval, we subtract 1 from the `updateInterval` int.

OR we could do dynamic acceleration factors based on how far we have to travel?

`DefaultTravelStartInterval` is the interval we always start with when traveling from pixel a to pixel b from a stop. `40ms` is the current default interval

`DefaultTravelMinimumInterval` basically defines our top speed assuming that V is constant. `0ms` is the current default

`DefaultTravelMaximumInterval` would define the slowest the sprite is allowed to move before stopping.

(This may not be necessary, I'm envisioning an edge case where for some reason the interval gets set to 6 seconds between frames and we can't tell if it crashed or not.)

### Accelerating and Braking

I can envision 2 ways of handling this.

One way, for each move, we specify a travel to one destination pixel with a positive acceleration factor, and when we reach that pixel, we specify a much shorter travel to a much closer pixel, with a more aggressive negative acceleration factor, which would smoothly slow the sprite down for an "ease in".

Another way, we specify that traveling is a two-part process, with acceleration and braking.

So if we want to travel 30 pixels, we'd accelerate for 20 pixels, and brake for 10, or 25 and 5, or whatever ends up looking best according to testing. The braking factor would usually be higher than the acceleration factor.

So we could specify stuff for each sprite to give it a profile for acceleration and braking, like:

`DefaultTravelIntervalBrakeRatio` is an implementation guess, where we say "take the total number of pixels you have to travel, and multiply by this number. The result is the number of pixels back from the destination pixel you have to brake for. So accelerate until that pixel, then when you reach it, start braking." So if `DefaultTravelIntervalBrakeRatio` was `.1` then given a total number of 120 pixels to travel, we'd accelerate for 108 pixels, and brake for 12.

You'd want to round up, so that you always have at least 1 pixel of braking.

Brake factor: do we specify this as a factor in sprite creation? Or do we do something like:

* take current interval and subtract it from `DefaultTravelMaximumInterval`: that's how much braking needs to happen over the brake distance
* divide the result by the number of pixels before the target pixel

(That's a linear brake curve, we might actually want a parabolic curve instead?)

I mean, let's assume there's no dumb assumptions in that pseudo-algorithm, what I mean is, given travel of `n` pixels, we always use `n * DefaultTravelIntervalBrakeRatio` pixels to brake, and always brake down to the same (maximum) interval.

### Talking through the example: linear acceleration factor

So if we are traveling 120 pixels, with a default acceleration factor of -1, default brake ratio of .1, and a `DefaultTravelStartInterval` of 40ms, a `DefaultTravelMinimumInterval` of 5ms, and `DefaultTravelMaximumInterval` of 60ms, then:

* We'd multiply 120 by .1 and get 12
* 120-12 = 108; we would start accelerating towards pixel `currentPixel + 108`
* Using a linear acceleration factor of -1ms, we'd accelerate over 35 intervals, traveling 35 pixels
* Over the remaining 73 pixels, the sprite will travel at a constant maximum velocity
* The brake factor is calculated from the `DefaultTravelMaximumInterval`, current interval, and the calculated brake distance: in this case, we have 12 pixels to go from 5ms to 60ms. A naive implementation would be `(DefaultTravelMaximumInterval - CurrentInterval)/brake pixels`, or `55/12` = 4.58ms. Rounding up to the next highest int, we get 5ms.
* So, over the 12 pixels, at each interval, we'd add 5ms to the current interval, maxing out at 60ms.

For a much shorter move, let's say we want to move 10 pixels.

* multiply 10 by .1, we get 1 (which isn't a great thing)
* we have 9 pixels to accelerate; starting at our default interval of 40ms, at pixel `currentPixel + 9`, `currentInterval` will be 31ms
* the brake factor calculates out at `29/1`, or 29ms in a single step

This is why I think we should be able to specify factors for shorter moves.

### UpdateTravel method

I'm thinking that, when we transition from scanner to travel, we set the `isScanning` bool to `false` and use a `StartTravelWithAcceleration()` method to define the target pixel, the acceleration factor, the brake factor, and I'm thinking we should also be able to specify the `TravelMaximumInterval` to determine what speed we're braking down to? That way we can totally set ourselves up for a seamless transition into a pre-rendered pixel animation.

So if we want to move n pixels in either direction, you'd specify:

* Target distance (negative moves "backwards")
* Acceleration Factor
* Brake Ratio
* Maximum Interval

At a guess, when moving 10 pixels, I would set acceleration to -4, brake ratio to .25 or .33, and maximum interval to maybe 40-50ms? And start tuning from there.

That way, we start at 40ms, and accelerate to 12ms over 7 pixels, then over 3 pixels, the brake factor is `38/3 = 12.66`, rounded to 13, so we'd brake by 13ms each interval to a maximum of 50ms at the target pixel.

### Calculating smooth acceleration over distance?

Do we want to try, instead of using a fixed linear acceleration factor, to calculate that factor based on the distance we're accelerating over?

This could be an optional thing for travel moves?

It'd work like the brake calculation: figure out how many pixels we're accelerating for, then divide the difference between `currentInterval` and `TravelMinimumInterval` over those pixels, and the result is how many ms to accelerate by each interval?

So, for travel moves, you'd say "here's my start speed, here's my maximum speed, here's my minimum speed, here's my brake distance ratio, here's the pixel I'm traveling to" and it would calculate out the acceleration factors for you.

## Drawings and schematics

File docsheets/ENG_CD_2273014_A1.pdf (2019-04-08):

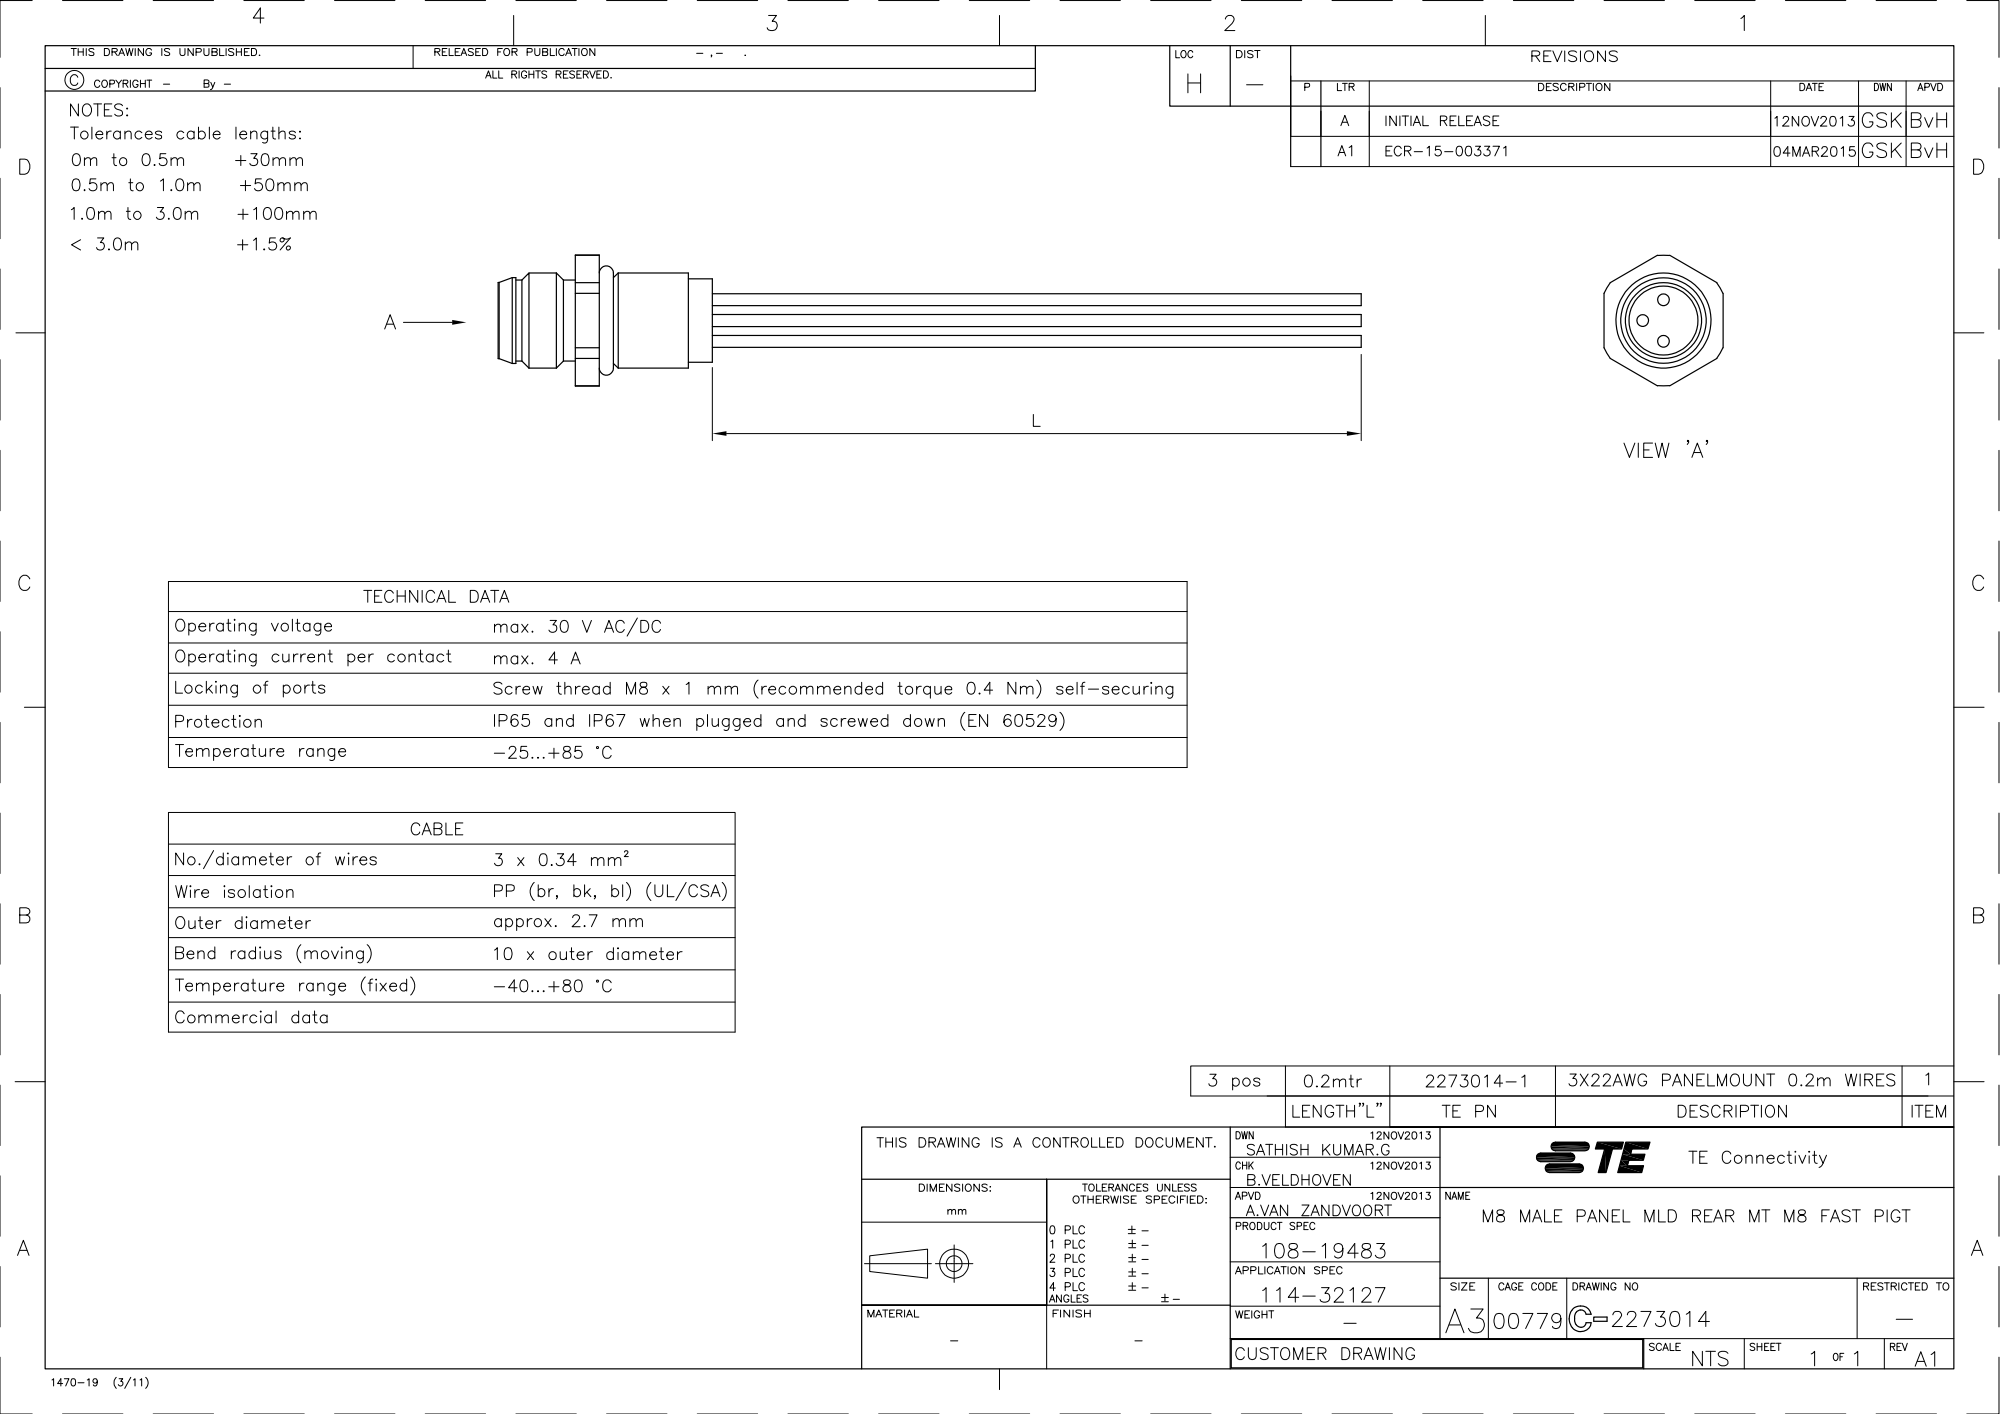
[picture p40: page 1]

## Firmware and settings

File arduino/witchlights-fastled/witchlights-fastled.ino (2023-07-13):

#include <FastLED.h>

#ifndef PSTR
#define PSTR // Make Arduino Due happy
#endif
 
// BEGIN BASIC OTA INCLUDES AND CONFIG

#include <WiFi.h>
#include <ESPmDNS.h>
#include <WiFiUdp.h>
#include <ArduinoOTA.h>
#include "wifiauth.h"
 
// END BASIC OTA INCLUDES AND CONFIG


// TODO: fix the stupid random interval, that worked on an 8-bit arduino, this is an esp32.

// debug or animation modes
// TODO: set this with a jumper to an input pin
bool debugMode = false;					// turns on debug() statements
bool spawnLurkers = false;			// Not ready for Firefly 2018
bool randomInflection = false;	// Randomly makes faerie sprite dance back and forth, instead of mainly going "forwards". 
bool spawnFaeries = true;			// TODO Spawn a new faerie randomly; helpful to keep a constant background of sprite animation for evaluation
bool placeLurkers = false;			// TODO Dimly lights up range of pixels where lurkers are "allowed" to spawn, for install time
bool placeTrees = false;				// TODO Dimly lights up range of pixels green where trees are defined, also for installs
bool placeNoIdle = false;				// TODO same, for specifying zones where faeries will not stop to idle

// FastLED constants
#define NUM_LEDS							300 // 150 per 5-meter strip
#define MAXSPRITES						4

#define NUM_COLORSETS					6  // 6
#define NUM_COLORS_PER_SET		9

// Data pins
#define PIR_SENSOR_1_PIN		 10
#define PIR_SENSOR_2_PIN		 9
#define NEOPIXEL_DATA_PIN		 23								// Pin for neopixels (6 on Due, 23 on wireless stick)

// Sensor time-out (in production, set to 10000)
#define INFRARED_SENSOR_TIMEOUT_IN_MS		8000	// in milliseconds

#define SCANNER_SPRITE_FRAME_DELAY_IN_MS			1
#define TEST_PATTERN_FRAME_DELAY_IN_MS				20

#define FAERIE_MIN_IDLE							1
#define FAERIE_MAX_IDLE							6

#define FAERIE_FLIT_MIN_DISTANCE		5
#define FAERIE_FLIT_MAX_DISTANCE		17

#define FAERIE_FLIT_MIN_START_INTERVAL	20
#define FAERIE_FLIT_MAX_START_INTERVAL	45

#define FAERIE_MIN_SPEED						 8		// sets minInterval range
#define FAERIE_MAX_SPEED 						 20    // the larger this is the slower the maximum speed can be

#define FAERIE_MIN_BRAKE						60		// 96 for 50-60 px // sets maxInterval
#define FAERIE_MAX_BRAKE						96		// orig 112 or 86

#define FAERIE_MIN_WAIT							2
#define FAERIE_MAX_WAIT							6

#define FAERIE_MIN_TRAIL_LENGTH			 60	// The lower the value, the longer the trail generated, but also the more FastLED functions get called per update per sprite. 
#define FAERIE_MAX_TRAIL_LENGTH			 26

// currently set this to be consistent for animation design
#define FAERIE_MIN_LONG_TRAVEL			110	//
#define FAERIE_MAX_LONG_TRAVEL			180	// 

#define SPRITE_STARTING_DELAY_INTERVAL_IN_MS	 36 // 40

const unsigned long SPRITE_AUTOSPAWN_RANDOMNESS_FACTOR = 836999; // 1290000 = lots of downtime


#define NO_IDLE_LOOP_COUNT					7			// number of no-idle zones in the array

// lurker sprite constants

#define BLINK_SPRITE_MIN_LIFETIME		3
#define BLINK_SPRITE_MAX_LIFETIME		12		// # of blinks before dying

#define BLINK_SPRITE_MAX_BLINK_SPEED	5		// ms interval between updates, lower is faster
#define BLINK_SPRITE_MIN_BLINK_SPEED	45

#define BLINK_MIN_COUNT		1
#define BLINK_MAX_COUNT		4

#define LURKER_BLINK_MIN_FREQUENCY	2500
#define LURKER_BLINK_MAX_FREQUENCY	6000

#define LURKER_BLINK_SHUT_MIN_TIMING	50
#define LURKER_BLINK_SHUT_MAX_TIMING	500

#define LURKER_MIN_PIXEL_1	40
#define LURKER_MAX_PIXEL_1	149
#define LURKER_MIN_PIXEL_2	151
#define LURKER_MAX_PIXEL_2	280
#define LURKER_MIN_PIXEL_3	400
#define LURKER_MAX_PIXEL_3	450

// For testing use only. In production, set this equal to 1. Use this to exaggerate the acceleration effects. 10-20 is good for testing.
#define ACCELERATION_DELAY_OBVIOUSNESS_FACTOR				 1

#define ANIMATION_FRAME_WIDTH			1 //23
#define ANIMATION_FRAMES					1 //28




// ...TO HERE.

// Array representing the strip.
CRGB leds[NUM_LEDS];
// -------
// By defining a single element in memory which SHOULD BE immediately before the large pixel array,
// I've effectively created the (-1)th element of the array. This frees me from having to check
// that I'm writing pixels to that area and will unknowingly blow something up, and saves a costly
// comparison (which is false ALMOST always) each time through each Sprite's Update() method.
// TODO: Do this properly with malloc()/calloc().

CRGB colorSets[NUM_COLORSETS][NUM_COLORS_PER_SET];

char afc_w8v1r[ANIMATION_FRAME_WIDTH * ANIMATION_FRAMES];
CRGB af_w8v1r[ANIMATION_FRAME_WIDTH * ANIMATION_FRAMES];


// Function prototypes.
void resetStrip(void);
void debug(int);
void debugNeg(int);
void debugN(int, int);
void stripcpy(CRGB *, CRGB *, int, int, int);
void createColorsets(void);

class InfraredSensor {
private:
		int _pinNumber;
		uint32_t lastPollTime;

public:
		InfraredSensor(int pinNumber) {
				this->_pinNumber = pinNumber;
				this->lastPollTime = millis();

				pinMode(this->_pinNumber, INPUT);
		}

		// Put sensor read code here. Return true if triggered, false otherwise.
		bool IsActuated() {
				if (millis() - this->lastPollTime < INFRARED_SENSOR_TIMEOUT_IN_MS) {
						return false;
				}

				if (digitalRead(this->_pinNumber) == HIGH) {
						// Test pixel to indicate when the sensor's been actuated. Feel free to remove this when you like.
						// leds[29] = CRGB::Red;

						// Make sure these stay at the end of the sensor "if" block. This will set the last polling time to
						// ensure that the sensor is properly "debounced".
						this->lastPollTime = millis();
						return true;
				}

				return false;
		}
};

class Sprite {
	public:
		Sprite() {
			lastUpdateTime = 0;
			done = false;
		}

		virtual ~Sprite() {
		}

		virtual bool Update() = 0;

		bool allowCreation() {
				return true;		// Always true, no reason to veto this one.
		}

		boolean UpdateNow() {
			if (millis() - lastUpdateTime >= updateInterval) {
				lastUpdateTime = millis();
				return true;
			} else {
				return false;
			}
		}

		void MarkDone() {
				this->done = true;
		}

		bool IsDone() {
				return this->done;
		}

	protected:
		uint32_t lastUpdateTime;
		int updateInterval;
		boolean done;
};

class SpriteVector {
	private:
		Sprite **sprites;
		int maxCapacity;
		int count;
		
	public:
		SpriteVector(int maxCap) {
			this->count = 0;
			this->maxCapacity = maxCap;
			sprites = new Sprite*[maxCap];

			for (int i = 0; i < maxCap; i++) {
				sprites[i] = NULL;
			}
		}

		~SpriteVector() {
		}

		Sprite *Get(int i) {
			if (i < this->count) {
				return sprites[i];
			} else {
				return NULL;
			}
		}

		boolean Add(Sprite *sprite) {
			if (count >= this->maxCapacity) {
				return false;
			}

			sprites[count] = sprite;
			++count;

			return true;
		}

		int Count() {
			return this->count;
		}

		boolean RemoveAt(int i) {
			Sprite *ptr = sprites[i];
			sprites[i] = NULL;
			delete ptr;

			for (int j = i + 1; j < count; j++) {
					sprites[j - 1] = sprites[j];
			}
			sprites[count - 1] = NULL;

			--this->count;

			return true;
		}
};

// TODO: State machine blink sprites that spawn in defined areas when TravelSprites pass through them. "Spirits awaken" 

// What I'm going for here: I want to put these in shadowed places, where our primate brain will be looking for glowing eyes in the night. I want them to awaken, and blink, and maybe shift a little, and blink. 
class LurkerSprite : public Sprite {
private:
	int updateInterval;
	int currentPixel;
	int lifetimeBlinks; // # of eyeblinks before sprite vanishes
	int blinkCount;
	int blinkFrequency;
	int eyeWidth; // spacing between eyes, minimum is 1, set this higher the further away you are locating the sprite from the viewer
	int blinkDirection; // if in blink mode, are we closing or opening? -1 for closing, +1 for opening, 0 for staring
	int eyeColor;			// entry in color array
	int eyeMaxColor;		// how bright should we go?
	int blinkMaxCount;		// how many blinks in a "set" of blinks?
	int blinkTiming;		// how many ms between each blink in a "set"? 
	unsigned long lastBlinkTime;	// time when we last blinked
	int colorPalette;

	// We're defining a set of either 2, 4, or 6 pixels, depending on how far apart you want the eyes to be
	// ...so, should this be set to eyewidth + 1?
	CRGB eyes[2];
	int eyeLength = 2;
	
	int SetLifeSpan() {
		// debug(2);
		return random(BLINK_SPRITE_MIN_LIFETIME, BLINK_SPRITE_MAX_LIFETIME + 1);
	}
	
	int SetInitialBlinkSpeed() {
		// debug(3);
		return random(BLINK_SPRITE_MAX_BLINK_SPEED, BLINK_SPRITE_MIN_BLINK_SPEED + 1);
	}
	
	// TODO: make eye dimness slightly variable on spawn
	int SetMaxEyeColor() {
		// random 3-5
		return random(4,5 +1);
	}
	
	int SetBlinkMaxCount() {
		// debug(4);
		return random(BLINK_MIN_COUNT,BLINK_MAX_COUNT + 1);

	}
	
	int SetBlinkTiming() {
		// debug(5);
		return random(LURKER_BLINK_SHUT_MIN_TIMING,LURKER_BLINK_SHUT_MAX_TIMING + 1); // ms; testing to see what looks good, these are rough guesses
	}
	

	
	int SetBlinkFrequency() {
		return random(LURKER_BLINK_MIN_FREQUENCY, LURKER_BLINK_MAX_FREQUENCY +1);
	}
	
	void SpawnBlinkChild() {
		// debug(6);
		// random chance to spawn a new blink sprite with a reduced lifespan
	}
	
	// TODO: blink in multiple sets
	int Blink() {
		if (blinkDirection == 0) {
			if (eyeColor == eyeMaxColor) {
				// we are staring.
				// check to see if we need to blink
				if (millis() - lastBlinkTime >= blinkFrequency) {
					lastBlinkTime = millis();
					blinkFrequency = SetBlinkFrequency(); // reset blinkFrequency after every blink?
					return -1;
					// make this a random chance that gets more likely over time, based on blinkFrequency?
				} else {
					return 0;
				}
			} else if (eyeColor == 0) {
				// we are mid-blink
				// check to see if our lifespan is up, and if so, mark done and exit
				if (blinkCount >= lifetimeBlinks) {
					this->MarkDone();
					SpawnBlinkChild();
					return 0;
				}
				// check to see if it's time to open our eyes
				if (millis() - lastBlinkTime >= blinkTiming) {
					// eyes have been closed long enough
					return 1;
				} else {
					// eyes are staying closed a little longer
					return 0;
				}
			}
		}

		if (blinkDirection == -1) {
			// have we reached the end of the blink?
			if (eyeColor <= 0) {
				// if eyeColor went negative, fix that
				eyeColor = 0;
				return 0;
			} else {
				// if not, keep blinking
				return -1;
			}
		}
		
		if (blinkDirection == 1) {
			if (eyeColor >= eyeMaxColor) {
				// we have just completed a single blink
				// add a blink to our lifetime count
				blinkCount ++;
				// and record the time as the end of the last blink
				lastBlinkTime = millis();
				// and stop blinking
				return 0;
			} else {
				return 1;
			}
		} else {
			debug(7);
			return 0; // if blinkDirection's value gets messed up somehow and is not -1, 0, or 1, just set it to 0 for now. 
		}
	}
	
public:
	LurkerSprite(int spawnPixel, int eyew) : Sprite() {
	// Initial state.
	this->currentPixel = spawnPixel;
	this->updateInterval = SetInitialBlinkSpeed();
	this->lifetimeBlinks = SetLifeSpan(); 
	this->blinkCount = -1;							// When first opening the eyes, it "counts" as a blink, and setting to -1 means we don't count it against lifespan
	this->blinkFrequency = SetBlinkFrequency();		// decent test with 4000 ms, trying a random set
	this->eyeWidth = eyew;							// can we set this on spawn? Make it semi-random within params? 
	this->blinkDirection = 1;						// want to start with eyes closed and open them
	this->eyeColor = 0;								// eyes closed = 0
	this->eyeMaxColor = SetMaxEyeColor();			// up to 5 in the color set
	this->blinkMaxCount = SetBlinkMaxCount();
	this->blinkTiming = SetBlinkTiming();
	this->lastBlinkTime = millis();
	
	// this->colorPalette = random(0, NUM_COLORSETS);
	this->colorPalette = 2;								// yellow to start


	this->eyes[0] = colorSets[colorPalette][eyeColor];
	this->eyes[eyeWidth] = colorSets[colorPalette][eyeColor];
	this->eyeLength = 2;
	}

	~LurkerSprite() {
	}

	bool allowCreation() {
	return (currentPixel >= LURKER_MIN_PIXEL_1 && currentPixel <= LURKER_MAX_PIXEL_1) || (currentPixel >= LURKER_MIN_PIXEL_2 && currentPixel <= LURKER_MAX_PIXEL_2) || (currentPixel >= LURKER_MIN_PIXEL_3 && currentPixel <= LURKER_MAX_PIXEL_3);
	}

	boolean UpdateNow() {
		if (millis() - lastUpdateTime >= ACCELERATION_DELAY_OBVIOUSNESS_FACTOR * updateInterval) {
			lastUpdateTime = millis();
			return true;
		} else {
			return false;
		}
	}

	bool Update() {
		// debug(eyeColor);
		if (! this->UpdateNow()) {
				return false;
		}
	
		if (! this->allowCreation()) {
			this->MarkDone();
			return false;
		}
	
		// Decide if we're going to blink, and set the value to do it
		blinkDirection = Blink();
	
		// close or open the eyes a step by adding blinkDirection to eye color
		eyeColor += blinkDirection;
	
		this->eyes[0] = colorSets[colorPalette][eyeColor]; // colorSets[2][eyeColor];
		this->eyes[eyeWidth] = colorSets[colorPalette][eyeColor]; // colorSets[2][eyeColor]; 
	
		stripcpy(leds, eyes, currentPixel, eyeLength, eyeLength);
		return true;
	}
};
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
void loop() {

	// BEGIN OTA LOOP

  ArduinoOTA.handle();

	// END OTA LOOP

		if (! isBooted) {
				if (! testSpritesCreated) {
						spriteManager->Add(new W1V1Sprite(10, 0x750787));
						spriteManager->Add(new W1V1Sprite( 8, 0x004dff));
						spriteManager->Add(new W1V1Sprite( 6, 0x008026));
						spriteManager->Add(new W1V1Sprite( 4, 0xffed00));
						spriteManager->Add(new W1V1Sprite( 2, 0xff8c00));
						spriteManager->Add(new W1V1Sprite( 0, 0xe40303));

						testSpritesCreated = true;
				}

				spriteManager->Update();

				if (spriteManager->SpriteCount() == 0) {
					isBooted = true;
				}

				return;
		}

		// Spawn lurkers randomly
		/*if (random(0,1000) == 0 && spawnLurkers) {
			// debug(3);
			int lurkerSpawnPixel = random(40,225); // TODO - create array of lurker zones to use instead of the constants?
			Sprite *s1 = new LurkerSprite(lurkerSpawnPixel,1); 
			// TODO: check to see if another lurker already exists at this pixel, despawn if so
		
			if (! spriteManager->Add(s1)) {
				delete s1;
			} 
		} else {
			// debug(1);
		} */
		
		// 3200000 = perfect for esp32 in production
		// 1960000 = almost twice as frequent for animation analysis?
		// SPRITE_AUTOSPAWN_RANDOMNESS_FACTOR
		if (random(0,SPRITE_AUTOSPAWN_RANDOMNESS_FACTOR) == 0UL && spawnFaeries) {

			for (int i = 0; i <= random(MAXSPRITES) + 1; i++) {
				Sprite *s1 = new FaerieSprite(1, -3); 
			
				if (! spriteManager->Add(s1)) {
					delete s1;
				}
			}
			
		} else if (random(0,SPRITE_AUTOSPAWN_RANDOMNESS_FACTOR) == 0UL && spawnFaeries) {
			for (int i = 0; i <= random(MAXSPRITES) + 1; i++) {
				Sprite *s2 = new FaerieSprite(-1, NUM_LEDS + 3); 
			
				if (! spriteManager->Add(s2)) {
					delete s2;
				}
				// debug(1);
			}
		}

		/*
		PHASE Lights aren't running sensors for FF2023

		if (sensor1->IsActuated()) {
			Sprite *s1 = new FaerieSprite(1, -3); // production

			if (! spriteManager->Add(s1)) {
					delete s1;
			}
		}

		if (sensor2->IsActuated()) {
			Sprite *s2 = new FaerieSprite(-1, NUM_LEDS + 3);
			
			if (! spriteManager->Add(s2)) {
				delete s2;
			}
		}
		*/

		spriteManager->Update();
		

		// Try to reconnect once every 5 seconds

	if(WiFi.status()  != WL_CONNECTED && millis() - reconnectTime > 5000) {
	   reconnectTime = millis();

	   WiFi.begin(ssid, password);
	}
}


/* ---Utility functions --- */

void resetStrip() {
		FastLED.addLeds<NEOPIXEL, NEOPIXEL_DATA_PIN>(leds, NUM_LEDS);

		for (int i = 0; i < NUM_LEDS; i++) {
			leds[i] = CRGB::Black;
		}

		FastLED.show();
}

void debug(int number) {
	if (!debugMode) return;
		fill_solid(leds, NUM_LEDS, CRGB::Black);
		fill_solid(leds, number < NUM_LEDS ? number : NUM_LEDS, 0x202020);
		FastLED.show();
}

void debugNeg(int number) {
	if (!debugMode) return;
		fill_solid(leds + NUM_LEDS - number, number < NUM_LEDS ? number : NUM_LEDS, 0x202020);
}

void debugN(int startPos, int number) {
	if (!debugMode) return;
		fill_solid(leds + startPos, number < (NUM_LEDS - startPos) ? number : NUM_LEDS - startPos, 0x202020);
}

// TODO: faeries go both ways
void stripcpy(CRGB *leds, CRGB *source, int start, int width, int patternSize) {
		// We would be writing off the end anyway, so just bail. Nothing to do.
		if (start >= NUM_LEDS) {
				return;
		}

		// The position on the strip where the pattern will begin.
		int actualStartPosition = start >= 0 ? start : 0;

		int startPlusWidth = start + width;

		// The position on the strip AFTER the last pixel drawn.
		int actualEndPosition = startPlusWidth <= NUM_LEDS ? startPlusWidth : NUM_LEDS;

		// How many bytes into the source do we start copying?
		int patternStart = start >= 0 ? 0 : -start;

		// This may be negative, which indicates we'd finish writing before we get to the start.
		int actualBytes = actualEndPosition - actualStartPosition;

		if (actualBytes > 0) {
				memcpy(leds + actualStartPosition, (patternStart <= patternSize) ? source + patternStart : source, actualBytes * sizeof(CRGB));
		}
}

void createColorsets() {
// Blue 2.0
		colorSets[0][0] = 0x000000;
		colorSets[0][1] = 0x000000;
		colorSets[0][2] = 0x000000;
		colorSets[0][3] = 0x000101;
		colorSets[0][4] = 0x000203;
		colorSets[0][5] = 0x010507; // 02070A
		colorSets[0][6] = 0x030A0F;
		colorSets[0][7] = 0x06151E;
		colorSets[0][8] = 0x0C2A3C;

// Blue 2.5
#if NUM_COLORSETS > 1
		colorSets[1][0] = 0x000000;
		colorSets[1][1] = 0x000000;
		colorSets[1][2] = 0x000000;
		colorSets[1][3] = 0x000001;
		colorSets[1][4] = 0x000003;
		colorSets[1][5] = 0x010106; // 02070A
		colorSets[1][6] = 0x02020C;
		colorSets[1][7] = 0x050519;
		colorSets[1][8] = 0x0A0A33;

#endif

// Yellow-green.
#if NUM_COLORSETS > 2
		colorSets[2][0] = 0x000000;
		colorSets[2][1] = 0x000000;
		colorSets[2][2] = 0x000100;
		colorSets[2][3] = 0x010200;
		colorSets[2][4] = 0x030500;
		colorSets[2][5] = 0x060A01;
		colorSets[2][6] = 0x0D1503;
		colorSets[2][7] = 0x1B2A06;
		colorSets[2][8] = 0x36540C;
#endif

#if NUM_COLORSETS > 3
// Amber.
		colorSets[3][0] = 0x000000;
		colorSets[3][1] = 0x000000;
		colorSets[3][2] = 0x000000;
		colorSets[3][3] = 0x010100;
		colorSets[3][4] = 0x030300;
		colorSets[3][5] = 0x060601;
		colorSets[3][6] = 0x0C0C02;
		colorSets[3][7] = 0x191905;
		colorSets[3][8] = 0x33330A;
#endif

#if NUM_COLORSETS > 4
// Reddish-purple.
		colorSets[4][0] = 0x000000;
		colorSets[4][1] = 0x000000;
		colorSets[4][2] = 0x010001;
		colorSets[4][3] = 0x030102;
		colorSets[4][4] = 0x060204;
		colorSets[4][5] = 0x0C0508;
		colorSets[4][6] = 0x180A11;
		colorSets[4][7] = 0x311523;
		colorSets[4][8] = 0x632A47;
#endif

#if NUM_COLORSETS > 5
// Original purple.
		colorSets[5][0] = 0x000000;
		colorSets[5][1] = 0x000000;
		colorSets[5][2] = 0x010001;
		colorSets[5][3] = 0x030102;
		colorSets[5][4] = 0x060305;
		colorSets[5][5] = 0x0C060A;
		colorSets[5][6] = 0x180C14;
		colorSets[5][7] = 0x311828;
		colorSets[5][8] = 0x633051;
#endif
}

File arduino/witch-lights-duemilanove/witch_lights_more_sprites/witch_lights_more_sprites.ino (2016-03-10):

#include "StandardCplusplus.h"
#include "vector"

using namespace std;

#ifndef PSTR
 #define PSTR // Make Arduino Due happy
#endif

#include <MemoryFree.h>

#include <Adafruit_NeoPixel.h>

// JOSH: FEEL FREE TO EDIT CONSTANT VALUES HERE...

// Hardware configuration.
#define NEOPIXEL_DATA_PIN    6                // Pin for neopixels
#define PIR_SENSOR_1_PIN     3
#define PIR_SENSOR_2_PIN     4
#define PUSHBUTTON_PIN       2

#define N_LEDS              30               // 30/meter test reel    

// Sensor timeouts.
#define INFRARED_SENSOR_TIMEOUT_IN_MS  2000
#define PUSHBUTTON_TIMEOUT_IN_MS  1000

// The maximum number of sprites run simultaneously.
#define MAXSPRITES           3

// "Framerate" minimum and maximum period for animations.
#define MIN_UPDATE_INTERVAL_IN_MS  15
#define MAX_UPDATE_INTERVAL_IN_MS  40

// ScannerSprite parameters.
#define MIN_PIVOT_COUNT 2                    // Josh: reset to 5
#define MAX_PIVOT_COUNT 10                    // Josh: reset to 40
#define MIN_LEAP_DISTANCE_BETWEEN_PIVOTS 5   // Josh: reset to 20
#define MAX_LEAP_DISTANCE_BETWEEN_PIVOTS 15   // Josh: reset to 80
#define SCANNER_WIDTH  9        // Must be an odd number.
#define MIN_SCANNER_WIDTH  7    // Must be an odd number.
#define MAX_SCANNER_WIDTH  13   // Must be an odd number.

// ...TO HERE.

#define DARK    0x000000
#define WHITE   0xffffff

Adafruit_NeoPixel strip = Adafruit_NeoPixel(N_LEDS, NEOPIXEL_DATA_PIN, NEO_GRB + NEO_KHZ800);

class IDSequence {
public:
    IDSequence() {
        this->nextValue = 1;
    }
    
    int GetNextValue() {
        return this->nextValue;
    }
    
private:
    int nextValue;
};

class InputDevice {
public:
    virtual bool IsActuated() = 0;

public:
    uint32_t lastPollTime;
    
protected:
    int _pinNumber;
};

IDSequence sequence;

class InfraredSensor : public InputDevice {
public:
    bool IsActuated() {
        // Put sensor read code here. Return true if triggered, false otherwise.
        if (millis() - this->lastPollTime < INFRARED_SENSOR_TIMEOUT_IN_MS) {
            return false;
        }

        if (digitalRead(this->_pinNumber) == HIGH) {
            this->lastPollTime = millis();
            return true;
        }        

        return false;
    }
};

class Pushbutton : public InputDevice {
public:
    Pushbutton(int pinNumber) {
        this->_pinNumber = pinNumber;
        
        pinMode(this->_pinNumber, INPUT);     // declare sensor as input
    }

    bool IsActuated() {
        if (millis() - this->lastPollTime < PUSHBUTTON_TIMEOUT_IN_MS) {
            return false;
        }
    
        if (digitalRead(this->_pinNumber) == HIGH) {
            this->lastPollTime = millis(); 
            return true;
        }

        return false;    
    }
};

class Sprite {
public:
    Sprite() {
        this->id = sequence.GetNextValue();
        MarkUpdated();
        done = false;
        SetNextUpdateTime();
    }
    
    virtual void Update() = 0;

    boolean UpdateNow() {
        return (millis() - lastUpdateTime >= GetNextUpdateTime());
    }
    
    void MarkUpdated() {
        lastUpdateTime = millis();
        SetNextUpdateTime();
    }

    virtual uint32_t GetNextUpdateTime() {
        return nextUpdateTime;
    }

    virtual void SetNextUpdateTime() {
        nextUpdateTime = random(MIN_UPDATE_INTERVAL_IN_MS, MAX_UPDATE_INTERVAL_IN_MS);  
    }
    
    boolean IsDone() {
        return done;
    }
    
    void MarkDone() {
        done = true; 
    }
    
    int getID() {
        return sequence.GetNextValue(); 
    }
    
protected:
    uint32_t lastUpdateTime;
    boolean done;
    uint16_t id;
    uint32_t nextUpdateTime;
};

class ScannerSprite : public Sprite {
protected:
    uint32_t pixelColor;
    int currentPixel;
    int targetPivot;
    int pivotCount;
    bool pivoting;
    int generatedPivotTotal = MIN_PIVOT_COUNT;
    int scannerWidth;

    // The number of the pixel for the purposes of the scanner. A PIVOT_WIDTH wide scanner
    // should cause this number to range from 0 to (PIVOT_WIDTH - 1) * 2 - 1.
    int pivotPixel;
    int pivotPixelMax;

    int getScannerPixelPositionRelative(int _pivotWidth, int _pivotPixel) {
        // Here, _pivotPixel is the "frame" of the animation, starting at 0.
        // A scanner width of 9 would allow the result of this function to vary
        // from +4 to -4 (nine possible values). There would be sixteen possible
        // steps in this animation before returning to the beginning of the 
        // animation.
        // 
        // Or, in general, a scanner width of n (must be an odd number) would allow
        // the result of this function to vary from -((n - 1) / 2) to +((n - 1) / 2), 
        // that is to say, n possible values. There would be 2*(n - 1) possible steps
        // in this animation before returning to the beginning. 
      
        // Examples:
        //    targetPivot (T) = 15, pivotWidth (=) = 9, pivotPixel (*) = 1
        //         ..........====T*===........... returns 1
        
        //    targetPivot (T) = 15, pivotWidth (=) = 9, pivotPixel (*) = 4
        //         ..........====T===*........... returns 4
    
        //    targetPivot (T) = 15, pivotWidth (=) = 9, pivotPixel (*) = 5
        //         ..........====T==*=........... returns 3
    
        //    targetPivot (T) = 15, pivotWidth (=) = 9, pivotPixel (*) = 11
        //         ..........=*==T====........... returns -3
    
        //    targetPivot (T) = 15, pivotWidth (=) = 9, pivotPixel (*) = 12
        //         ..........*===T====........... returns -4
    
        //    targetPivot (T) = 15, pivotWidth (=) = 9, pivotPixel (*) = 16
        //         ..........====*====........... returns 0
        //
        //      -------> direction of sprite motion ------->

        int p = _pivotPixel % (2 * (_pivotWidth - 1));
        int maxDeviationFromCenter = (_pivotWidth - 1) / 2;
        
        if (p <= maxDeviationFromCenter) {
            return p;
        } else if (p > maxDeviationFromCenter && p <= 3 * maxDeviationFromCenter) {
            return (_pivotWidth - 1) - p;
        } else {
            return -(2 * (_pivotWidth - 1)) + p; 
       }
    }
};

class ForwardScannerSprite : public ScannerSprite {
private:
    int GetNextPivotPosition(int currentPivot) {
        return currentPivot + random(MIN_LEAP_DISTANCE_BETWEEN_PIVOTS, MAX_LEAP_DISTANCE_BETWEEN_PIVOTS) + 3;
    }
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

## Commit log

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2016-02-03 documentation and STL files
    [wl-enclosure-nopir.STL, wl-enclosure-pir.STL, wl-enclsoure-lid-0-hole.STL]
2016-02-03 Added lid files and fixed a typo
    [wl-enclosure-lid-0-hole.STL, wl-enclosure-lid-1-hole.STL, wl-enclosure-lid-2-hole.STL]
2016-02-03 added terminus
    [wl-enclosure-terminus.STL]
2016-02-04 Fixed unsigned/signed mismatch
    uint16_t vs int was causing compiler errors
    [witch-lights-classic.ino]
2016-02-04 experimented with some new animation code
    fail fail fail
    [witch-lights-classic.ino]
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2016-02-05 Added circuit board mount for Arduino Due
    [wl-arduino-mount.STL]
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2016-02-12 printer friendly file names for .STL files
    [wl-lid-0-hole.STL, wl-lid-1-hole.STL, wl-lid-2-hole.STL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]
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2016-02-24 Refactored Forward- and BackwardScannerSprites to prevent dead sprites to pile up and lock up the strip.
    Reinstituted trails but they're still partially broken.
    [witch_lights_more_sprites.ino]
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2016-04-02 Refactored "other" sprites into their own file. Fixed bug causing updates to be really sloooooooow.
    [witch_lights_more_sprites.ino]
2016-07-06 Removed holes for M3 screws
    Lids and enclosures snap together, so the M3 screw holes are just a way
    for water to leak into the housing
    [wl-lid-0-hole.STL, wl-lid-1-hole.STL, wl-lid-2-hole.STL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]
2016-07-17 Added un-tested gerber files for interface board for Arduino Mega
    [Witch Lights Arduino Interface Board_contour.gm1, Witch Lights Arduino Interface Board_copperBottom.gbl, Witch Lights Arduino Interface Board_copperTop.gtl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]
2016-07-17 Added un-tested gerber files for terminal boards
    [witchlight proto board 3_contour.gm1, witchlight proto board 3_copperBottom.gbl, witchlight proto board 3_copperTop.gtl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]
2016-07-17 Added 5-pin and 10-pin variants to arduino interface board
    [Witch Lights Arduino Interface Board 5-terminal_contour.gm1, Witch Lights Arduino Interface Board 5-terminal_copperBottom.gbl, Witch Lights Arduino Interface B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]
2016-07-18 Added 3D-printed mount for a 5-pin circuit board (machined by Othermill)
    [wl-pcb-mount-5-pin.STL]
2016-07-18 renamed 10-pin PCB mount to be in line with naming convention
    [wl-pcb-mount-10-pin.STL]
2016-07-21 Split terminal board PCBs into 3-terminal and 5-terminal versions
    [witchlight proto board 3_contour.gm1, witchlight proto board 3_copperBottom.gbl, witchlight proto board 3_copperTop.gtl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]
2016-07-21 Increased clearance between Arduino and top of housing for 5-terminal board
    [wl-pcb-mount-5-pin.STL]
2016-07-21 Added 3D-printed housing for the SHARP GP2Y0A02YK IR distance sensor
    [wl-sharp.STL]
2016-07-21 Added circuit board for 3-way fork connector
    [witchlight proto board fork_contour.gm1, witchlight proto board fork_copperBottom.gbl, witchlight proto board fork_copperTop.gtl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]
2016-07-21 Added STLs for 3-way fork pieces
    [wl-fork-lid.STL, wl-fork.STL]
2016-07-21 minor changes to 5-terminal board
    [Witch Lights Arduino Interface Board 5-terminal_contour.gm1, Witch Lights Arduino Interface Board 5-terminal_copperBottom.gbl, Witch Lights Arduino Interface B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]
2016-07-21 minor changes to lid files
    [wl-lid-1-hole.STL, wl-lid-2-hole.STL]
2016-07-25 added housing for SHARP sensor at end of chain
    [wl-sharp-terminus.STL]
2016-07-25 renamed PIR terminus to differentiate from SHARP IR sensor
    [wl-pir-terminus.STL]
2016-07-26 Added 3-sided connectors for forking off lengths of conduit terminated by SHARP IR sensors
    [wl-3-sided-lid-0-hole.STL, wl-3-sided-lid-2-hole.STL, wl-3-sided.STL]
2016-07-26 removed redundant 3-sided STLs
    [wl-fork-lid.STL, wl-fork.STL]
2016-07-27 prototype clip to hold battery pack in the waterproof enclosure
    [wl-battery-clip.STL]
2016-07-29 Updated gerber files with better features for terminals and OtherMill fabrication
    [Witch Lights Arduino Interface Board 5-terminal_contour.gm1, Witch Lights Arduino Interface Board 5-terminal_copperBottom.gbl, Witch Lights Arduino Interface B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]
2016-07-30 Modified 10-pin mount to fit second strand housing
    [wl-pcb-mount-10-pin.STL]
2016-08-08 Improved battery clip based on physical testing
    [wl-battery-clip.STL]
2016-08-08 Improved Arduino Mega mount for USB clearance in housing
    [wl-pcb-mount-5-pin.STL]
2017-04-13 Added redesigned terminus housing for SeeedStudio PIR sensor
    [wl-seeedpir-terminus.STL]
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2017-06-28 Made minimum sprite jump longer to avoid sprites tripping over themselves trying to get out of scan mode.
    Added 30 ms delay between frames to make animation visible for 50 LED
    strand.
2017-06-29 Changed sensor2 to add a ReverseScannerSprite.
2017-06-29 Added scanner sprites with debris (forward and reverse). Added framework for garbage collection.
2017-07-01 Fixed issues relating to sensors.
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2017-07-01 Naive attempt to fix fairy poop
    Added a second black pixel to try and nail the straggling LEDs when
    coming out of scan mode
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2017-07-21 Fixed instructions for 3D printing the terminus
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2017-10-12 Unfinished board design for arduino due interface board
    [Arduino Due Interface Board 10-terminal.fzz]
2018-04-23 Added animation excel sheets
    Created and modified animation sheets
    [1-classic-scanner.xlsx, 2-matrix-sparkle.xlsx]
2018-04-24 Animation drafts
    [2-matrix-sparkle-a.xlsx, 2-matrix-sparkle-b.xlsx, 2-matrix-sparkle-intro.xlsx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]
2018-04-24 new animation code
    [3-pulse-1.csv]
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2018-04-25 Adjusted skid-and-reverse animation
    [fragment-skid-and-reverse.xlsx]
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2018-04-27 I am bad at pixels
    [fragment-accelerate-and-fade-out-1.xlsx, fragment-accelerate-and-fade-out.xlsx, fragment-accelerate.xlsx]
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2018-04-29 final pre-test-rig animation sketches
    [2-sparkle-a.csv, 2-sparkle-a.xlsx, 4-pulsar.xlsx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]
2018-04-29 more final animation final stuff. final.
    [fragment-skid-and-reverse-b.xlsx, timing-test.csv, zoomie-intro.csv]
2018-04-29 Built test rig, added new animation strcat's for use in test classes
    [2-sparkle-a.csv, 2-sparkle-a.xlsx, fragment-skid-and-reverse-a.xlsx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]
2018-04-30 made powershell script return frame width and length
    [fragment-a-accelerate-and-stretch.xlsx]
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2018-05-01 fixed - vs _ naming for C++
    [3-pulse-arduino.ino]
2018-05-01 Debugging why the arduino crashes during setup()
    [witchlights-fastled.ino]
2018-05-01 debugging.
    Commented out all my changes, and the sketch uploads and runs on the
    Due, so clearly I know where the bug is. Now, have uncommented only the
    timing test constants and the char/CRGB declarations for one animation
    as a test.
    [witchlights-fastled.ino]
2018-05-02 CRGB and char arrays causing problems?
    Interesting.
    [witchlights-fastled.ino]
2018-05-02 fixed frame width for the animation timing test sprite
    [witchlights-fastled.ino]
2018-05-02 Starting with a pair of animation fragments to figure out the relative timing curves when doing pixel art
    [f_skid_stop.xlsx, f_slow_stop.csv, f_slow_stop.xlsx]
2018-05-03 Dialing in on figuring out how to make slow animation movement look right
    [f_slow_stop-test1.csv, f_slow_stop.csv, f_slow_stop.xlsx]
2018-05-03 slowing down the decelerate portion
    [f_slow_stop.xlsx]
2018-05-03 minor adjustments to slow stop
    [f_slow_stop.xlsx]
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2018-05-04 Added l_pulsar_a and f_slow_stop_c to animations, confirmed that the arduino will take the upload without crashing.
    [witchlights-fastled.ino]
2018-05-04 Welp. I done broke it. It compiles and uploads but doesn't spawn the test sprite.
    [witchlights-fastled.ino]
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2018-05-08 Bugs squashed. Sprite animates.
    [witchlights-fastled.ino]
2018-05-08 simple fader test loop sprite
    [l_fader_a.xlsx]
2018-05-08 experimenting with variations on fader
    [l_fader_b.xlsx]
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2018-05-08 dumbest simplest possible edit to pulsar animation
    [l_pulsar_b.csv, l_pulsar_b.xlsx]
2018-05-10 first pixel sketch of traveling eye sprite animation
    [f_eye_sprite_a.xlsx, f_eye_sprite_ease_in_a.xlsx, f_eye_sprite_ease_out_a.xlsx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]
2018-05-11 LurkerSprite not QUITE working, but I know where to start.
    The problem is with eyecolor; I’m trying to pull from the colorpalette
    array, but for some reason, no color gets set when I call it.
    [witchlights-fastled.ino]
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2018-05-22 fixed. TODO: make braking work. currently not braking.
    [witchlights-fastled.ino]
2018-05-22 this is a mistake, but a mistake that doesn't break the build.
    [witchlights-fastled.ino]
2018-05-23 Acceleration and brake factors are random. Attempted random idle movement; doesn't look good.
    [witchlights-fastled.ino]
2018-05-25 Now each sprite has a slightly different length trail, ranging from quite long to quite short
    [witchlights-fastled.ino]
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2018-05-26 Welp. I broke it and I'm going to bed.
    [witchlights-fastled.ino]
2018-05-26 unbroke it, implemented first rough "no idle zone" avoidance
    [witchlights-fastled.ino]
2018-05-27 adjustments to brake and acceleration factors for short vs long movements
    [witchlights-fastled.ino]
2018-06-01 bug found, trails stay lit when sprites go off the end.
    [witchlights-fastled.ino]
2018-06-01 more debugging of crashing build
    [witchlights-fastled.ino]
2018-06-02 Found the cause of the crash. Accessing minNoIdle[i], even with debug(), causes a freeze. No idea why so far.
    [witchlights-fastled.ino]
2018-06-02 Found reason for crash on boot
    using a global int variable as a comparison in the CoerceTargetPixel()
    method loop caused a crash; using a global constant does not cause the
    crash.
    [witchlights-fastled.ino]
2018-06-02 cleanup; noidle doesn't WORK right now, but it doesn't crash.
    [witchlights-fastled.ino]
2018-06-12 plans for burn night
    [witchlights-fastled.ino]
2018-06-15 Minor improvements to no_idle avoidance logic
    [witchlights-fastled.ino]
2018-06-25 Also found minor bug in CheckForTermination()
    [witchlights-fastled.ino]
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2023-06-20 The code compiles, uploads over wifi, and the esp completes setup and reports to the serial monitor. Currently the board being used for testing doesn't then display the animation. But then when I tes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
    [witchlights-fastled.ino]
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2023-06-27 AvoidNoIdle seems to be bad?
    [witchlights-fastled.ino]
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
